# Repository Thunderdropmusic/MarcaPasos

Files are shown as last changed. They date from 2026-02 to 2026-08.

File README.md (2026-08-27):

# MARCAPASOS - THE ARDUINO MIDI SEQUENCER
Marcapasos_banner

🔗 Consulta la documentación técnica completa y detallada en mi página de Notion:

https://www.notion.so/MARCAPASOS-SEQUENCIADOR-MIDI-2cebd5980807801b87b1fa9e6536f0fe?source=copy_link
<!-- START_NOTION -->

Este es un proyecto realizado para la asignatura Laboratorio de Sonido II en la Esmuc. 

El Marcapasos es un secuenciador MIDI que funciona como un secuenciador analógico modular sin las limitaciones que supone tener todos los módulos que requiere un sintetizador modular.

Puedes encontrar como funciona cada apartado dando clic en los enlaces de las prestaciones.

Las prestaciones son todas aquellas características que me gustaría añadir en algún momento al dispositivo, aunque no sean posibles en los cuatro meses de la asignatura.

# **PRESTACIONES**

- [ ] **SINCRONIZACIÓN CON EL DAW**
  - [x] **Tempo**
  - [ ] Posición
  - [x] [**Subdivisiones:**](https://www.notion.so/36fbd598080780d9bde0de2cc4f7dc47)
    - [x] **Binarias **
    - [x] **Ternarias**
    - [x] **Compuestas**
  - [ ] Ligado de los pasos
  - [x] [**Decidir si recibe MIDI_CLOCK o si lo envía**](https://www.notion.so/36fbd598080780c8bdfbc918d2e3e9ef)
- [ ] **PASOS EDITABLES**
  - [x] [**Muteado de los pasos**](https://www.notion.so/36fbd598080780419057ef35fa2849cf)
  - [x] [**Edición del número de pasos (Max de 16)**](https://www.notion.so/36fbd59808078011a2aadc185fa75882)
  - [x] **Extender la secuencia a 32 mediante los botones de slot**
  - [ ] Extensión del paso
- [x] **CONTROL**
  - [x] **Potenciómetros para cada valor de la secuencia**
  - [x] [**Pulsadores para el muteado y desmuteado**](https://www.notion.so/36fbd598080780419057ef35fa2849cf)
  - [x] **Botones de control de la pantalla**
  - [x] [**Escoger fácilmente la octava de cada una de las notas**](https://www.notion.so/36fbd598080780fea1caeed5433170bc)
  - [x] [**Escoger fácilmente la velocity de cada una de las notas**](https://www.notion.so/36fbd598080780eea508ef71374ae587)
  - [x] Transportar según nota de entrada de otro controlador
  - [x] [**Mapear posición del potenciómetro a una escala**](https://www.notion.so/36fbd598080780b19d55cec38a8eafa3)
  - [x] **Botones para iniciar y parar la secuencia con leds que lo visualicen**
- [ ] **CONEXIONES**
  - [x] **USB**
  - [ ] Opcional DIN4
- [x] **ENVÍO**
  - [x] **Notas a diferentes alturas**
  - [x] [**Notas con diferentes velocidades**](https://www.notion.so/36fbd598080780eea508ef71374ae587)
  - [x] [**Control Change**](https://www.notion.so/36fbd598080780c189a0f2511ea4e083)
  - [x] [**Enviar varias secuencias a la vez**](https://www.notion.so/36fbd59808078066aa01e511496fedfd)
- [x] [**PRESETS**](https://www.notion.so/36fbd59808078064a17fe55298546050)
  - [x] **Guardar las secuencias y los patterns en una SD**
  - [x] **Guardar las secuencias en slots para cargarlas automaticamente**
# **MATERIAL NECESARIO**

1. x1 Arduino mega
1. x1 Pantalla I2C 20x4
1. x16 Potenciometros
1. x16 Botones para los mutes
1. x5 Botones para el play/stop de las secuencias
1. x3 Botones de control
1. 1x Encoder
1. x1 Mega Proto Shield
1. x40 Cables Dupont Macho-Macho
1. x40 Cables Dupont Macho-Hembra
1. x5 Resistencias para los leds
1. X5 Leds
1. Ribbon con clavija FC10P
1. Cables Dupont x50
# **SOFTWARE**

1. [LoopMidi](https://www.tobias-erichsen.de/software/loopmidi.html)
1. [HairLessMidi](https://projectgus.github.io/hairless-midiserial/)
1. [MIDI-OX](http://www.midiox.com/)
# **BIBLIOGRAFÍA**

## MIDI

[https://www.prometec.net/midi-conexiones-senales-mensajes/](https://www.prometec.net/midi-conexiones-senales-mensajes/)

[https://www.prometec.net/midi-recibir-manipular-mensajes/](https://www.prometec.net/midi-recibir-manipular-mensajes/)

[https://midi.org/expanded-midi-1-0-messages-list](https://midi.org/expanded-midi-1-0-messages-list)

[https://midi.org/spec-detail](https://midi.org/spec-detail)

[https://projectgus.github.io/hairless-midiserial/](https://projectgus.github.io/hairless-midiserial/)

## ARDUINO

[https://www.pjrc.com/teensy/td_libs_TimerOne.html](https://www.pjrc.com/teensy/td_libs_TimerOne.html)

[https://www.luisllamas.es/curso-arduino-iniciacion/](https://www.luisllamas.es/curso-arduino-iniciacion/)

[https://www.youtube.com/playlist?list=PL4_gPbvyebyH2xfPXePHtx8gK5zPBrVkg](https://www.youtube.com/playlist?list=PL4_gPbvyebyH2xfPXePHtx8gK5zPBrVkg)

[https://naylampmechatronics.com/blog/34_tutorial-lcd-conectando-tu-arduino-a-un-lcd1602-y-lcd2004.html](https://naylampmechatronics.com/blog/34_tutorial-lcd-conectando-tu-arduino-a-un-lcd1602-y-lcd2004.html)

[https://naylampmechatronics.com/blog/35_tutorial-lcd-con-i2c-controla-un-lcd-con-solo-dos-pines.html](https://naylampmechatronics.com/blog/35_tutorial-lcd-con-i2c-controla-un-lcd-con-solo-dos-pines.html)

[https://www.luisllamas.es/arduino-encoder-rotativo/](https://www.luisllamas.es/arduino-encoder-rotativo/)

[https://www.luisllamas.es/4-consejos-para-programar-codigo-mas-limpio-en-arduino/](https://www.luisllamas.es/4-consejos-para-programar-codigo-mas-limpio-en-arduino/)

[https://www.luisllamas.es/tarjeta-micro-sd-arduino/](https://www.luisllamas.es/tarjeta-micro-sd-arduino/)

# **SUBPÁGINAS DEL NOTION**

<!-- END_NOTION -->

esto es un pie de pagina

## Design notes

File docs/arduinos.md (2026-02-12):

# ARDUINOS

Arduino mega 2560 https://es.aliexpress.com/item/1005006332489610.html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

* pines digitales máximos: 52
* pines analógicos máximos: 16

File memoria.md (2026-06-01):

La memoria comienza antes de empezar las clases de la asignatura, pues se me recomendó empezar con tiempo porque el proyecto era bastante grande. 

## 17/01/2026

Primeras pruebas Midi. Se consigue por primera vez recibir mensajes Midi en el Arduino desde el DAW usando la librería Midi.h y el programa Hairless MIDI y se hacen las primeras pruebas de recepción del Midi Clock.

```javascript
#include <MIDI.h>
#include <TimerOne.h>

struct HairlessConfig : public midi::DefaultSettings {
  static const long BaudRate = 115200;
};

MIDI_CREATE_CUSTOM_INSTANCE(HardwareSerial, Serial, MIDI, HairlessConfig);
int tiempo;
volatile boolean notaFuera;
void setup() {
  MIDI.begin(MIDI_CHANNEL_OMNI);
  MIDI.turnThruOff();
}
```

## 3/2/2026

Primera presentación del proyecto 

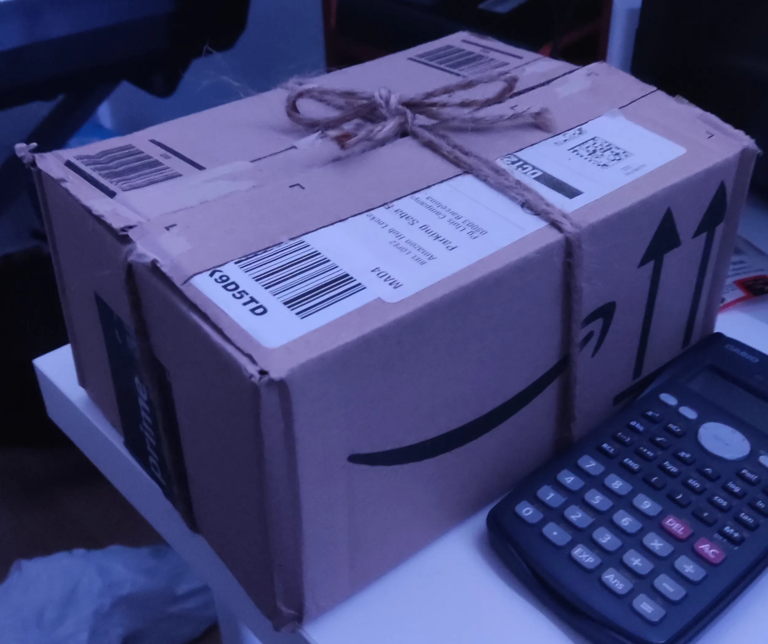
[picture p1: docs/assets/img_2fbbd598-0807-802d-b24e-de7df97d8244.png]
Una caja
<div style="margin-bottom: 20px;"><p style="margin-top: 0px;"><sub><i>Una caja</i></sub></p></div>

## 10/02/2026

Se ha conseguido añadir hasta ocho potenciómetros y se ha empezado a trabajar la programación del muteado de los pasos. Tambien se ha conseguido editar la longitud de la secuencia desde el Arduino:

📄 [Edición del número de pasos (Max de 16)](https://www.notion.so/303bd598080780b78244d991088aca70)

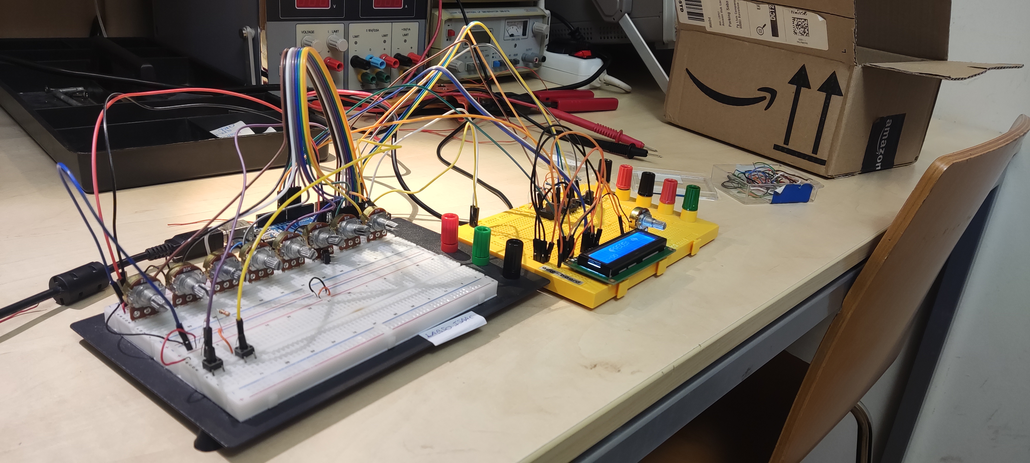
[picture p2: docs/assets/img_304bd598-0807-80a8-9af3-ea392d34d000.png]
Protoboard en la fecha de la memoria
<div style="margin-bottom: 20px;"><p style="margin-top: 0px;"><sub><i>Protoboard en la fecha de la memoria</i></sub></p></div>

## 17/02/2026

Se han añadido 8 botones para mutear cada uno de los potenciómetros independientemente.

📄 [Muteado de los pasos](https://www.notion.so/304bd5980807806a8955d3bfb23b4774)

También, se ha optimizado el código de dibujado de la pantalla para que solo cambie los caracteres que se mueven y no que redibuje todo cada vez que haces un cambio. Esto sobre todo es importante en el visionado de los pasos:

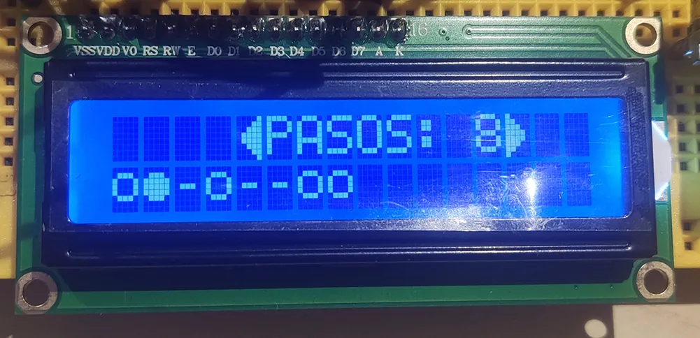
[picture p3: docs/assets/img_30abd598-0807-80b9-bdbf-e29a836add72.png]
Visionado de los pasos
<div style="margin-bottom: 20px;"><p style="margin-top: 0px;"><sub><i>Visionado de los pasos</i></sub></p></div>

```c++
inline void drawSteps() {
  if(mutesValue[nStep]){
    if(mutesValue[nStepAnterior]){
      lcd.setCursor(nStepAnterior, 1);
      lcd.write(byte(5));
      lcd.setCursor(nStep,1);
      lcd.write(byte(5));
    }
    else if(!mutesValue[nStepAnterior]){
      lcd.setCursor(nStepAnterior, 1);
      lcd.write(byte(6));
      lcd.setCursor(nStep,1);
      lcd.write(byte(5));
    }
  }
  else if(!mutesValue[nStep]){
    if(mutesValue[nStepAnterior]){
      lcd.setCursor(nStepAnterior, 1);
      lcd.write(byte(5));
      lcd.setCursor(nStep,1);
      lcd.write(byte(7));
    }
    else if(!mutesValue[nStepAnterior]){
      lcd.setCursor(nStepAnterior, 1);
      lcd.write(byte(6));
      lcd.setCursor(nStep,1);
      lcd.write(byte(7));
      
    }
  }
  nStepAnterior = nStep;
}
```

Se ha empezado también a trabajar la cuantización a escala y poder escoger desde los potenciómetros, notas que pertenezcan a la escala escogida:

```c++
int escalaSeleccionada = 1;
const int escalasNotas[5][13] = {
  {0, 1, 2, 3, 4, 5, 6, 7, 8, 9, 10, 11, 12}, //Escala cromática
  {0, 2, 3, 5, 7, 8, 10, 12, 0, 0, 0, 0, 0}, //Escala menor Natural
  {0, 2, 4, 5, 7, 9, 11, 12, 0, 0, 0, 0, 0}, //Escala Mayor
  {0, 2, 4, 6, 8, 10, 12, 0, 0, 0, 0, 0, 0}, //Escala de tonos
  {0, 1, 3, 4, 6, 7, 9, 10, 12, 0, 0, 0, 0} //Escala Semitono-tono
};
const int nNotasEscalas[5] = {13, 8, 8, 7, 9};

[...]

  for(int i = 0; i < numPotes; i++){
    int indice = constrain(map(analogRead(potesPin[i]), 1018, 30, 0, nNotasEscalas[escalaSeleccionada] - 1), 0, nNotasEscalas[escalaSeleccionada] - 1);
    int val = escalasNotas[escalaSeleccionada][indice];
```

Tambien se ha empezado a trabajar la gestión de las octavas, pudiendo ahora transportar toda la secuencia octavas hacia arriba y hacia abajo pulsando los botones de mute 1, 2 y 3, 4 respectivamente a la vez:

```c++
      if(mutePulsado[0] && mutePulsado[1] && octava < 9 && tiempoActualMillis - ultimoTiempoBotonMute[0] > 250 && tiempoActualMillis - ultimoTiempoBotonMute[1] > 250){
        octava ++;
        ultimoTiempoBotonMute[0] = tiempoActualMillis;
        ultimoTiempoBotonMute[1] = tiempoActualMillis;
        timeShowOctValue = tiempoActualMillis;
        menuActual = 4;
        updateLCD = true;
      }
      else if(mutePulsado[2] && mutePulsado[3] && octava > 0 && tiempoActualMillis - ultimoTiempoBotonMute[2] > 250 && tiempoActualMillis - ultimoTiempoBotonMute[3] > 250){
        octava --;
        ultimoTiempoBotonMute[2] = tiempoActualMillis;
        ultimoTiempoBotonMute[3] = tiempoActualMillis;
        timeShowOctValue = tiempoActualMillis;
        menuActual = 4;
        updateLCD = true;
      }
      else if(tiempoActualMillis - TiempoPulsadoBotonMute[i] > 100 && tiempoActualMillis - ultimoTiempoBotonMute[i] > 250){
        mutesValue[i] = !mutesValue[i];
        ultimoTiempoBotonMute[i] = tiempoActualMillis;
        updateLCD = true;
```

Tambien se ha organizado la carpeta SRC del GitHub por versiones añadiendo un log por cada una para ver los cambios. Ese log está hecho con gemini pasándole la versión nueva y que analice que cambia con la versión antigua..

## 24/02/2026

Se ha conseguido cambiar los valores de la velocity individualmente pulsando el boton mute y girando el pote, así como cambiar la octava por cada una de las notas de la secuencia convirtiendo los botones en un selector:

📄 [Escoger fácilmente la octava de cada uno de los potenciometros](https://www.notion.so/30cbd5980807801a8d3bca6844b82bbb)

📄 [Escoger fácilmente la velocity de cada una de las notas](https://www.notion.so/313bd5980807800ca0a0ca5a68b020ec)

Se ha hecho una Reunión con el profesor para determinar hacia donde caminar: el siguiente paso es cambiar la manera en la que se detectan los potenciómetros, haciendo una comparativa de los valores reales de los potenciómetros y no de su valor convertido a notas.

Se ha hablado como organizar la construcción de prototipo, en especial de los botones. Se compraran varios paneles pcb para conectar las tierras de los botones.

## 03/03/2026

Se ha reestructurado todo el código, convirtiendo cada archivo .h en una clase con sus variables y sus funciones para mejor entendimiento. De esta manera tenemos los siguientes archivos:

El archivo que más cambios ha presentado ha sido midiProgramming, pues se ha convertido su clase en un objeto para poder ser lanzado varias veces sin depender de arrays y manteniendo los valores de las variables en cada gestión de la secuencia. De esta manera, cada secuencia tiene una cantidad de pasos, una subdivisión y un modo de subdivisión completamente independientes.

Puedes ver como funciona mejor en la siguiente página de notion:

Para ello también, se han convertido las variables de la secuencia (noteValue[], velocityValue[], subdivision] en arrays (los que ya eran arrays, en matrices 2d) donde cada indice son los valores de cada secuencia:

## 11/03/2026

Se ha conseguido implementar definitivamente varias secuencias a la vez con un control de play, stop y un modo de subdivisión completamente independientes, pudiendo escoger secuencias con subdivisión simple y otras compleja. 

También se ha implementado un modo de MidiClock, pudiendo tanto recibirlo y sincronizarse con el DAW o enviarlo y que el propio marcapasos sincronice el DAW. Puedes encontrar más información en la siguiente pagina:

Tambien se ha realizado el trabajo de limpiar el código convirtiendo variables de int a byte para liberar memoria reduciéndola un 15% y una liberación de procesamiento dejando que las tareas pesadas como la pantalla o la lectura de potenciómetros lo haga una sola vez.

## 17/03/2026

Se ha seguido limpiando el código generando funciones para tareas que se realizan en muchos momentos del código, favoreciendo la lectura y la organización. 

Se está trabajando en la incorporación del sistema de envío de mensajes CC. Por cada secuencia, puedes escoger si será una secuencia de notas o una secuencia de automatización.

El funcionamiento será el siguiente. Cada potenciómetro tendrá un valor de 0 a 127 y se realizará una interpolación entre cada uno de los valores de 24 puntos (uno por cada mensaje MidiClock que recibe). Además, tambien se ha añadido la función de poder editar la curva de la interpolación, de manera más exponencial o logarítmica.

La idea futura es que funcione como un clip de automatización donde cada uno de los steps sean los puntos de la automatización y con los mutes vayas activando cada uno de los puntos. 

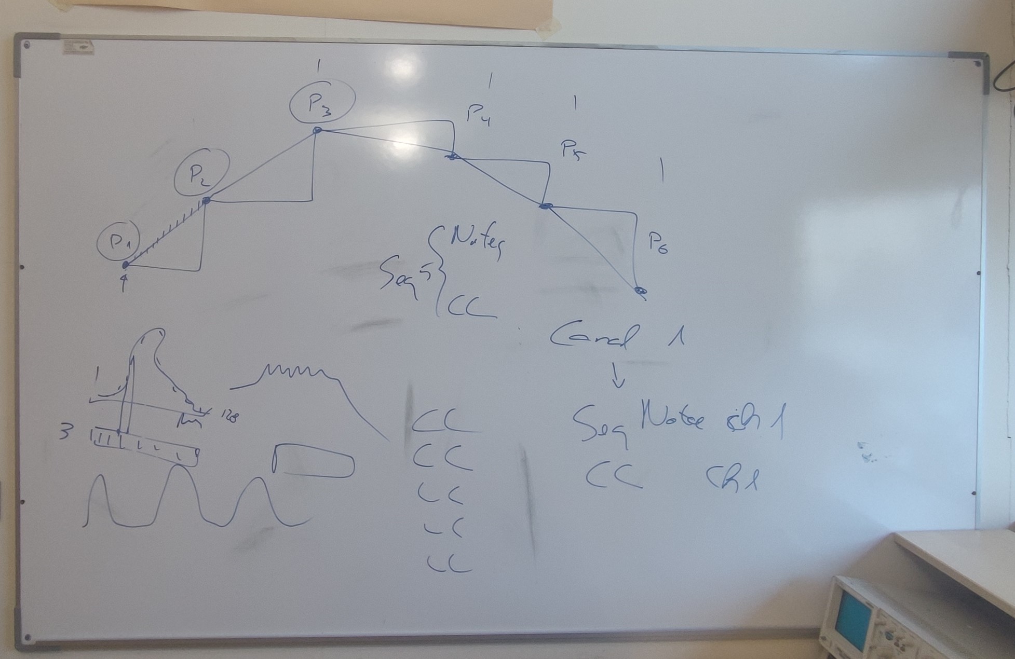
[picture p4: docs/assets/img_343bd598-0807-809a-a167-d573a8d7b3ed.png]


También, se han añadido unos leds para saber que secuencia está reproduciendose:

## 24/03/2026

Con la llegada de nuevos componentes, se ha cambiado la pantalla de 16x2 a una pantalla de 20x4 con chip i2c. 

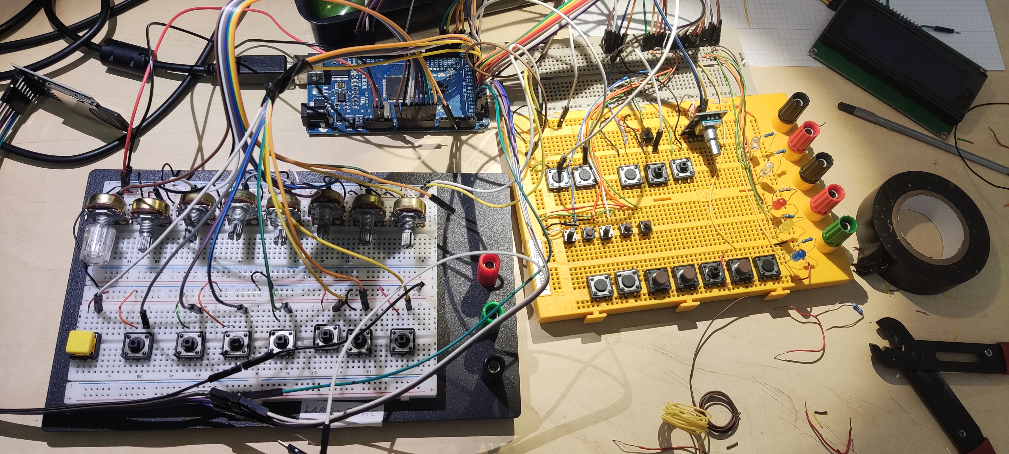
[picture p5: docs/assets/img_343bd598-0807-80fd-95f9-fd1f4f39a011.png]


Tambien, se ha conseguido llevar a cabo la interpolación de los diferentes puntos midi CC, además de poderlo ver de forma intuitiva en la pantalla

## SEMANA SANTA

Se ha construido la caja y la placa para el instrumento y se han hecho los agujeros por donde estarán todos los componentes con los que interactuar

## 14/04/2026 - 21/04/2026

Se han conseguido añadir la opción de transportar la secuencia cuando se envía una nota desde un controlador externo.

Tambien, se ha eliminado uno de los slots para convertirlo en un botón para añadir una extensión a la secuencia.

Se han pegado los componentes a la placa.

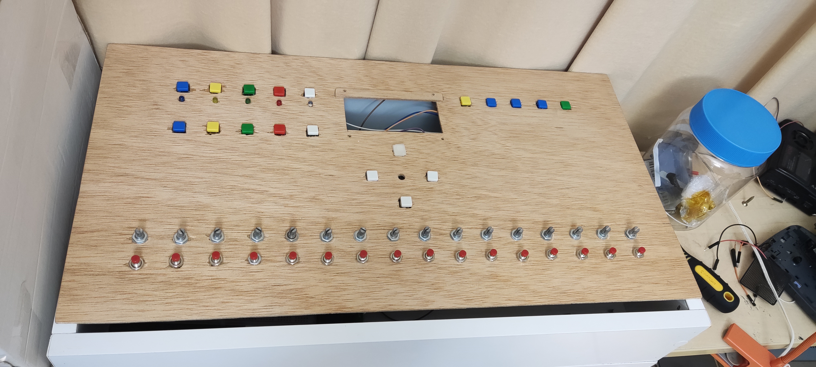
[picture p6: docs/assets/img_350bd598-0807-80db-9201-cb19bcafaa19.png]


## 02/05/2026 - 26/05/2026

En este mes, me he centrado en realizar la soldadura y montaje de la infercifie. Ha quedado de la siguiente manera:

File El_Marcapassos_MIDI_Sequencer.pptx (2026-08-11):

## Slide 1

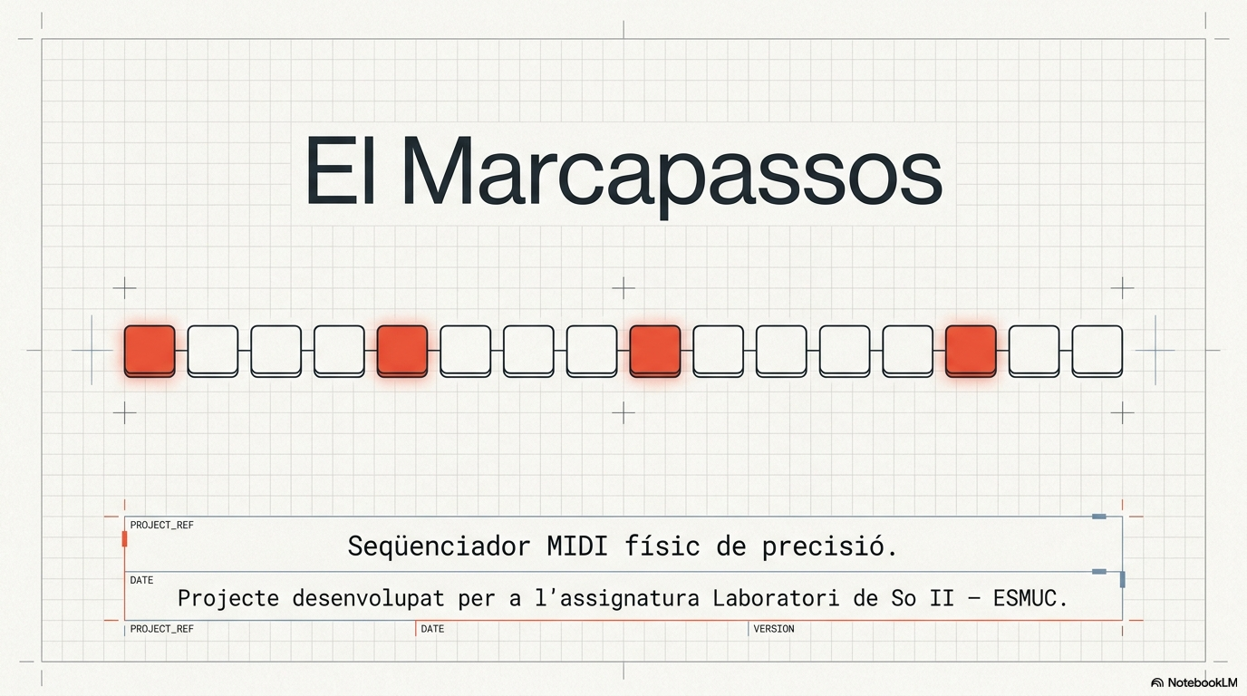
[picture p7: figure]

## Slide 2

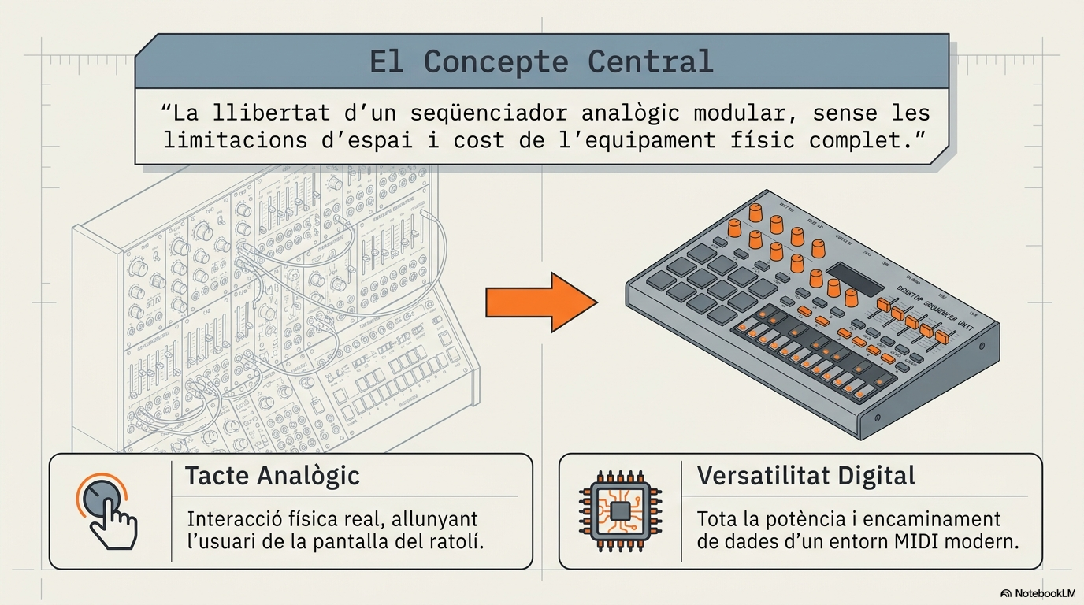
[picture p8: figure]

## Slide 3

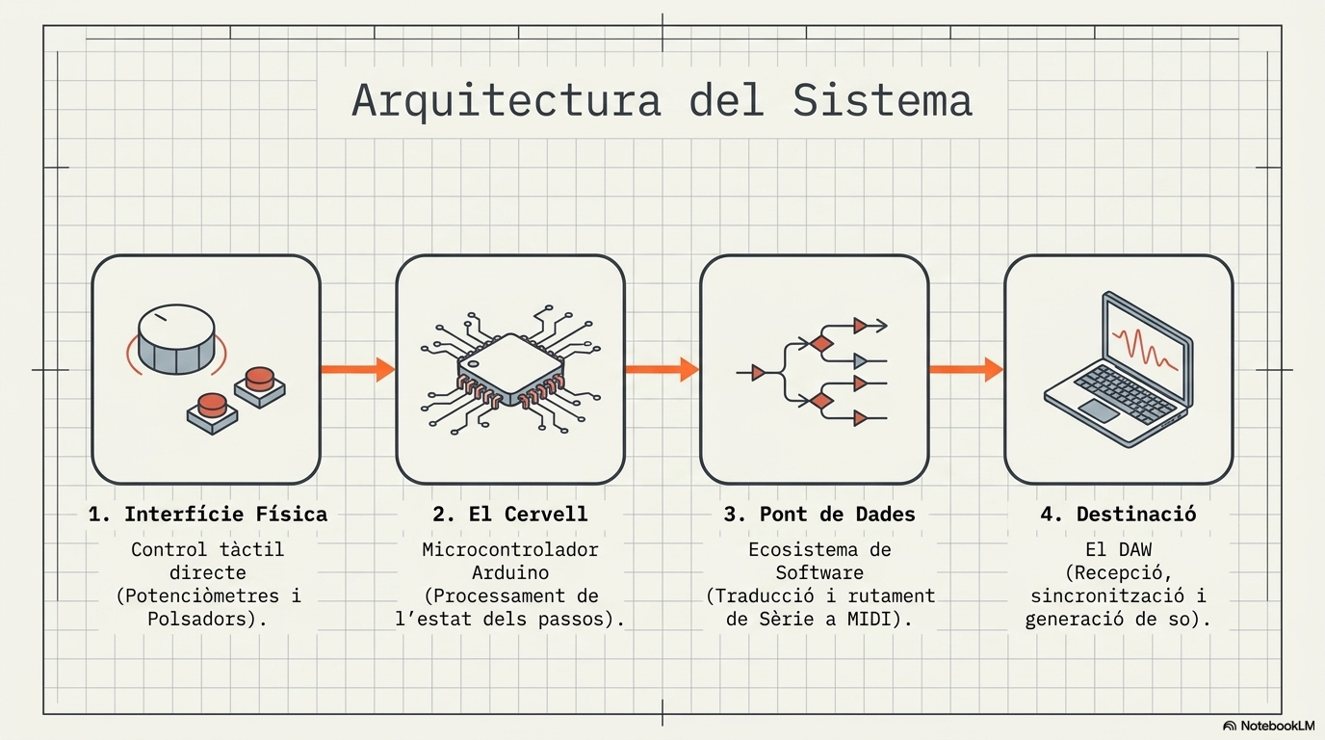
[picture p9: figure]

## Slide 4

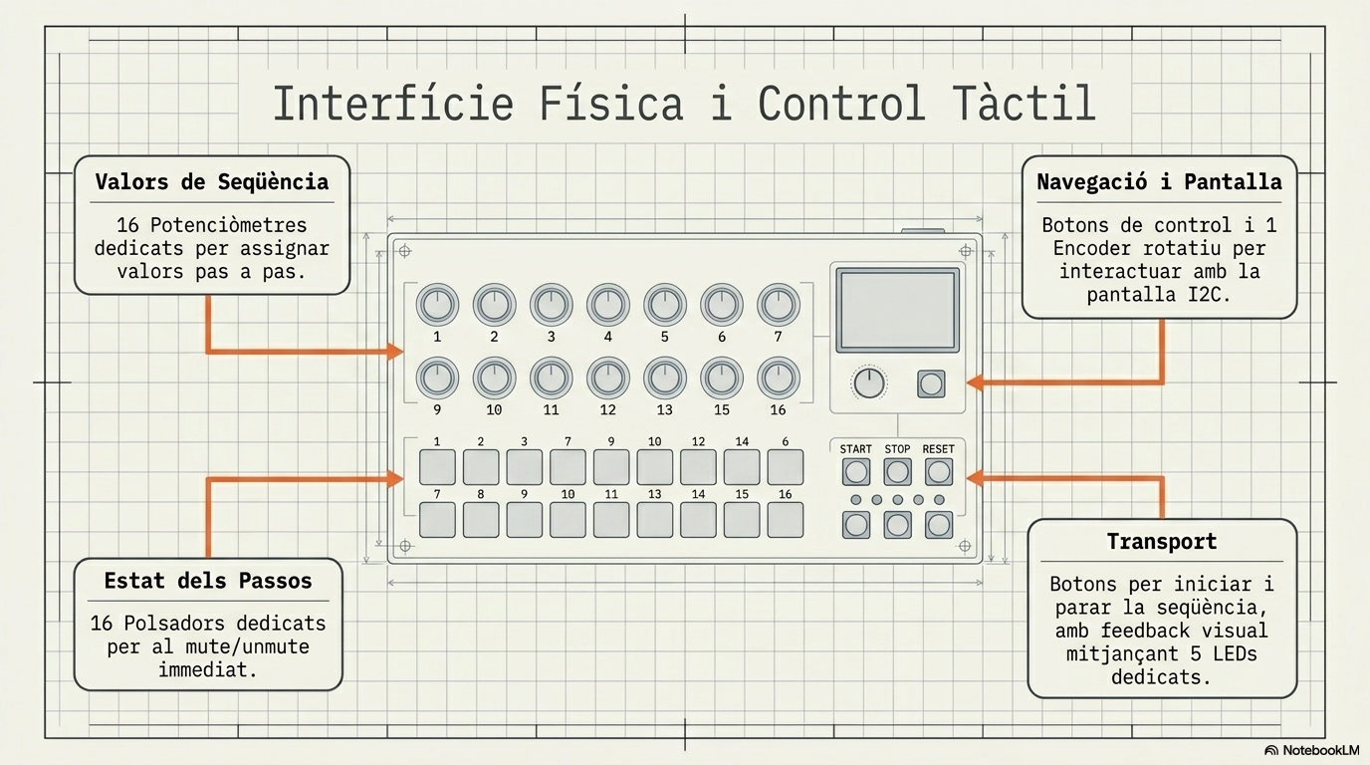
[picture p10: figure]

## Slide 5

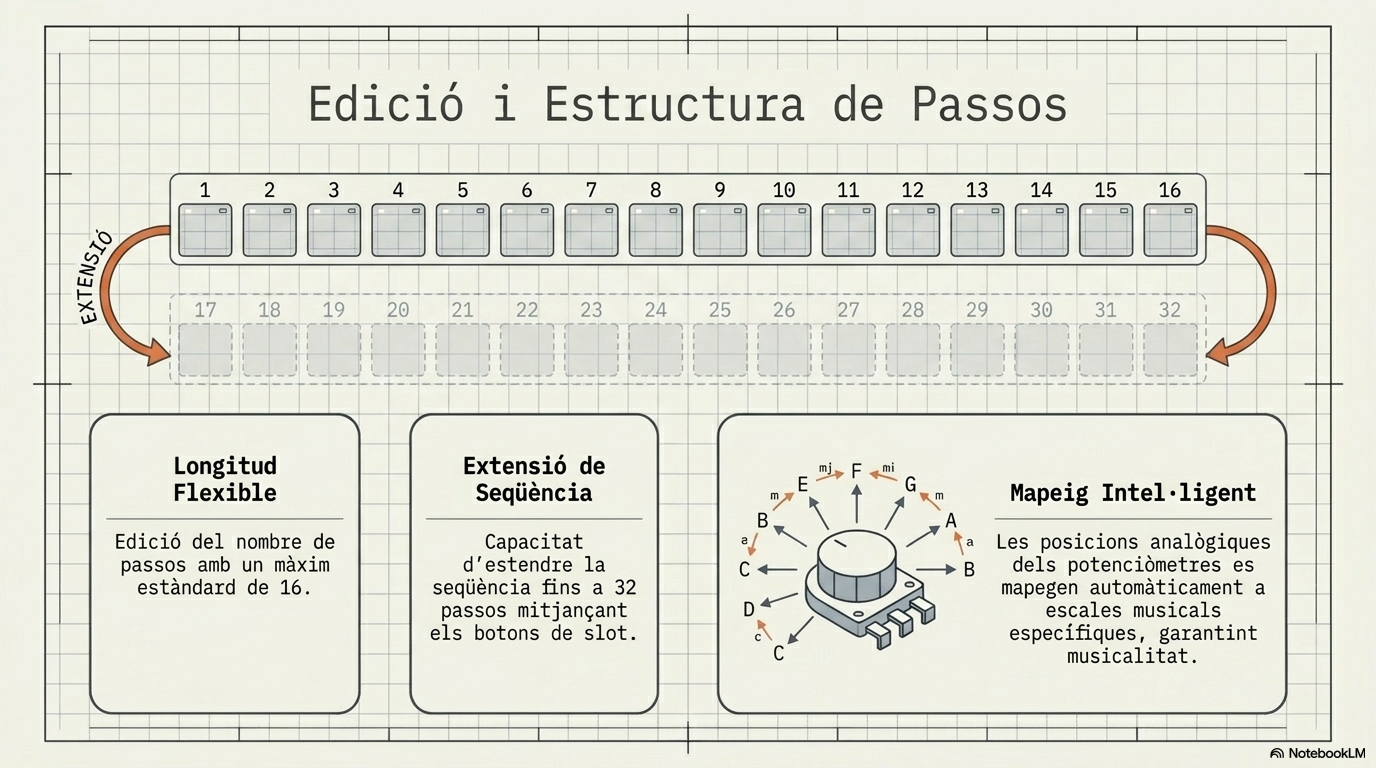
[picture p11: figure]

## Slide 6

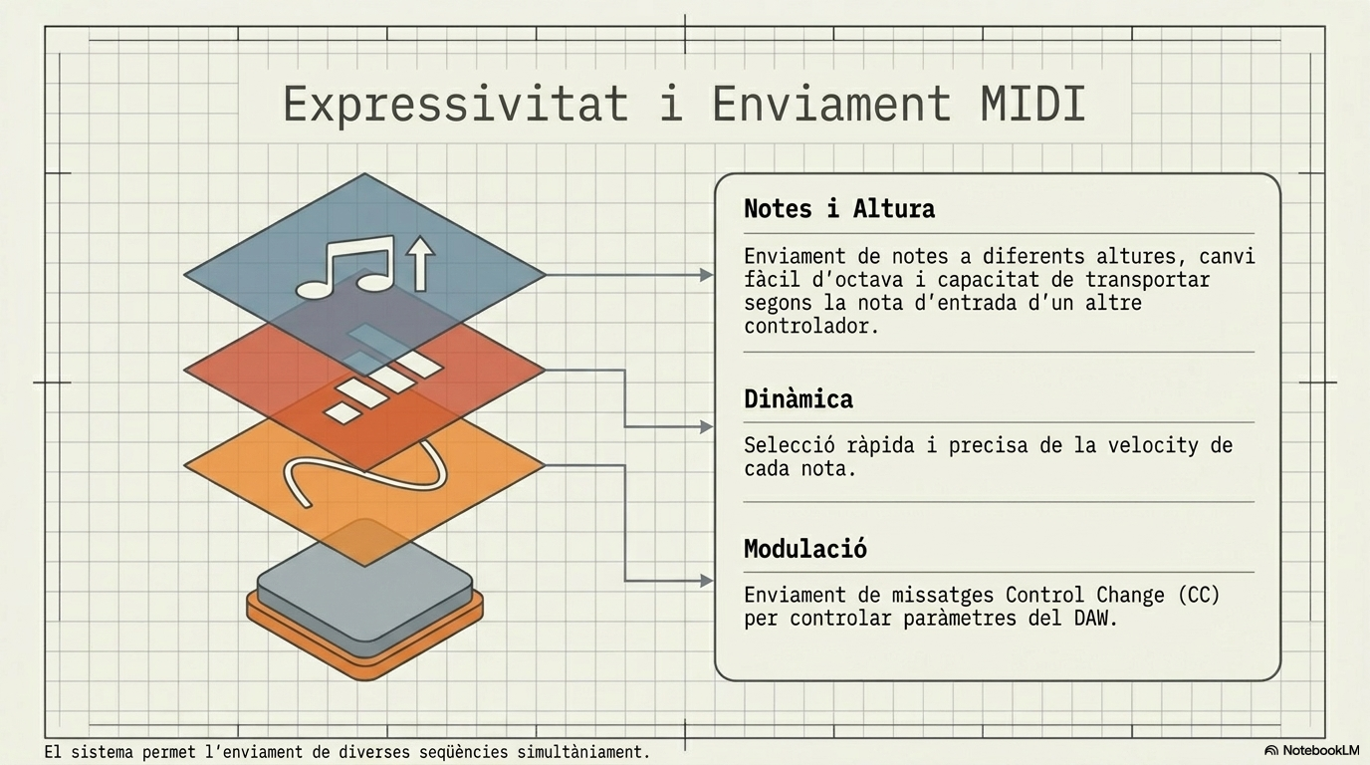
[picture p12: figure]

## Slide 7

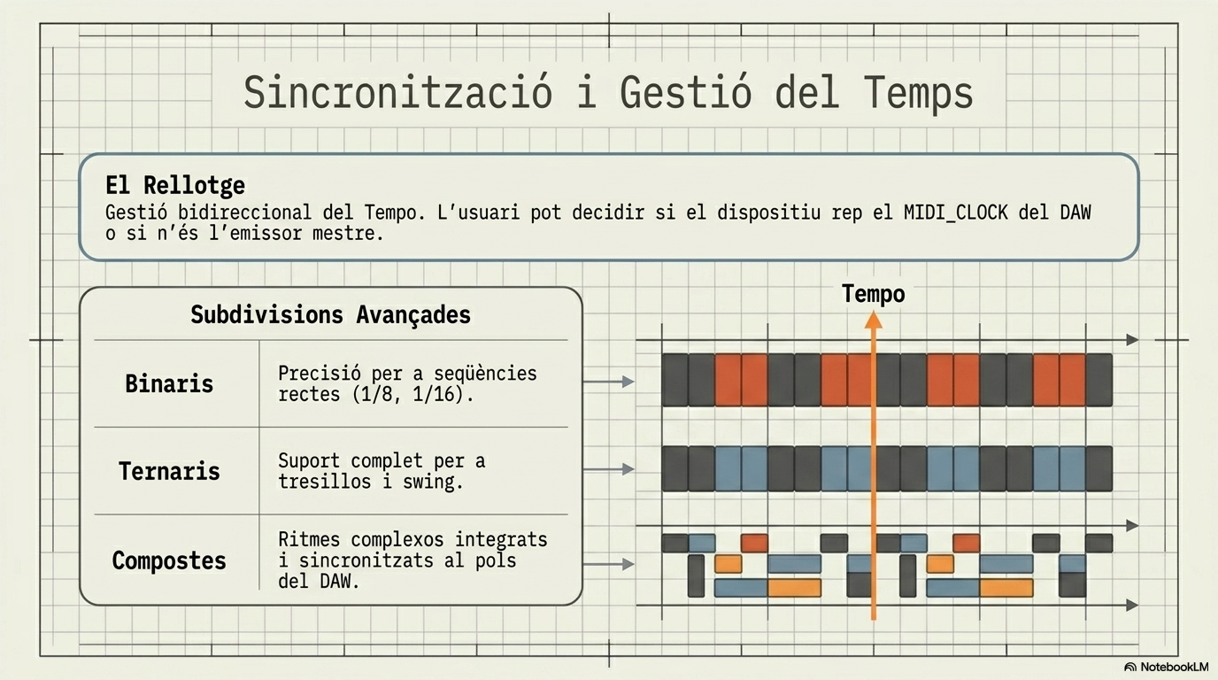
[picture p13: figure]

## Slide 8

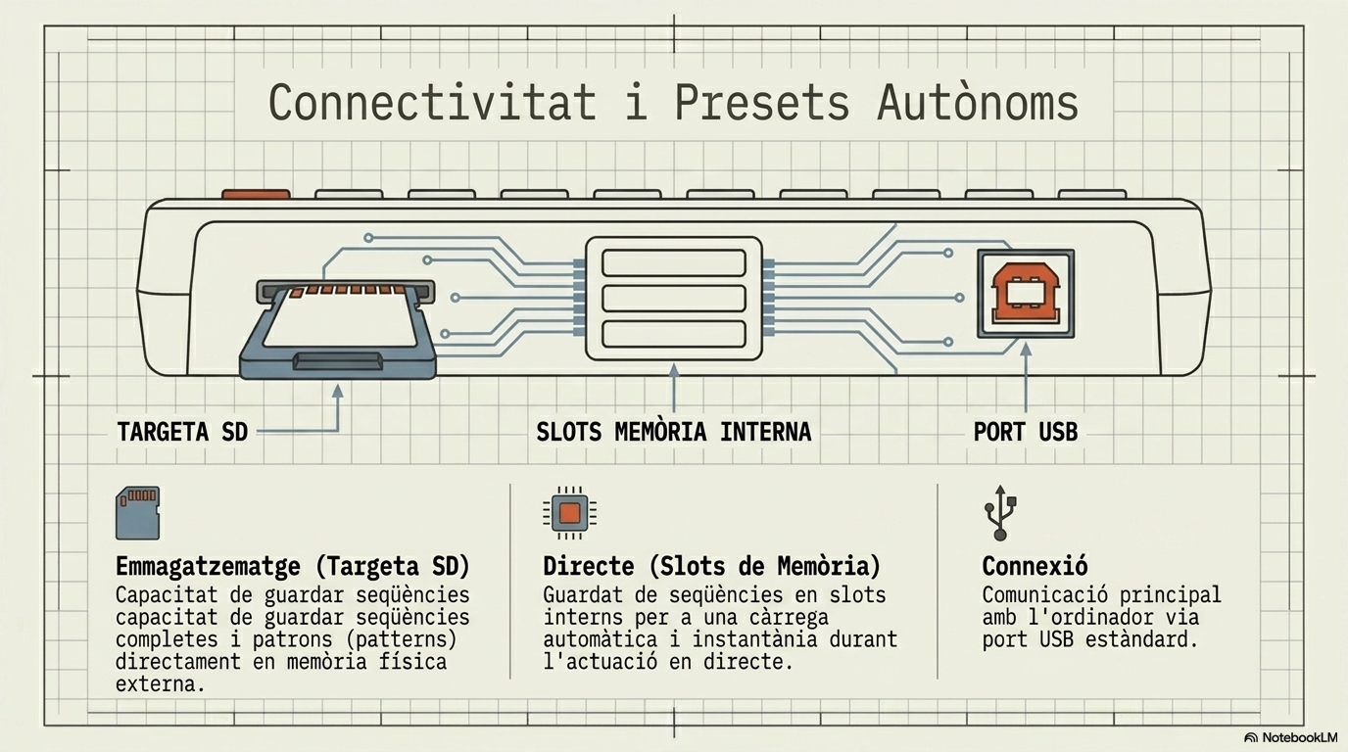
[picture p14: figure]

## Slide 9

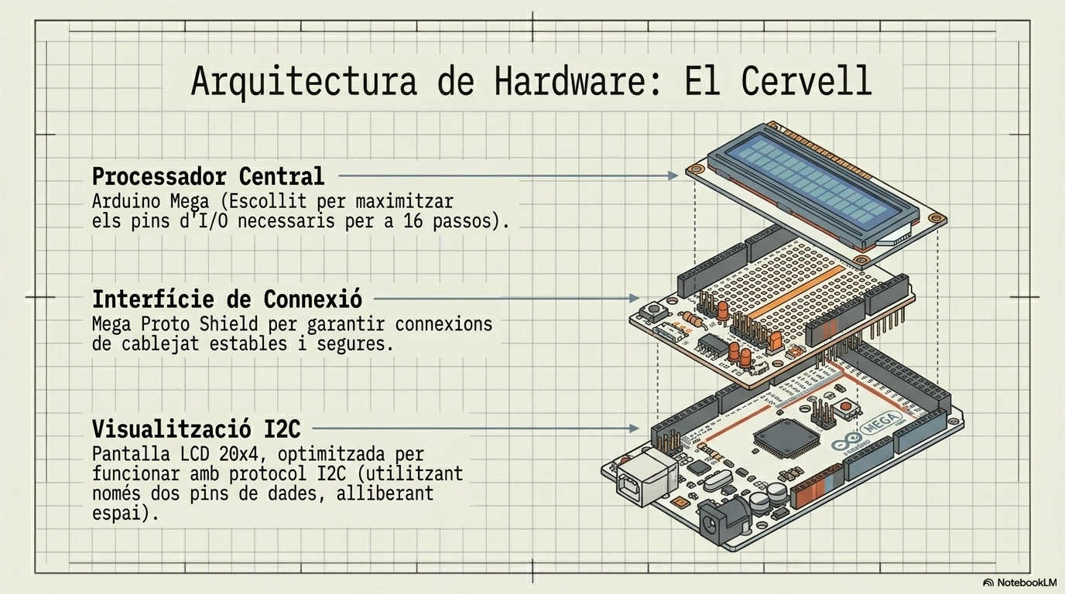
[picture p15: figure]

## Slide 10

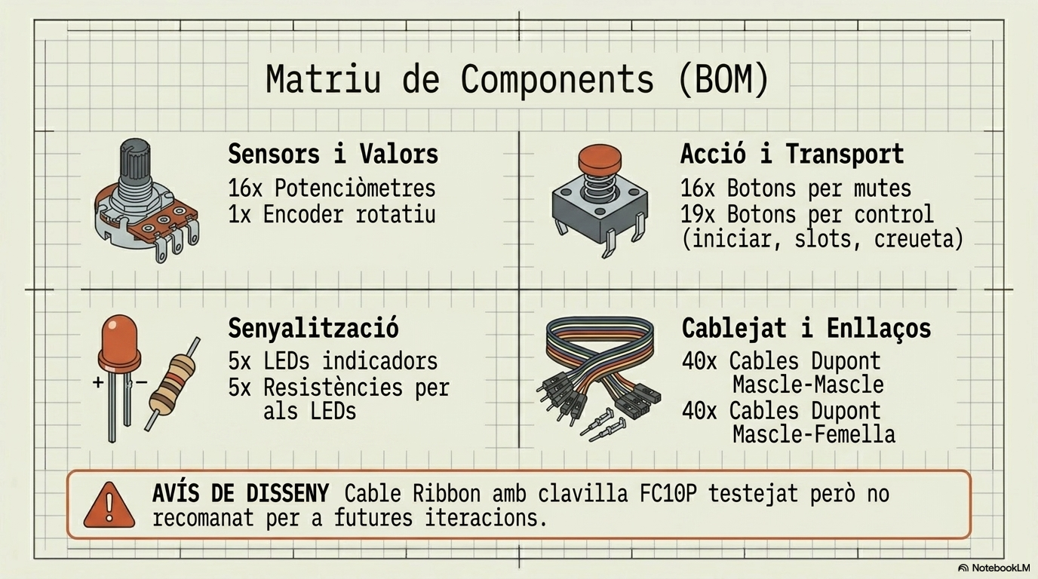
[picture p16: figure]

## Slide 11

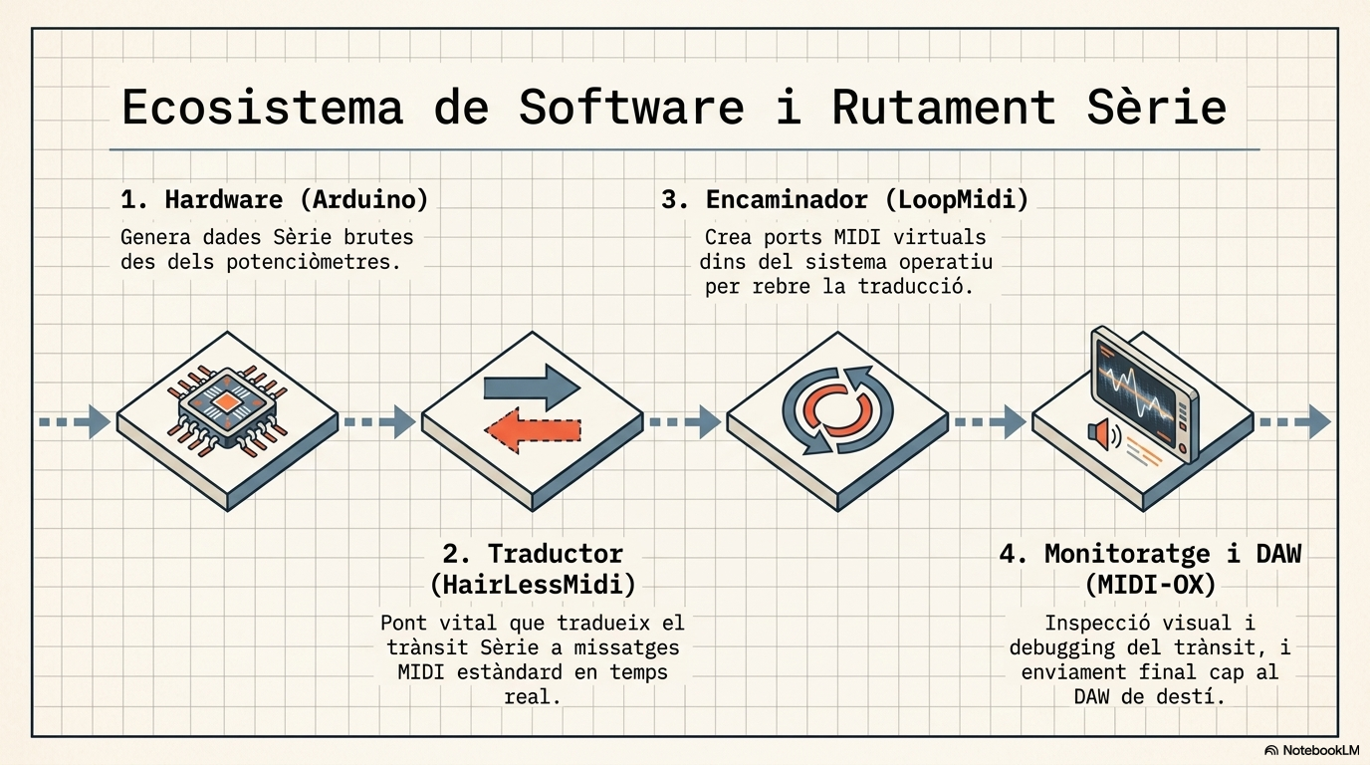
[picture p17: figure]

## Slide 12

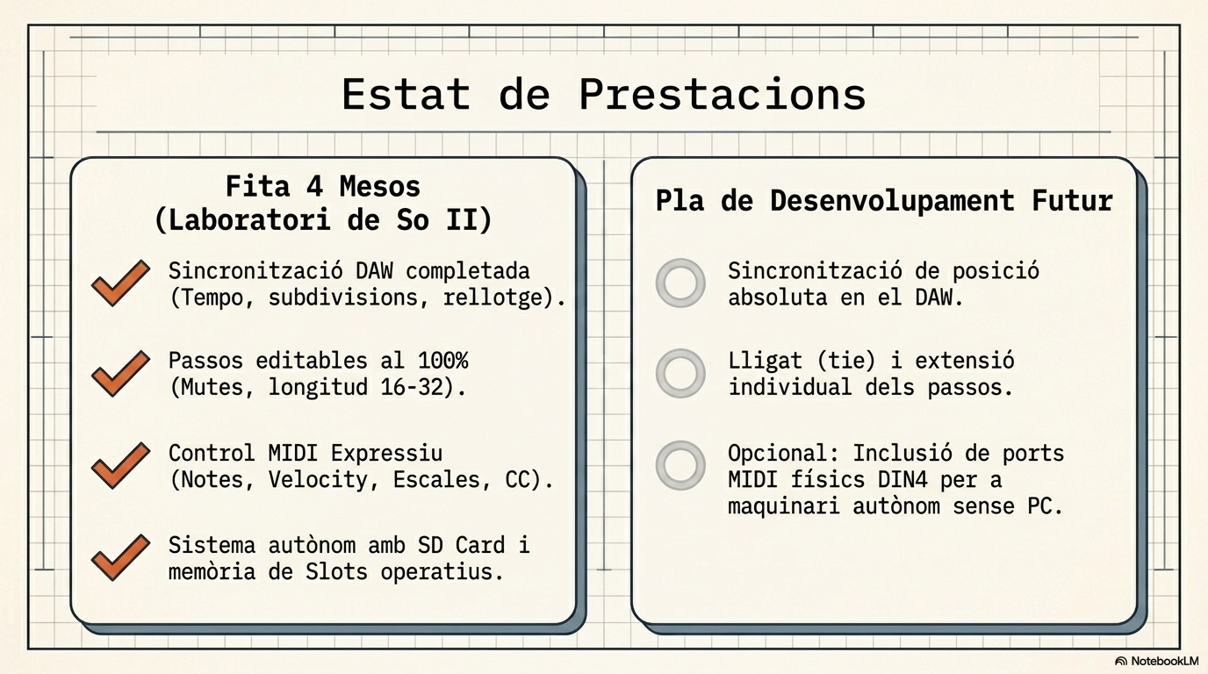
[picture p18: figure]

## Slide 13

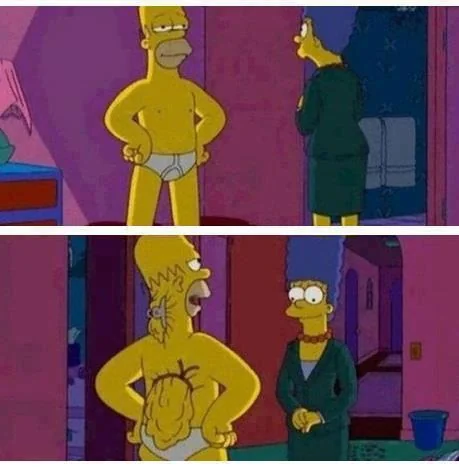
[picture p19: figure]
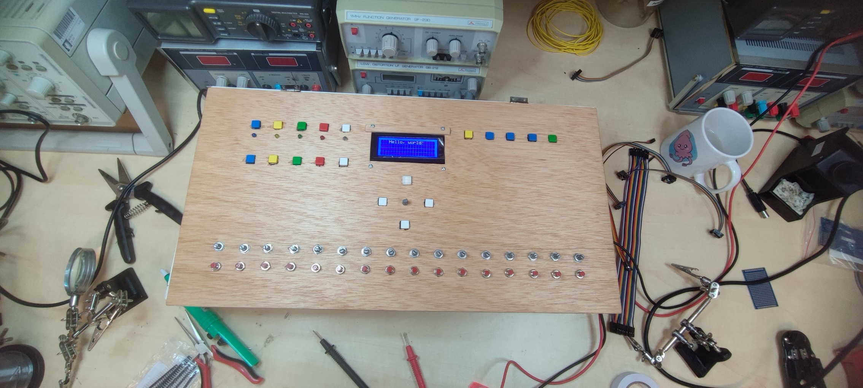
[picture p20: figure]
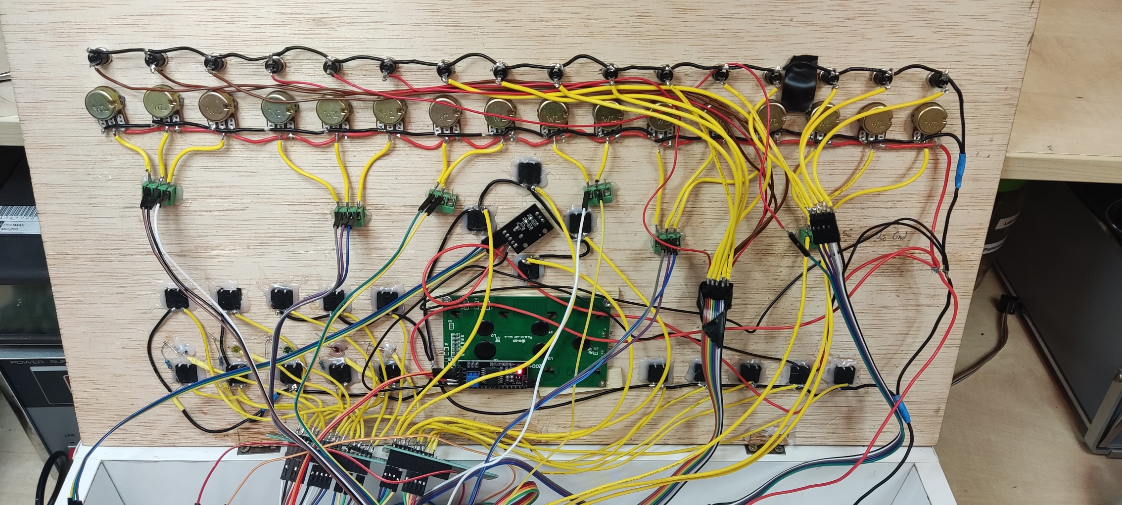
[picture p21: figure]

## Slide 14

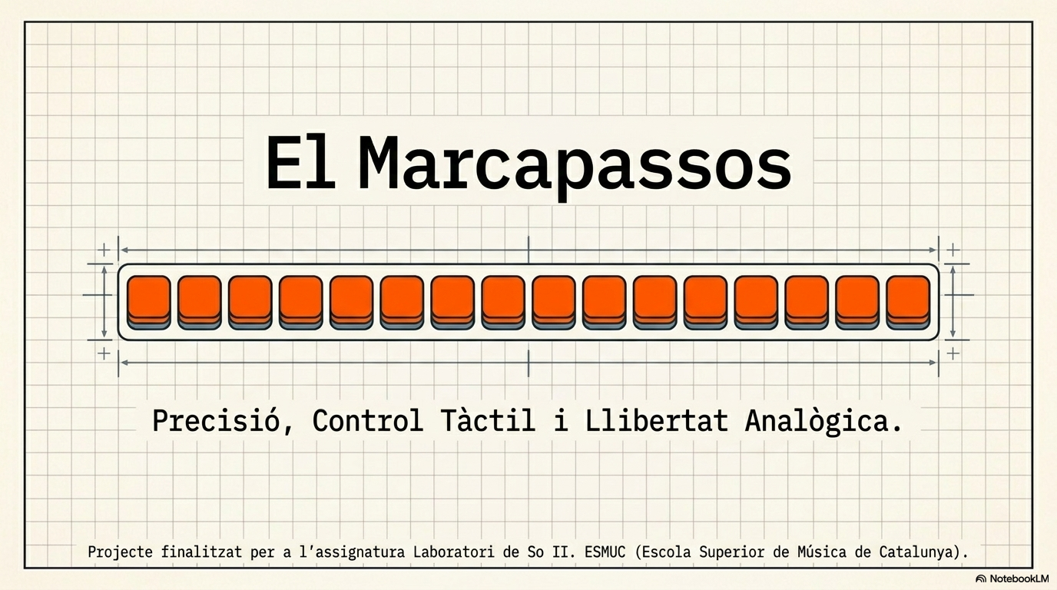
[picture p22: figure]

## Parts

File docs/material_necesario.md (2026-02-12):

# MATERIAL NECESARIO

1. Arduino mega
1. Pantalla ICS 
1. 16 Interruptores
1. 16 potenciometros
1. botones de control
1.

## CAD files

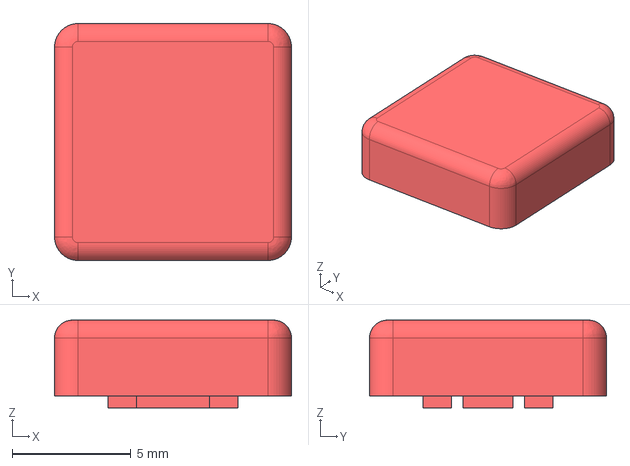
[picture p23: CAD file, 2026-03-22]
Planos/b3f4050-omron-12x12x7-3-button-1.snapshot.3/omrpnb3f4050-cap.step
10.0 x 10.0 x 3.70 mm

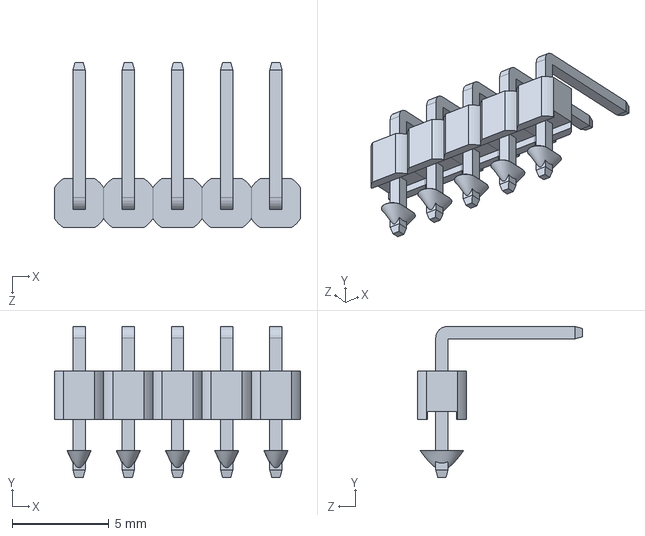
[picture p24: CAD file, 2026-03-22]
Planos/ky-040-enkoder-s-tlacitkem-1.snapshot.1/Kolíková lišta úhlová R2 krátká - 2,54mm.SLDPRT
12.7 x 7.80 x 8.54 mm

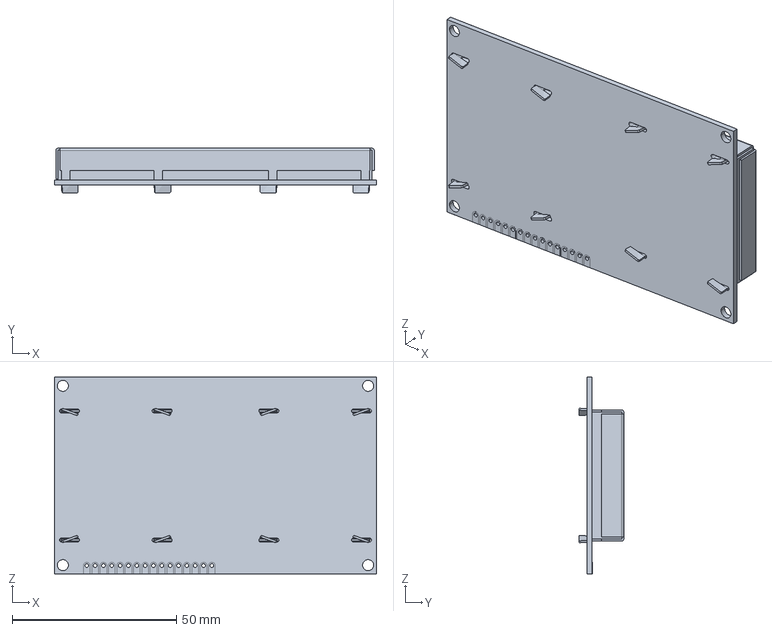
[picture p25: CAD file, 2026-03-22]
Planos/lcd-20x4-display-hd44780-arduiono-raspberry-pi-1.snapshot.1/lcd20x4hd44780.stp
98.1 x 13.7 x 59.9 mm

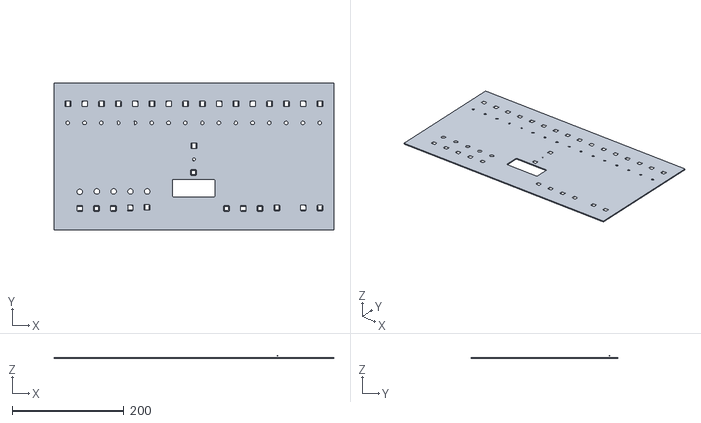
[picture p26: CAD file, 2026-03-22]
Planos/MarcaPasos_Agujeros.stl
500.0 x 261.8 x 5.00

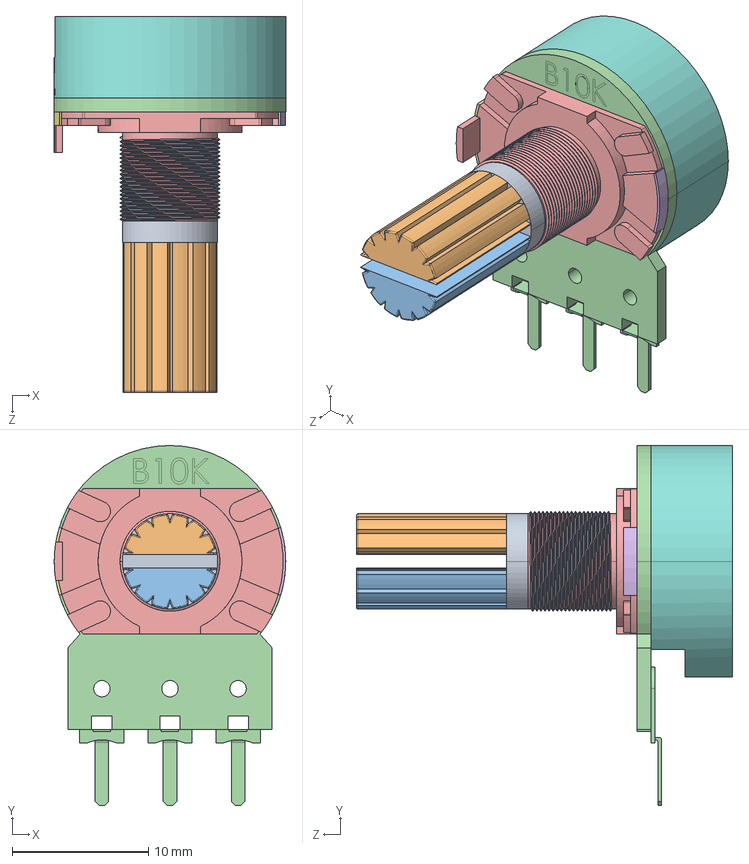
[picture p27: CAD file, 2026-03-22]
Planos/potentiometer-step-1.snapshot.1/PotentiometerB10K.STEP
17.0 x 26.4 x 27.6 mm

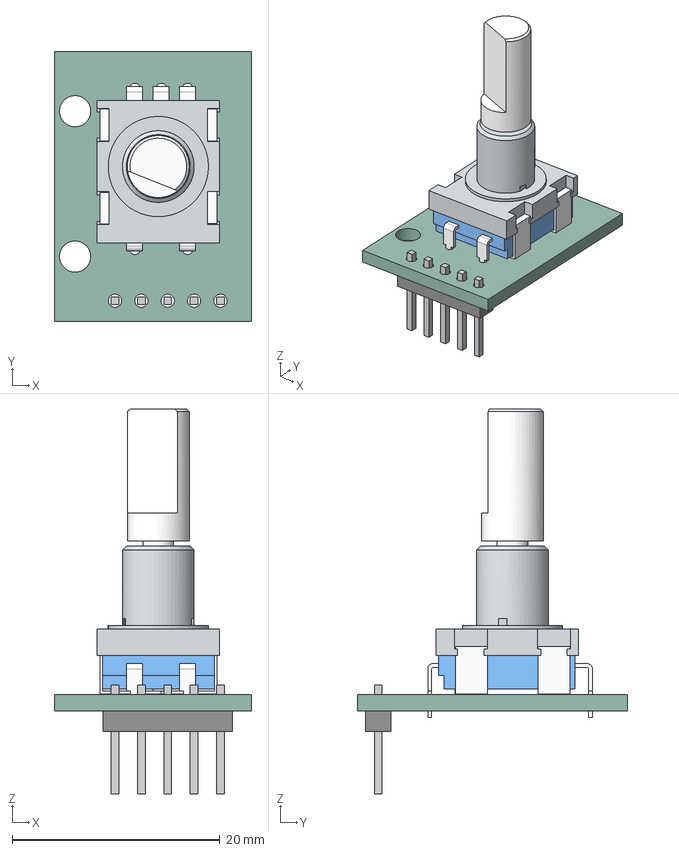
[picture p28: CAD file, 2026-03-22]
Planos/rotary-encoder-arduino-daughter-board-1.snapshot.3/MY_Rotary_encoder.step
19.0 x 26.0 x 37.1 mm
mtg flange
pins_encoder body_2 x 5
shaft_encoder
body_encoder

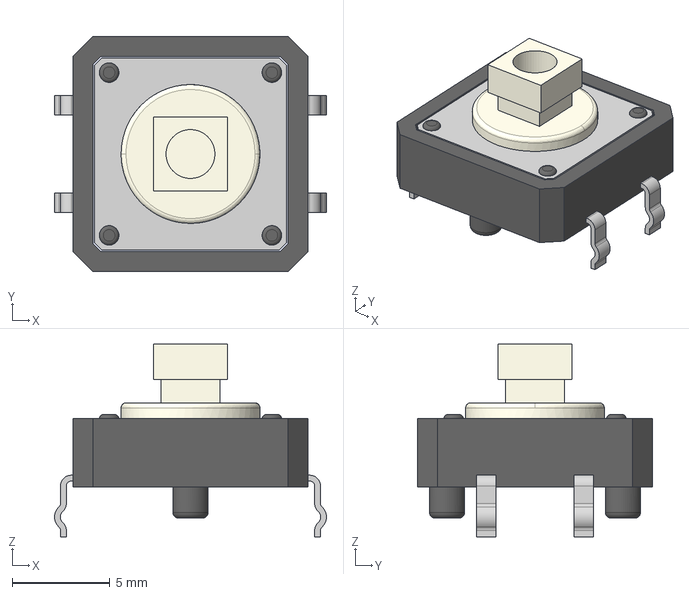
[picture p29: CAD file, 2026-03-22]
Planos/b3f4050-omron-12x12x7-3-button-1.snapshot.3/omrpnb3f4050.step
13.9 x 12.0 x 9.85 mm

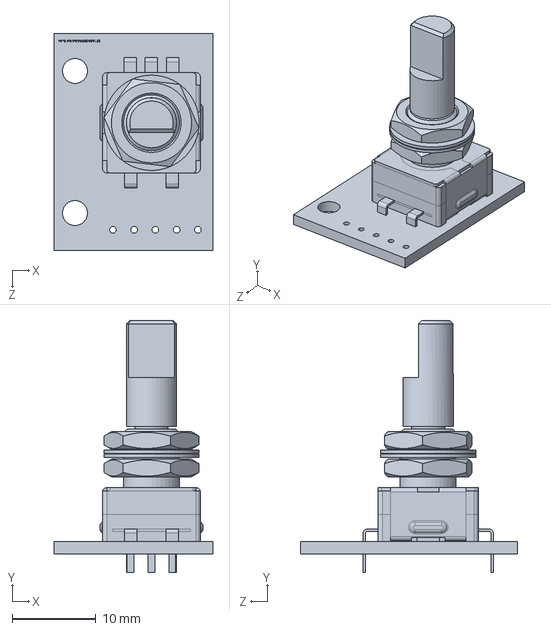
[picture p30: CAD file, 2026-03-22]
Planos/ky-040-enkoder-s-tlacitkem-1.snapshot.1/KY-040 (M495) - Rotační enkodér s ptlačítkem.SLDPRT
19.0 x 30.1 x 26.0 mm

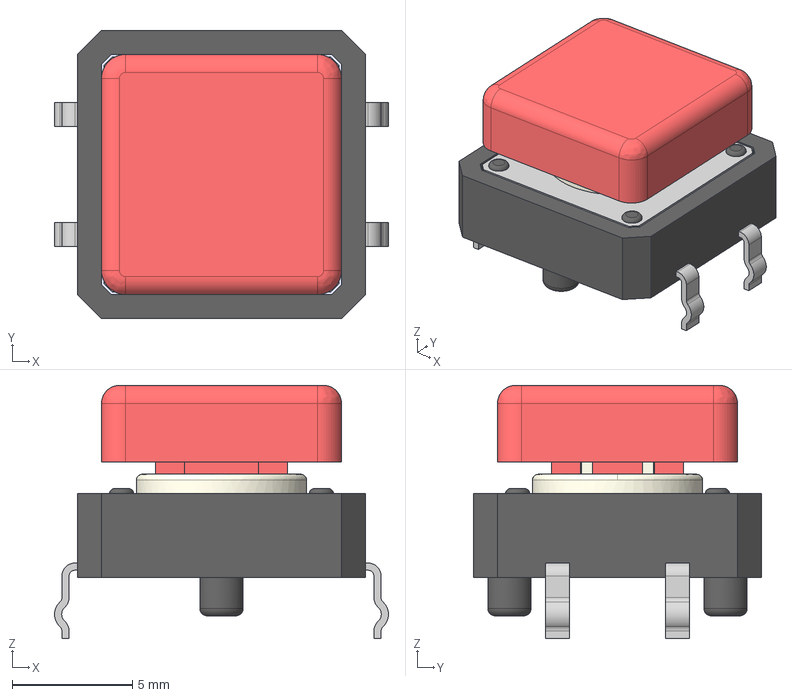
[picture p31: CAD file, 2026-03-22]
Planos/b3f4050-omron-12x12x7-3-button-1.snapshot.3/omrpnb3f4050wCap.step
13.9 x 12.0 x 10.5 mm
Cap
Button

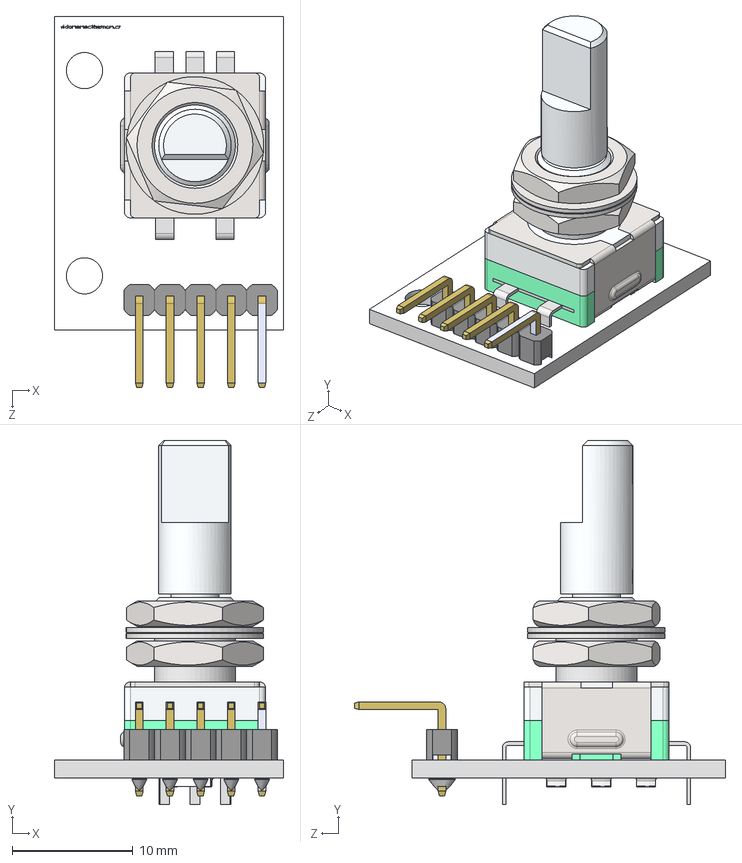
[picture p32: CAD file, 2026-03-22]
Planos/ky-040-enkoder-s-tlacitkem-1.snapshot.1/KY-040 - Rotační enkodér s tlačítkem, 20pulz_ot..STEP
19.0 x 30.1 x 30.8 mm
KY-040 (M495) - Rotaèní enkodér s ptlaèítkem
Kolíková lišta úhlová R2 krátká - 2,54mm_5
SMD rezistory_1206 x 3

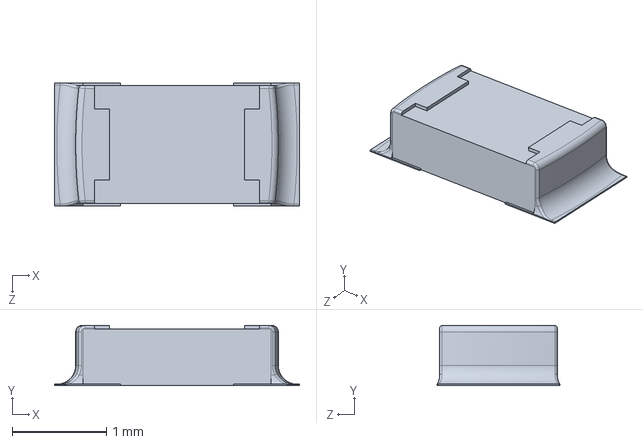
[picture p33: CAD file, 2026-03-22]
Planos/ky-040-enkoder-s-tlacitkem-1.snapshot.1/SMD rezistory.SLDPRT
2.60 x 0.64 x 1.30 mm

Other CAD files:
Planos/ky-040-enkoder-s-tlacitkem-1.snapshot.1/KY-040 - Rotační enkodér s tlačítkem, 20pulz_ot..SLDASM
Planos/lcd-20x4-display-hd44780-arduiono-raspberry-pi-1.snapshot.1/lcd20x4hd44780.igs
Planos/rotary-encoder-22.snapshot.2/Encoder.f3d

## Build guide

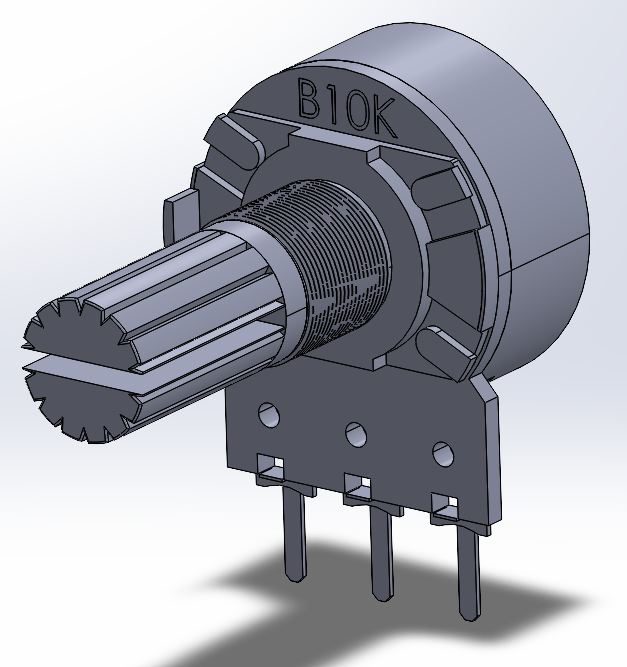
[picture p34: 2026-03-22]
Planos/potentiometer-step-1.snapshot.1/Potenciometro1.png

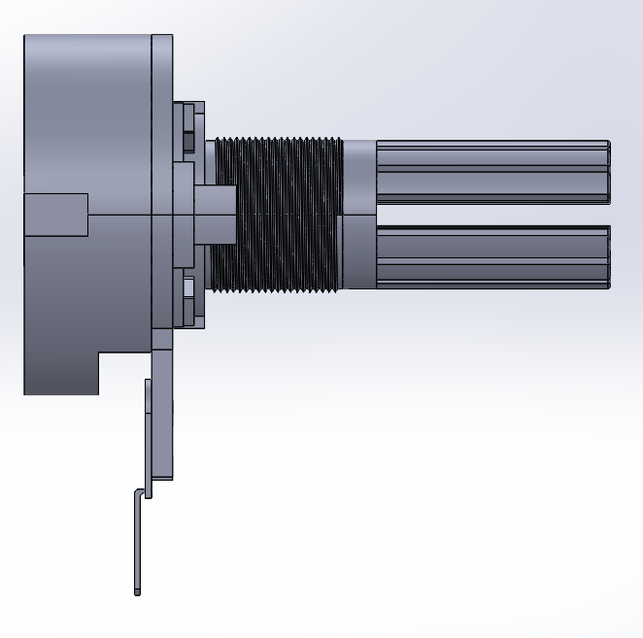
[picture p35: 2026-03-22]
Planos/potentiometer-step-1.snapshot.1/Potenciometro2.png

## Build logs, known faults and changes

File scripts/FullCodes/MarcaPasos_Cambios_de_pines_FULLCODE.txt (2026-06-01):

############################################################
### ARCHIVO: MarcaPasos_Cambios_de_pines.ino
############################################################

#include <MIDI.h>
#include <TimerOne.h>

#include "MidiProgramming.h"
#include "midiInterface.h"
#include "draw_menus.h"
#include "midiPresets.h"
#include "menus_buttons.h"
#include "config.h"

#define SEQ midiProg[presetsUI.indexSequence]

// ==============================================================================
//                INSTACIAS DE LAS LIBRERIAS Y VARIABLES GLOBALES
// ==============================================================================
MIDI_CREATE_CUSTOM_INSTANCE(HardwareSerial, Serial, MIDI, HairlessConfig);

unsigned long tiempoActualMillis;
unsigned long tiempoActualMicros;

volatile bool enviarPulso = false;
byte tareasPesadas;
byte clock;

Sequence* s;
Step* stp;

void syncWithActiveSequence() {
  s = presetsUI.getActiveSequence();
}

void initValuesSeq(){
  for(byte i = 0; i < N_MAX_SEQS; i++){
    p->nSequence[i].escalaSeleccionada = 1;
    p->nSequence[i].noteTone = 0;
    midiUI.mutePulsado[i] = false;
    for(byte j = 0; j < NUM_POTES; j++){
      int lectura = analogRead(midiUI.potesPin[j]);
      byte index = constrain(map(lectura, MAX_POTE_VALUE, MIN_POTE_VALUE, 48, 90), 48, 90);

      midiUI.charNumber[i] = (index <= 9) ? (index + '0') : (index -10 + 'A');

      byte notaEscala = constrain(map(lectura, MAX_POTE_VALUE, MIN_POTE_VALUE, 0, midiProg[i].nNotasEscalas[p->nSequence[i].escalaSeleccionada] - 1), 0, midiProg[i].nNotasEscalas[p->nSequence[i].escalaSeleccionada] - 1);
      p->nSequence[i].steps[j].note = midiProg[i].escalasNotas[p->nSequence[i].escalaSeleccionada][notaEscala];
      int valorCC = constrain(map(lectura, MAX_POTE_VALUE, 30, 0, 127), 0, 127);
      p->nSequence[i].steps[j].ccValue = valorCC;
      p->nSequence[i].steps[j].velocity = 127;
      p->nSequence[i].steps[j].ccSmoothCurve = 6;
      p->nSequence[i].steps[j].octave = 4;
      p->nSequence[i].steps[j].mutes = false;
      p->nSequence[i].steps[j].ccMutes = true;
    }
    for(byte j = 0; j < NUM_POTES; j++){
      int lectura = analogRead(midiUI.potesPin[j]);
      byte index = constrain(map(lectura, MAX_POTE_VALUE, MIN_POTE_VALUE, 48, 90), 48, 90);

      midiUI.charNumber[i] = (index <= 9) ? (index + '0') : (index -10 + 'A');

      byte notaEscala = constrain(map(lectura, MAX_POTE_VALUE, MIN_POTE_VALUE, 0, midiProg[i].nNotasEscalas[p->nSequence[i].escalaSeleccionada] - 1), 0, midiProg[i].nNotasEscalas[p->nSequence[i].escalaSeleccionada] - 1);
      p->nSequence[i].ext_steps[j].note = midiProg[i].escalasNotas[p->nSequence[i].escalaSeleccionada][notaEscala];
      int valorCC = constrain(map(lectura, MAX_POTE_VALUE, 30, 0, 127), 0, 127);
      p->nSequence[i].ext_steps[j].ccValue = valorCC;
      p->nSequence[i].ext_steps[j].velocity = 127;
      p->nSequence[i].ext_steps[j].ccSmoothCurve = 6;
      p->nSequence[i].ext_steps[j].octave = 4;
      p->nSequence[i].ext_steps[j].mutes = false;
      p->nSequence[i].ext_steps[j].ccMutes = true;
    }
    p->nSequence[i].canal = i;
    p->nSequence[i].ccNumber = 48 + i;
    p->nSequence[i].seqMode = 0;
    p->nSequence[i].armed = false;
    p->nSequence[i].steps[0].ccMutes = false;
    p->nSequence[i].steps[4].ccMutes = false;

    p->nSequence[i].subdivMode = 0;
    p->nSequence[i].indexSubdivisiones = 6;   // Pred. Negras
    p->nSequence[i].indComplexSubdivY = 0;  
    p->nSequence[i].indComplexSubdivX = 3;
    p->nSequence[i].nTotalSteps = N_MAX_STEPS;

    p->nSequence[i].ext_subdivMode = 0;
    p->nSequence[i].ext_indexSubdivisiones = 6;   // Pred. Negras
    p->nSequence[i].ext_indComplexSubdivY = 0;  
    p->nSequence[i].ext_indComplexSubdivX = 3;
    p->nSequence[i].ext_nTotalSteps = N_MAX_STEPS;
  }
  p->nSequence[0].armed = true;
}

// Gestion de MIDI y tiempo musical
void setup() {
  drawUI.configurarLCD();
  MIDI.begin(MIDI_CHANNEL_OMNI);
  MIDI.turnThruOff();
  //Serial.begin(9600);
  drawUI.drawLoadProgress(1); // 1
  //Botones Menus
  pinMode(menusUI.pinButton1, INPUT_PULLUP);
  pinMode(menusUI.pinButton2, INPUT_PULLUP);
  pinMode(menusUI.pinButton3, INPUT_PULLUP);
  pinMode(menusUI.pinButton4, INPUT_PULLUP);
  pinMode(menusUI.pinButton5, INPUT_PULLUP);
  pinMode(menusUI.settingsPin, INPUT_PULLUP);

  // Botones octavas
  pinMode(midiUI.pinOctPlus, INPUT_PULLUP);
  pinMode(midiUI.pinOctRest, INPUT_PULLUP);

  drawUI.drawLoadProgress(2); // 3
  // Botones de secuencias
  for(int i = 0; i < N_MAX_SEQS; i++){
    pinMode(midiUI.seqPinsButton[i], INPUT_PULLUP);
  }

  // Botones de control
  pinMode(midiUI.playPinButton, INPUT_PULLUP);
  pinMode(midiUI.stopPinButton, INPUT_PULLUP);  

  // Botones de los slots
  for(int i = 0; i < 3; i++){
    pinMode(presetsUI.slotsPin[i], INPUT_PULLUP);
  }
  pinMode(presetsUI.saveButton, INPUT_PULLUP);
  pinMode(menusUI.extPin, INPUT_PULLUP);

  //SD
  pinMode(53, OUTPUT);
  // Leds
  for(int i = 0; i < N_MAX_SEQS; i++){
    pinMode(midiUI.seqPinLed[i], OUTPUT);
  }
  drawUI.drawLoadProgress(3); // 6

  //Botones Mutes
  for(byte i = 0; i < NUM_MUTES; i++){
    pinMode(midiUI.mutesPin[i], INPUT_PULLUP);
  }
  drawUI.drawLoadProgress(4); // 10

  // Valores predeterminados
  initValuesSeq();
  drawUI.drawLoadProgress(5); // 15
  // Creación caracteres e inicio de la pantalla
  presetsUI.sdInit();
  delay(2000);
}

void funcionInterrupcion() { // Flag para el modo interno del clock
  enviarPulso = true; 
}

void loop() {
  // Funcion para el modo interno del clock
  if (enviarPulso) {
    enviarPulso = false; // Bajamos la bandera
    MIDI.sendRealTime(midi::Clock);
    clock++;
    MidiProgramming::tipoMsgMidi = 0xF8;
    if(clock > 23){clock = 0;}
    for(byte i = 0; i < N_MAX_SEQS; i++){
        midiProg[i].midiSeq();
        midiProg[i].midiNotesOn();
        midiProg[i].midiNotesOff();
    }
    MidiProgramming::tipoMsgMidi = 0;
    return;
  }
  if ((MidiProgramming::tipoMsgMidi == 0xFA || MidiProgramming::tipoMsgMidi == 0xFC) && MidiProgramming::modeMidiClock == 1 && !midiUI.deviceStop) {
    for(byte i = 0; i < N_MAX_SEQS; i++){
      midiProg[i].midiSeq();
    } 
    MidiProgramming::tipoMsgMidi = 0;
  }

  tiempoActualMillis = millis();
  tiempoActualMicros = micros();

  menusUI.checkMenuButtons();
  midiUI.checkMidiButtons();

  // Modo externo del clock
  if(MidiProgramming::modeMidiClock == 0){
    if(MIDI.read()){
      MidiProgramming::tipoMsgMidi = MIDI.getType();
      for(byte i = 0; i < N_MAX_SEQS; i++){
        midiProg[i].midiSeq();
      }
    }
    for(byte i = 0; i < N_MAX_SEQS; i++){
      if(p->nSequence[i].armed && midiUI.devicePlay){
        if(p->nSequence[i].seqMode == 0){
          midiProg[i].midiNotesOn();
        }
        else if(p->nSequence[i].seqMode == 1){
          midiProg[i].CCSend();
        }
      }
      midiProg[i].midiNotesOff();
    }
    MidiProgramming::tipoMsgMidi = 0;
  }

  // Ahorro del buffer
  switch(tareasPesadas){
    case 0:
      midiUI.checkPotes();
      tareasPesadas++;
      break;
    case 1:
      if (drawUI.updateLCD) {
        drawUI.update_LCD();
        drawUI.updateLCD = false;
      }
      tareasPesadas++;
      break;
    case 2:
      presetsUI.readSlotsButtons();
      tareasPesadas = 0;
      break;
  }

  // Reset pantalla
  if(menusUI.menuActual == 0){
    if(SEQ.nStep != drawUI.nStepAnterior){
      drawUI.updateLCD = true;
    }
  } 

  // Clock para salir de la pantalla de potenciómetro
  if (menusUI.menuActual == 3 && (tiempoActualMillis - midiUI.timeShowPotValue >= 1500)) {
    menusUI.menuActual = menusUI.menuAnterior;
    midiUI.poteBlocked[midiUI.movedPoteNumber] = true;
    drawUI.updateLCD = true;
  }
  else if ((menusUI.menuActual == 4 || menusUI.menuActual == 5) && (tiempoActualMillis - midiUI.ultimoTiempoBotonOct >= 1500)) {
    menusUI.menuActual = menusUI.menuAnterior;
    drawUI.updateLCD = true;
  }
  else if ((menusUI.menuActual == 6 || menusUI.menuActual == 7) && tiempoActualMillis - presetsUI.ultimoTiempoBotonPresets >= 1500){
    menusUI.menuActual = menusUI.menuAnterior;
    menusUI.nMenuSettings = 0;
    drawUI.updateLCD = true;
  }
}

############################################################
### ARCHIVO: config.h
############################################################

#ifndef CONFIG_H
#define CONFIG_H

const int MAX_POTE_VALUE = 1018;
const byte MIN_POTE_VALUE = 30;
const byte DEBOUNCE_DELAY_MS = 250;
const byte N_MAX_STEPS = 16;
const byte N_MAX_SEQS = 5;

extern unsigned long tiempoActualMillis;
extern unsigned long tiempoActualMicros;

#endif

############################################################
### ARCHIVO: draw_menus.cpp
############################################################

#include "draw_menus.h"
#include "midiProgramming.h"
#include "midiInterface.h"
#include "menus_buttons.h"
#include "midiPresets.h"
#include "config.h"

#include <Wire.h>
#include <LiquidCrystal_I2C.h>

#define SEQ midiProg[presetsUI.indexSequence]

DrawMenus drawUI;

DrawMenus::DrawMenus()
  : lcd(0x27, 20, 4),

    // Carácteres
    arrowLeft{ B00001, B00011, B00111, B01111, B01111, B00111, B00011, B00001 },
    arrowRight{ B10000, B11000, B11100, B11110, B11110, B11100, B11000, B10000 },
    redonda{ B00000, B00000, B00000, B01110, B10001, B10001, B01110, B00000 },
    blanca{ B00010, B00010, B00010, B00010, B01110, B10010, B10010, B01100 },
    negra{ B00010, B00010, B00010, B00010, B01110, B11110, B11110, B01100 },
    stepOff{ B00000, B00000, B00000, B01110, B00000, B00000, B00000, B00000 },
    stepOn{ B00000, B01110, B10001, B10001, B10001, B01110, B00000, B00000 },
    stepPass{ B00000, B01110, B11111, B11111, B11111, B01110, B00000, B00000 },

    ccLevel0{ 0, 0, 0, 0, 0, 0, 0, 31 },  //Abajo
    ccLevel1{ 0, 0, 0, 0, 0, 0, 31, 31 },
    ccLevel2{ 0, 0, 0, 0, 0, 31, 31, 31 },
    ccLevel3{ 0, 0, 0, 0, 31, 31, 31, 31 },
    ccLevel4{ 0, 0, 0, 31, 31, 31, 31, 31 },
    ccLevel5{ 0, 0, 31, 31, 31, 31, 31, 31 },
    ccLevel6{ 0, 31, 31, 31, 31, 31, 31, 31 },  // Casi arriba

    subdivisionesCharArray{ "1/8", "1/6", "1/4", "1/3", "1/2", "3/2", "1/1", "3/4", "2/1", "3/8", "4/1" },
    subdivisionesComplejasNumChar{ " 5", " 7", " 9", "11", "13", "15" },
    subdivisionesComplejasDenChar{ byte(2), byte(3), byte(4) },
    charEscalasNotas{ "C", "C#", "D", "D#", "E", "F", "F#", "G", "G#", "A", "A#", "B", "C" },
    nombreEscalas{ "Chromatic", "Natural Minor", "Natural Major", "Tone Scale", "Semitone-Tone" } {
  updateLCD = true;
  nAnteriorScreen = 999;
}

// ==============================================================================
//                                FUNCIONES UTILES
// ==============================================================================

void DrawMenus::syncWithActiveSequence() {
  s = presetsUI.getActiveSequence();
  
  stp = menusUI.editExtension ? s->ext_steps : s->steps;
  curTotalSteps = menusUI.editExtension ? s->ext_nTotalSteps : s->nTotalSteps;
  curSubdivMode = menusUI.editExtension ? s->ext_subdivMode : s->subdivMode;
  curIndSubdiv  = menusUI.editExtension ? s->ext_indexSubdivisiones : s->indexSubdivisiones;
  curindComplexSubdivY = menusUI.editExtension ? s->ext_indComplexSubdivY : s->indComplexSubdivY;
  curindComplexSubdivX = menusUI.editExtension ? s->ext_indComplexSubdivX : s->indComplexSubdivX;

}

void DrawMenus::configurarLCD() {
  lcd.init();
  Wire.setClock(400000);
  lcd.backlight();
  splashScreen();
}

void DrawMenus::printAt(byte x, byte y, byte var) {
  lcd.setCursor(x, y);
  lcd.print(var);
}

void DrawMenus::printAt(byte x, byte y, char text) {
  lcd.setCursor(x, y);
  lcd.print(text);
}

void DrawMenus::printAt(byte x, byte y, const char* text) {
  lcd.setCursor(x, y);
  lcd.print(text);
}

void DrawMenus::writeAt(byte x, byte y, byte numByte) {
  lcd.setCursor(x, y);
  lcd.write(numByte);
}

// ==============================================================================
//                           CARACTERES PERSONALIZADOS
// ==============================================================================

void DrawMenus::charactersMenu1() {
  lcd.createChar(0, arrowLeft);
  lcd.createChar(1, arrowRight);
  lcd.createChar(2, redonda);
  lcd.createChar(3, blanca);
  lcd.createChar(4, negra);
  lcd.createChar(5, stepOff);
  lcd.createChar(6, stepOn);
  lcd.createChar(7, stepPass);
}

void DrawMenus::charactersMenu2() {

  lcd.createChar(0, ccLevel0);
  lcd.createChar(1, ccLevel1);
  lcd.createChar(2, ccLevel2);
  lcd.createChar(3, ccLevel3);
  lcd.createChar(4, ccLevel4);
  lcd.createChar(5, ccLevel5);
  lcd.createChar(6, ccLevel6);
}

// ==============================================================================
//                           FUNCIONES DE DIBUJADO
// ==============================================================================

void DrawMenus::update_LCD() {
  syncWithActiveSequence();
  switch (menusUI.menuActual) {
    case 0: drawMenuNotes(); break;
    case 1: drawMenuCC(); break;
    case 2: drawMenuSettings(); break;
    case 3: drawScreenPotes(); break;
    case 4: drawScreenOctavas(); break;
    case 5: drawScreenTodasOctavas(); break;
    case 6: drawLoadPreset(presetsUI.nSlot); break;
    case 7: drawConfirmationScreen(); break;
  }
  updateLCD = false;
  interrupts();
  updateValues = false;
}

// --- MENU NOTAS ---

inline void DrawMenus::drawMenuNotes() {
  if (menusUI.seleccion >= 1 && menusUI.seleccion <= 4) { nScreen = 0; }

  if (midiUI.deviceStop) {
    printAt(2, 3, "      STOP      ");
  }
  if (!midiUI.deviceStop) {
    drawMutes();
    drawSteps();
  }

  if (nScreen != nAnteriorScreen || menusUI.menuAnterior != menusUI.menuActual || updateValues) { staticScreenNotes(); }

  switch (menusUI.seleccion) {
    case 1:
      lcd.noBlink(), printAt(0, 0, "["), printAt(4, 0, "]");
      printAt(8, 0, presetsUI.indexSequence),
        printAt(10, 0, " "), printAt(19, 0, " ");
      printAt(5, 1, " "), printAt(15, 1, " ");
      break;
    case 2:
      printAt(0, 0, " "), printAt(4, 0, " "), printAt(10, 0, " "), printAt(19, 0, " ");
      lcd.noBlink(), writeAt(5, 1, byte(0)), printAt(14, 1, curSubdivMode), lcd.write(byte(1));
      printAt(8, 2, " "), lcd.print(subdivisionesCharArray[curIndSubdiv]), lcd.print(F(" "));
      if (curSubdivMode == 0 || curSubdivMode == 1) {
        printAt(9, 2, subdivisionesCharArray[curIndSubdiv]);
      } else if (curSubdivMode == 2) {
        printAt(8, 2, subdivisionesComplejasNumChar[curindComplexSubdivX]), writeAt(11, 2, subdivisionesComplejasDenChar[curindComplexSubdivY]);
      }
      break;
    case 3:
      lcd.noBlink(), printAt(0, 0, " "), printAt(4, 0, " "), printAt(8, 0, presetsUI.indexSequence);
      printAt(5, 1, " "), printAt(15, 1, " ");
      if (curSubdivMode == 0 || curSubdivMode == 1) {
        writeAt(8, 2, byte(0)), lcd.print(subdivisionesCharArray[curIndSubdiv]), lcd.write(byte(1));
      } 
      else if (curSubdivMode == 2) {
        lcd.setCursor(8, 2), lcd.print(subdivisionesComplejasNumChar[curindComplexSubdivX]), lcd.setCursor(11, 2), lcd.write(subdivisionesComplejasDenChar[curindComplexSubdivY]);
        lcd.setCursor(menusUI.selectNum ? 9 : 11, 2);
        lcd.blink();
      }
      break;
    case 4:
      printAt(0, 0, " "), printAt(4, 0, " ");
      lcd.noBlink(), writeAt(10, 0, byte(0)), writeAt(19, 0, byte(1));
      nAnteriorScreen = nScreen;
      lcd.noBlink(), printAt(18, 0, curTotalSteps);
      break;
  }
}

inline void DrawMenus::staticScreenNotes() {
  charactersMenu1();

  for (int i = 1; i < 4; i++) {
    printAt(0, i, "                   "); // borrado de la pantalla
  }

  lcd.noBlink();
  printAt(1, 0, (!menusUI.editExtension) ? "SEQ  " : "EXT  "), lcd.write(126), lcd.print(F(" ")), printAt(9, 0, "  "), lcd.print(F("PASOS: ")), lcd.print(curTotalSteps);
  lcd.noBlink(), printAt(6, 1, "SUBDIV: "), lcd.print(curSubdivMode);
  if (curSubdivMode == 0 || curSubdivMode == 1) {
    printAt(9, 2, subdivisionesCharArray[curIndSubdiv]);
  } else if (curSubdivMode == 2) {
    printAt(8, 2, subdivisionesComplejasNumChar[curindComplexSubdivX]), lcd.print(F("/")), lcd.write(subdivisionesComplejasDenChar[curindComplexSubdivY]);
  }
  nAnteriorScreen = nScreen;
  menusUI.menuAnterior = menusUI.menuActual;
  drawStaticSteps();
}

// --- Primer dibujado de todos los pasos en la pantalla ---

inline void DrawMenus::drawStaticSteps() {
  if (midiUI.deviceStop) {
    printAt(2, 3, "      STOP      ");
    return;
  }

  lcd.setCursor(2, 3);
  for (int i = 0; i < curTotalSteps; i++) {
    lcd.write(
      (stp[i].mutes) ? byte(5) : (i == SEQ.nStep) ? byte(7)     // 5 = Mute activo; 6 = Paso activado; 7 = Paso reproduciendose actualmente;
                                                       : byte(6));
  }
  syncWithActiveSequence();
}

// --- Dibujado del mute si cambia de valor ---

inline void DrawMenus::drawMutes() {
  if (midiUI.indexMovedMute <= curTotalSteps - 1) {
    writeAt(midiUI.indexMovedMute + 2, 3, (stp[midiUI.indexMovedMute].mutes) ? byte(5) : byte(6));
  }
}

// --- Dibujado de los pasos cada vez que avanza la secuencia ---

inline void DrawMenus::drawSteps() {
  // Detectamos si el numero de pasos de la secuencia ha cambiado y borramos el paso que hemos eliminado
  if (lastNTotalSteps != curTotalSteps) {
    writeAt(curTotalSteps + 1, 3, stp[curTotalSteps - 1].mutes ? byte(5) : byte(6));
    printAt(curTotalSteps + 2, 3, " ");
    lastNTotalSteps = curTotalSteps;
  }
  if(SEQ.nStep == nStepAnterior) return; // Si seguimos en el mismo paso, terminamos la función.
  
  writeAt(nStepAnterior + 2, 3, stp[nStepAnterior].mutes ? byte(5) : byte(6)); // Dibujado del paso anterior
  writeAt(SEQ.nStep + 2, 3, stp[SEQ.nStep].mutes ? byte(5) : byte(7)); // Dibujado del paso actual
  nStepAnterior = SEQ.nStep;
}

// --- MENU CC ---

inline void DrawMenus::drawMenuCC() {
  if (menusUI.seleccion == 1) nScreen = 0;

  if (!midiUI.deviceStop) drawCCMutes();
  else printAt(0, 3, "        STOP        ");

  if (menusUI.menuAnterior != menusUI.menuActual || nScreen != nAnteriorScreen || updateValues) { staticScreenCC(); }
  
  lcd.setCursor(0, 2);
  drawCCVisualizer();

  switch (menusUI.seleccion) {
    case 1:
      lcd.noBlink(), printAt(8, 0, presetsUI.indexSequence), printAt(10, 0, " "), printAt(19, 0, " ");
      printAt(0, 0, "["), printAt(3, 0, "] ");
      printAt(0, 1, midiUI.movedPoteValue);
      lcd.print(F("  "));

      break;

    case 2:
      printAt(0, 0, " "), printAt(3, 0, " "),
        lcd.noBlink(), printAt(10, 0, "["), printAt(19, 0, "]");
      nAnteriorScreen = nScreen;
      lcd.noBlink(), printAt(18, 0, curTotalSteps);
      printAt(curTotalSteps, 2, " ");
      printAt(13, 1, " "), lcd.print(subdivisionesCharArray[curIndSubdiv]), printAt(17, 1, " ");
      break;
    case 3:
      lcd.noBlink(), printAt(10, 0, " "), printAt(19, 0, " ");
      nAnteriorScreen = nScreen;
      printAt(13, 1, "["), lcd.print(subdivisionesCharArray[curIndSubdiv]), lcd.print(F("]"));
      break;
  }
}

inline void DrawMenus::staticScreenCC() {
  charactersMenu2();

  for (int i = 1; i < 4; i++) { // Borrado
    for (int j = 0; j < 19; j++) {
      printAt(j, i, " ");
    }
  }

  lcd.noBlink(), writeAt(0, 0, 127), lcd.print(F("CC   ")), lcd.write(126), lcd.print(F(" ")), printAt(9, 0, "  "), lcd.print(F("PASOS: ")), lcd.print(curTotalSteps);
  printAt(14, 1, subdivisionesCharArray[curIndSubdiv]);
  lcd.setCursor(0, 3);
  for (int i = 0; i < curTotalSteps; i++) {
    lcd.print((!stp[i].ccMutes) ? "+" : " ");
  }
  menusUI.menuAnterior = menusUI.menuActual;
  nAnteriorScreen = nScreen;
}

// --- Dibujado de los puntos de la automatización ---

inline void DrawMenus::drawCCMutes() {
  if (midiUI.indexMovedMute <= curTotalSteps - 1) {
    printAt(midiUI.indexMovedMute, 3, (!stp[midiUI.indexMovedMute].ccMutes) ? "+" : " ");
  }
}

// --- Dibujado de la curva de la automatización ---

inline void DrawMenus::drawCCVisualizer() {
  lcd.setCursor(0, 2);
  byte visualBuffer[curTotalSteps];
  calcularCurvaParaPantalla(visualBuffer, 1, 96);

  for (int i = 0; i < curTotalSteps; i++) {
    int nivel = map(visualBuffer[i], 0, 127, 0, 7);
    lcd.write(nivel == 7 ? 255 : byte(nivel));
  }
}

void DrawMenus::calcularCurvaParaPantalla(byte* visualBuffer, int nCharStep, int resolution) { // 
  int totalSteps = curTotalSteps;

  for (int step = 0; step < totalSteps; step++) { // pasamos por todos los pasos para calcular cual es el valor de cada uno de ellos

    // Buscar el punto desde el que partimos
    int prevStep = step;
    while (prevStep > 0 && stp[prevStep].ccMutes) { // buscamos el primer valor no muteado
      prevStep--;
    }

    // Mirar hacia adelante y encontrar el primer punto que no esté muteado
    int nextStep = step + 1;
    bool foundNext = false;
    while (nextStep < totalSteps) {
      if (!stp[nextStep].ccMutes) {
        foundNext = true;
        break;
      }
      nextStep++;
    }

    // Recogemos los valores de los dos puntos y su distancia entre ellos
    int lastValue = stp[prevStep].ccValue;
    int nextValue = 0;
    int distanceSteps = 1;

    if (foundNext) {
      nextValue = stp[nextStep].ccValue;
      distanceSteps = nextStep - prevStep;
    } 
    else {
      int firstStep = 0;
      while (firstStep < totalSteps && stp[firstStep].ccMutes) {
        firstStep++;
      }
      nextValue = stp[firstStep].ccValue;
      distanceSteps = (totalSteps - prevStep) + firstStep;
    }

    // Calcular distancias reales
    int ccStepSize = (nextValue - lastValue); // Distancia total entre los dos mensajes
    int totalResolution = distanceSteps * resolution; // valores totales a calcular entre los dos puntos
    int indexResolution = (step - prevStep) * resolution; // valor en que nos encontramos 
    int divisor = (totalResolution > 1) ? totalResolution : 2; // si hay solo un punto, divisor vale dos para que la operación no este dividiendo entre 0: int indiceLUT = (i * 99) / (divisor - 1);

    // Rellenar el buffer visual para este paso concreto. nCharStep decide cuanto dividimos el step para tener mas resolucion (por defecto 1)
    for (int p = 0; p < nCharStep; p++) { 
      int subReal = (p * resolution) / nCharStep; 
      int indexCurva = indexResolution + subReal;

      long valorCurva = midiProg[presetsUI.indexSequence].ccCurveFunction(indexCurva, divisor, stp[prevStep].ccSmoothCurve);

      int valorCalculado = lastValue + (((long)ccStepSize * valorCurva) / 255);

      visualBuffer[(step * nCharStep) + p] = valorCalculado;
    }
  }
}

// ==============================================================================
//                              PANTALLAS EFIMERAS
// ==============================================================================

inline void DrawMenus::drawScreenPotes() {
  nScreen = 4;
  lcd.clear();
  lcd.print(F("Pote N"));
  lcd.print((char)223);
  lcd.print(midiUI.movedPoteNumber + 1);
  lcd.print(F(" : "));
  lcd.setCursor(0, 1);
  if (s->seqMode == 0) { // Detectamos si estamos en el modo notas
    if (midiUI.muteActivado) { 
      lcd.print(F("Velocity = "));
      lcd.print(midiUI.movedPoteValue);
      nAnteriorScreen = 4;
    } 
    else {
      lcd.print(charEscalasNotas[stp[midiUI.movedPoteNumber].note % 12]);
      lcd.print(int(midiUI.movedPoteValue / 12) + stp[midiUI.movedPoteNumber].octave);
      lcd.print(F(" "));
      lcd.print(midiUI.movedPoteValue + (12 * stp[midiUI.movedPoteNumber].octave));
      nAnteriorScreen = 4;
    }
  }
}
inline void DrawMenus::drawScreenOctavas() {
  nScreen = 5;
  lcd.clear();
  lcd.print(F("Octava :"));
  printAt(0, 1, charEscalasNotas[stp[midiUI.indexMovedMute].note]);
  lcd.print(int(stp[midiUI.indexMovedMute].note / 12) + stp[midiUI.indexMovedMute].octave);
  lcd.print(F(" "));
  lcd.print(stp[midiUI.indexMovedMute].note + (12 * stp[midiUI.indexMovedMute].octave));
  nAnteriorScreen = 5;
}
inline void DrawMenus::drawScreenTodasOctavas() {
  nScreen = 6;
  lcd.clear();

  // 1. Comprobamos si el modo extensión está activado
  // (Uso s->extensionArmed basándome en tu estructura de midiPresets.h)
  bool mostrarExtension = menusUI.editExtension; 

  for (byte i = 0; i < N_MAX_STEPS; i++) { 
    // 2. La matemática mágica de posicionamiento para 20x4
    byte coordX = 5 * (i % 4);  // Columnas: 0, 5, 10, 15
    byte coordY = i / 4;        // Filas: 0, 1, 2, 3 (gracias a la división entera)

    lcd.setCursor(coordX, coordY);

    // 3. Apuntamos al paso correcto según el botón de extensión
    Step pasoActual = mostrarExtension ? s->ext_steps[i] : s->steps[i];

    // 4. Imprimimos la nota y su octava calculada
    lcd.print(charEscalasNotas[pasoActual.note]);
    lcd.print(int(pasoActual.note / 12) + pasoActual.octave);
    
    // Rellenamos con espacios para que cada celda mida exactamente 5 caracteres
    // Evita que si una nota mide menos (ej: "Do4" vs "Fa#4") queden letras fantasma
    lcd.print(F("  ")); 
  }

  nAnteriorScreen = 6;
}

void DrawMenus::sdErrorMsg() {
  printAt(3, 2, "X ERROR: No SD");
  delay(2000);
}

void DrawMenus::sdCheckMsg() {
  printAt(1, 2, "CHECK: SD detected");
}

inline void DrawMenus::drawLoadPreset(byte number) {
  lcd.clear();
  nScreen = 6;
  printAt(3, 0, "Guardado Slot ");
  lcd.print(number);
  printAt(5, 2, "COMPLETADO");
  nAnteriorScreen = 6;
}

void DrawMenus::splashScreen() {
  // 1. Definimos los caracteres
  byte notaMusical[8] = {
    0b00100, 0b00110, 0b00101, 0b00101, 
    0b00100, 0b11100, 0b11100, 0b00000
  };

  lcd.createChar(1, notaMusical);
  
  lcd.clear(); // Lienzo en blanco

  for (int i = 0; i <= 9; i++) {
    lcd.setCursor(9 - i, 0); 
    lcd.print(F("=")); // Expande hacia la izquierda
    lcd.setCursor(10 + i, 0); 
    lcd.print(F("=")); // Expande hacia la derecha
    delay(40);      // Velocidad de la animación
  }

  // Pequeño respiro
  delay(150);

  // --- FASE 2: Aparición del título con adornos ---
  const char* titulo = "MARCAPASOS";
  lcd.setCursor(2, 1);
  lcd.write(byte(1)); // Dibuja la nota izquierda
  lcd.print(titulo);
  lcd.write(byte(1)); // Dibuja la nota derecha
  
  delay(300);

  // --- FASE 3: Efecto "máquina de escribir" para el subtítulo ---
  const char* subtitulo = "STEP SEQUENCER";
  lcd.setCursor(3, 2);
  for (unsigned int i = 0; i < strlen(subtitulo); i++) {
    lcd.print(subtitulo[i]);
    delay(50); // Velocidad del tecleo
  }

  delay(1500);
  for (int i = 0; i <= 9; i++) {
    lcd.setCursor(9 - i, 0); 
    lcd.print(F(" ")); // Expande hacia la izquierda
    lcd.setCursor(10 + i, 0); 
    lcd.print(F(" ")); // Expande hacia la derecha
    delay(40);      // Velocidad de la animación
  }
  for (unsigned int i = 0; i < strlen(subtitulo); i++) {
    lcd.print(F(" "));
    delay(50);
  }
  for (unsigned int i = 0; i < strlen(titulo); i++) {
    lcd.print(F(" "));
    delay(50); 
  }
  lcd.clear(); 
}

void DrawMenus::drawLoadProgress(byte loadProgress) {
  for(int i = 0; i < loadProgress; i++) {
    if(progresoActual < 20) {
      lcd.setCursor(progresoActual, 3); // Fila 4 (abajo del todo)
      lcd.write(byte(255)); // Escribe el bloque
      lcd.setCursor(0,2);
      switch(progresoActual){
        case 0:  lcd.print(F("  MIDI INITIALIZED  ")); delay(200); break;
        case 1:  lcd.print(F(" BUTTONS INITIALIZED")); delay(300); break;
        case 2:  lcd.print(F("  LEDS INITIALIZED  ")); delay(100); break;
        case 6:  lcd.print(F("  MUTES INITIALIZED ")); delay(200); break;
        case 10: lcd.print(F("   DEFAULT VALUES   ")); delay(900); break;
      }
      progresoActual++;
      delay(100);
    }
  }
}

############################################################
### ARCHIVO: draw_menus.h
############################################################

#ifndef DRAW_MENUS_H
#define DRAW_MENUS_H

#include <Arduino.h>
#include <MIDI.h>
#include <Wire.h> 
#include <LiquidCrystal_I2C.h>

struct Sequence;
struct Step;

// ==============================================================================
//                                CLASE PRINCIPAL
// ==============================================================================

class DrawMenus {
  private:
    Sequence* s;
    Step* stp;
  public:
  DrawMenus();
    LiquidCrystal_I2C lcd;

// ==============================================================================
//                         CARACTERES Y VARIABLES
// ==============================================================================

    // --- Caracteres personalizados ---
    byte arrowLeft[8];
    byte arrowRight[8];
    byte redonda[8];
    byte blanca[8];
    byte negra[8];
    byte stepOff[8];
    byte stepOn[8];
    byte stepPass[8];
    
    // --- Barra de nivel modo CC ---
    byte ccLevel0[8];
    byte ccLevel1[8];
    byte ccLevel2[8];
    byte ccLevel3[8];
    byte ccLevel4[8];
    byte ccLevel5[8];
    byte ccLevel6[8];

    // --- Arrays de caracteres ---
    const char* subdivisionesCharArray [11];
    const char* subdivisionesComplejasNumChar[6];
    const byte subdivisionesComplejasDenChar[3];
    const char* charEscalasNotas[13];
    const char* nombreEscalas[5];
    int progresoActual;

    // --- Variables de estado ---
    byte nScreen;
    byte nAnteriorScreen;
    byte lastNTotalSteps;
    byte nStepAnterior;

    // --- Flags de actualización de la pantalla ---
    bool updateLCD;
    bool updateValues;

    // --- Variables de la secuencia ---
    byte curTotalSteps;
    byte curSubdivMode;
    byte curIndSubdiv;
    byte curindComplexSubdivY;
    byte curindComplexSubdivX;

// ==============================================================================
//                         DECLARACION DE FUNCIONES
// ==============================================================================

    // --- Funciones utiles ---
    void configurarLCD();
    void printAt(byte x, byte y, char text);
    void printAt(byte x, byte y, const char* text);
    void printAt(byte x, byte y, byte var);
    void writeAt(byte x, byte y, byte numByte);
    void syncWithActiveSequence();
    void charactersMenu1();
    void charactersMenu2();
    
    // --- Indice principal ---
    void update_LCD();

    // --- Funciones de dibujado - Fijas ---
    void drawMenuNotes();
    void drawMenuCC();
    void drawMenuSettings();
    void staticScreenNotes();
    void staticScreenCC();
    void staticScreenSettings();

    // --- Funciones de dibujado - Pop-Ups ---
    void drawScreenPotes();
    void drawScreenOctavas();
    void drawScreenTodasOctavas();

    // --- Acualización de simbolos ---
    void drawMutes();
    void drawCCMutes();
    void drawSteps();
    void drawStaticSteps();
    void sdErrorMsg();
    void sdCheckMsg();
    void drawLoadPreset(byte number);
    void drawConfirmationScreen();
    void splashScreen();
    void drawLoadProgress(byte loadProgress);

    // --- Curva CC ---
    void drawCCVisualizer();
    void calcularCurvaParaPantalla(byte* visualBuffer, int nCharStep, int resolution);

};

extern DrawMenus drawUI;

#endif

############################################################
### ARCHIVO: draw_menus_settings.cpp
############################################################

#include "draw_menus.h"
#include "midiProgramming.h"
#include "midiInterface.h"
#include "menus_buttons.h"
#include "midiPresets.h"
#include "config.h"

#include <Wire.h> 
#include <LiquidCrystal_I2C.h>

// ==============================================================================
//                         DIBUJADO DE LA CONFIGURACIÓN
// ==============================================================================

void DrawMenus::drawMenuSettings(){
  switch(menusUI.nMenuSettings){
    // MENU PRINCIPAL DE CONFIGURACION    
    case 0: 
      if(menusUI.seleccion == 1 || menusUI.seleccion == 2 || menusUI.seleccion == 3 || menusUI.seleccion == 4){nScreen = 0;}
      else if(menusUI.seleccion == 5 || menusUI.seleccion == 6 || menusUI.seleccion == 7 || menusUI.seleccion == 8){nScreen = 1;}  
      if(menusUI.menuAnterior != menusUI.menuActual || nScreen != nAnteriorScreen || updateValues){staticScreenSettings();}    
      
      for(int i = 0; i < 4; i++){
        printAt(1, i, " ");
      }
      writeAt(1, (menusUI.seleccion - 1) % 4, byte(1));
      break;
    // --- SAVE PRESET ---
    case 1:
      nScreen = 2;
      switch(menusUI.seleccion){
        // PANTALLA DE SELECCIÓN DE TIPO (Sequence o Pattern)
        case 1:
          if(menusUI.menuAnterior != menusUI.menuActual || nScreen != nAnteriorScreen || updateValues){staticScreenSettings();}
          lcd.noBlink();
          if(menusUI.whatSaveSelect == 0) {printAt(5, 1, "Sequence"), lcd.write(byte(1)), printAt(9,2,".seq");}
          else if(menusUI.whatSaveSelect == 1) {writeAt(4, 1, byte(0)), lcd.print(F("Pattern")), printAt(9,2,".pat");}
          printAt(1,2,midiUI.charNumber);
          break;
        // PANTALLA DE ESCRITURA DEL NOMBRE DEL ARCHIVO
        case 2:
          if(menusUI.menuAnterior != menusUI.menuActual || nScreen != nAnteriorScreen || updateValues){staticScreenSettings();}
          lcd.noBlink();
          if(menusUI.whatSaveSelect == 0) {printAt(5, 1, "Sequence"), lcd.print(F(" ")), printAt(9,2,".seq");}
          else if(menusUI.whatSaveSelect == 1) {printAt(4, 1, " "), lcd.print(F("Pattern")),printAt(9,2,".pat");}
          writeAt(0, 2, byte(0)), printAt(1,2,midiUI.charNumber), writeAt(13, 2, byte(0));
          break;
      }
      break;
    // --- LOAD PRESET ---
    case 2:
      nScreen = 3;
      switch(menusUI.seleccion){
        // PANTALLA DE SELECCIÓN DE TIPO (Sequence o Pattern)
        case 1:
          if(menusUI.menuAnterior != menusUI.menuActual || nScreen != nAnteriorScreen || updateValues){staticScreenSettings();}
          lcd.noBlink();
          if(menusUI.whatSaveSelect == 0) {printAt(8, 1, "Sequence"), lcd.write(byte(1));}
          else if(menusUI.whatSaveSelect == 1) {writeAt(7, 1, byte(0)), lcd.print(F("Pattern"));}
          break; 
        // PANTALLA DE SELECCIÓN DE ARCHIVO
        case 2:
          if(menusUI.menuAnterior != menusUI.menuActual || nScreen != nAnteriorScreen || updateValues){
            lcd.clear(); 
            nAnteriorScreen = nScreen;
            menusUI.menuAnterior = menusUI.menuActual;
            updateValues = false;
          }

          for(int i = 0; i < 4; i++){
            if(i == menusUI.cursorPos){writeAt(0, i, byte(1));} 
            else {printAt(0, i, " ");}
            if((menusUI.scrollOffset + i) < menusUI.maxIndex){
              presetsUI.getFileName(menusUI.scrollOffset + i, menusUI.whatSaveSelect, midiUI.charNumber);
              printAt(1, i, midiUI.charNumber);
              if(menusUI.whatSaveSelect == 0) {lcd.print(F(".seq"));}
              else if(menusUI.whatSaveSelect == 1) {lcd.print(F(".pat"));}    
            } 
            else {printAt(1, i, "            ");}
          }
          break;
      }
      break;
    // --- DELETE PRESET ---
    case 3:
      nScreen = 4;
      switch(menusUI.seleccion){
        case 1:
          // PANTALLA DE SELECCIÓN DE TIPO (Sequence o Pattern)
          if(menusUI.menuAnterior != menusUI.menuActual || nScreen != nAnteriorScreen || updateValues){staticScreenSettings();}
          lcd.noBlink();
          if(menusUI.whatSaveSelect == 0) {printAt(9, 1, "Sequence"), lcd.write(byte(1));}
          else if(menusUI.whatSaveSelect == 1) {writeAt(8, 1, byte(0)), lcd.print(F("Pattern"));}
          break; 
          // PANTALLA DE SELECCIÓN DE ARCHIVO
        case 2:
          if(menusUI.menuAnterior != menusUI.menuActual || nScreen != nAnteriorScreen || updateValues){
            lcd.clear(); 
            nAnteriorScreen = nScreen;
            menusUI.menuAnterior = menusUI.menuActual;
            updateValues = false;
          }

          for(int i = 0; i < 4; i++){
            if(i == menusUI.cursorPos){writeAt(0, i, byte(1));} 
            else {printAt(0, i, " ");}
            if((menusUI.scrollOffset + i) < menusUI.maxIndex){
              presetsUI.getFileName(menusUI.scrollOffset + i, menusUI.whatSaveSelect, midiUI.charNumber);
              printAt(1, i, midiUI.charNumber);
              if(menusUI.whatSaveSelect == 0) {lcd.print(F(".seq"));}
              else if(menusUI.whatSaveSelect == 1) {lcd.print(F(".pat"));}  
            } 
            else {printAt(1, i, "            ");}
          }
          break;
        // PANTALLA DE CONFIRMACION
        case 3:
          if(menusUI.menuAnterior != menusUI.menuActual || nScreen != nAnteriorScreen || updateValues){staticScreenSettings();}
          printAt(1, 2, midiUI.charNumber);
          if(!menusUI.deleteConfirm){writeAt(1,3,byte(0)), lcd.print(F("No")), lcd.write(byte(1)), printAt(11,3," "), lcd.print(F("Yes")), lcd.print(F(" "));}
          else if(menusUI.deleteConfirm){printAt(1,3," "), lcd.print(F("No")), lcd.print(F(" ")), writeAt(11,3,byte(0)), lcd.print(F("Yes")), lcd.write(byte(1));}
          break;
      }
      break;
    // --- MODO MIDI CLOCK ---
    case 4:
      nScreen = 5;
      if(menusUI.menuAnterior != menusUI.menuActual || nScreen != nAnteriorScreen || updateValues){staticScreenSettings();}
      lcd.noBlink();

      if(MidiProgramming::modeMidiClock == 0) {printAt(5, 1, "External"), lcd.write(byte(1));}
      else if(MidiProgramming::modeMidiClock == 1) {writeAt(4, 1, byte(0)), lcd.print(F("Internal"));}
      break;

    // --- SCALE SELECTOR ---
    case 5:
      nScreen = 6;
      if(menusUI.menuAnterior != menusUI.menuActual || nScreen != nAnteriorScreen || updateValues){staticScreenSettings();}
      lcd.noBlink();

      switch(menusUI.seleccion){
        case 1:
          writeAt(0,1,byte(0)), lcd.print(nombreEscalas[s->escalaSeleccionada]), lcd.write(byte(1));
          printAt(0, 2, " "), printAt(12, 2, charEscalasNotas[s->noteTone]), lcd.print(F(" "));
          break;
        case 2:
          printAt(0, 1, " "), lcd.print(nombreEscalas[s->escalaSeleccionada]), lcd.print(F(" "));
          writeAt(0, 2, byte(0)), printAt(12, 2, charEscalasNotas[s->noteTone]), lcd.write(byte(1));
          break;
      } 
      break;  
    // --- VALORES MIDI CC ---
    case 6:
      nScreen = 7;
      if(menusUI.menuAnterior != menusUI.menuActual || nScreen != nAnteriorScreen || updateValues){staticScreenSettings();}
      lcd.noBlink();
      switch(menusUI.seleccion){
        case 1:
          writeAt(0,3,byte(1)), printAt(1, 3, s->ccNumber);
          break;
        case 2:
          writeAt(4,3,byte(1)), printAt(5, 3, s->ccNumber);
          break;
        case 3:
          writeAt(8,3,byte(1)), printAt(9, 3, s->ccNumber);
          break;
        case 4:
          writeAt(12,3,byte(1)), printAt(13, 3, s->ccNumber);
          break;
        case 5:
          writeAt(16,3,byte(1)), printAt(17, 3, s->ccNumber);
          break;
      }
      break;
    case 8: // Suponiendo que nScreen = 8 o el case correspondiente
      nScreen = 8;
      lcd.clear();

      // 1. Comprobamos si el modo extensión está activado
      // (Uso s->extensionArmed basándome en tu estructura de midiPresets.h)
      bool mostrarExtension = menusUI.editExtension; 

      for (byte i = 0; i < N_MAX_STEPS; i++) { 
        // 2. La matemática mágica de posicionamiento para 20x4
        byte coordX = 5 * (i % 4);  // Columnas: 0, 5, 10, 15
        byte coordY = i / 4;        // Filas: 0, 1, 2, 3 (gracias a la división entera)

        lcd.setCursor(coordX, coordY);

        // 3. Apuntamos al paso correcto según el botón de extensión
        Step pasoActual = mostrarExtension ? s->ext_steps[i] : s->steps[i];

        // 4. Imprimimos la nota y su octava calculada
        lcd.print(charEscalasNotas[pasoActual.note]);
        lcd.print(int(pasoActual.note / 12) + pasoActual.octave);
        
        // Rellenamos con espacios para que cada celda mida exactamente 5 caracteres
        // Evita que si una nota mide menos (ej: "Do4" vs "Fa#4") queden letras fantasma
        lcd.print(F("  ")); 
      }
      break;
  }
}

inline void DrawMenus::staticScreenSettings(){
  charactersMenu1();
  lcd.clear();
  if(nScreen == 0){
    printAt(2,0,"Save Preset");
    printAt(2,1,"Load Preset");
    printAt(2,2,"Delete Preset");
    printAt(2,3,"Clock Mode");
  }
  else if(nScreen == 1){
    printAt(2,0,"Select Scale");
    printAt(2,1,"Select CCNumber");
    printAt(2,2,"Reset Input Note");
    printAt(2,3,"Ver Secuencia");
  }
  else if(nScreen == 2){
    printAt(1, 2, "Save: ");
  }
  else if(nScreen == 3){
    if(menusUI.seleccion == 1){printAt(1, 1, "Load: ");}
    else if(menusUI.seleccion == 2){printAt(1, 1, "File Name: ");}
  }
  else if(nScreen == 4){
    if(menusUI.seleccion == 1){printAt(1, 1, "Delete: ");}
    else if(menusUI.seleccion == 2){printAt(1, 1, "File Name: ");}
    else if(menusUI.seleccion == 3){printAt(1,1, "Delete"), printAt(14,2,"?");}
  }
  else if(nScreen == 5){
    printAt(4,0,"CLOCK MODE: ");
  }
  else if(nScreen == 6){
    printAt(1,0,"Scale Type: ");
    printAt(1,2,"Tone Note: ");
  }
  else if(nScreen == 7){
    printAt(8, 0, "N"), lcd.print((char) 223), lcd.print(F(" SEQ"));
    lcd.setCursor(0,1);
    for(int i = 0; i < N_MAX_SEQS; i++){
      lcd.print(F("  ")), lcd.print(i), lcd.print(F(" "));
    }
    printAt(8, 2, "N"), lcd.print((char) 223), lcd.print(F(" CC"));
    for(int i = 0; i < N_MAX_SEQS; i++){
      printAt((4*i)+1, 3, p->nSequence[i].ccNumber);
    }
  }
  nAnteriorScreen = nScreen;
  menusUI.menuAnterior = menusUI.menuActual;
}

void DrawMenus::drawConfirmationScreen(){
  lcd.clear();
  nScreen = 7;

  if(menusUI.nMenuSettings == 1){printAt(3, 0, "Saved");}
  else if(menusUI.nMenuSettings == 2){printAt(3, 0, "Load");}
  else if(menusUI.nMenuSettings == 3){printAt(3, 0, "Deleted");}

  printAt(3, 1, midiUI.charNumber);
  if(menusUI.whatSaveSelect == 0) {lcd.print(F(".seq"));}
  else if(menusUI.whatSaveSelect == 1) {lcd.print(F(".pat"));}  
  printAt(5, 2, "SUCCESFULLY");
  nAnteriorScreen = 7;
}

############################################################
### ARCHIVO: menus_buttons.cpp
############################################################

#include <Arduino.h>
#include <Encoder.h>

#include "menus_buttons.h"
#include "MidiProgramming.h"
#include "midiInterface.h"
#include "midiPresets.h"
#include "draw_menus.h"
#include "config.h"

#define SEQ midiProg[presetsUI.indexSequence]

MenusButtons menusUI;

Encoder miEncoder(19, 17); // Izquierda y derecha

MenusButtons::MenusButtons() : 
  ultimaConfiguracionModo2{0, 2}
{
  menuActual = 0;
  nMenuSettings = 0;
  seleccion = 1;
  ultimaConfiguracionModo0 = 6;
  ultimaConfiguracionModo1 = 6;
  for(byte i = 0; i < N_MAX_SEQS; i++){
    cambioModo0[i] = false;
    cambioModo1[i] = false;
    cambioModo2[i] = false;
  }

  ultimaConfiguracionModo2[0] = 0;
  ultimaConfiguracionModo2[1] = 2;
  posicionActual = miEncoder.read()/4;
  posicionAnterior = posicionActual;

  index = 0;
  maxIndex = 0;
  scrollOffset = 0;
  cursorPos = 0;
}

// ==============================================================================
//                               FUNCIONES UTILES
// ==============================================================================

bool MenusButtons::timeDebounce(){
  return (tiempoActualMillis - ultimoTiempoBotonMenu >= DEBOUNCE_DELAY_MS);
}

void MenusButtons::syncWithActiveSequence() {
  s = presetsUI.getActiveSequence();
  stp = menusUI.editExtension ? s->ext_steps : s->steps;

  curTotalSteps = menusUI.editExtension ? s->ext_nTotalSteps : s->nTotalSteps;
  curSubdivMode = menusUI.editExtension ? s->ext_subdivMode : s->subdivMode;
  curIndSubdiv  = menusUI.editExtension ? s->ext_indexSubdivisiones : s->indexSubdivisiones;
  curindComplexSubdivY = menusUI.editExtension ? s->ext_indComplexSubdivY : s->indComplexSubdivY;
  curindComplexSubdivX = menusUI.editExtension ? s->ext_indComplexSubdivX : s->indComplexSubdivX;
}

void MenusButtons::commitSequenceChanges() {
  if (editExtension) {
    s->ext_nTotalSteps = curTotalSteps;
    s->ext_subdivMode = curSubdivMode;
    s->ext_indexSubdivisiones = curIndSubdiv;
    s->ext_indComplexSubdivY = curindComplexSubdivY;
    s->ext_indComplexSubdivX = curindComplexSubdivX;
  } else {
    s->nTotalSteps = curTotalSteps;
    s->subdivMode = curSubdivMode;
    s->indexSubdivisiones = curIndSubdiv;
    s->indComplexSubdivY = curindComplexSubdivY;
    s->indComplexSubdivX = curindComplexSubdivX;
  }
}

void MenusButtons::resetEncoder(){
  if(rollDerecha == true || rollIzquierda == true){
    rollDerecha = false;
    rollIzquierda = false;
  }
}

void MenusButtons::aplicarCambiosEncoder(){
  drawUI.updateLCD = true;
  drawUI.updateValues = true;
}

void MenusButtons::aplicarCambiosBotones(){
  drawUI.updateLCD = true;
  ultimoTiempoBotonMenu = tiempoActualMillis;
  repeatedButton = true;
  drawUI.updateValues = true;
}

void MenusButtons::checkSeqMode(){
  s = presetsUI.getActiveSequence();
  if(s->seqMode == 0){
    if(editExtensionHistorial){ editExtension = true;}
    menusUI.menuActual = 0;
    syncWithActiveSequence();
  }
  else if(s->seqMode == 1){
    menusUI.menuActual = 1;
  }
}

// ==============================================================================
//                         CONTROL DE LOS BOTONES
// ==============================================================================

void MenusButtons::checkMenuButtons() {
  syncWithActiveSequence();
  btnArriba = !digitalRead(pinButton1);
  btnOk = !digitalRead(pinButton2);
  btnAbajo = !digitalRead(pinButton3);
  btnIzquierda = !digitalRead(pinButton4);
  btnDerecha = !digitalRead(pinButton5);
  btnSettings = !digitalRead(settingsPin);
  btnExt = !digitalRead(extPin);

  long lecturaBruta = miEncoder.read(); // Leemos sin dividir
  
  // Comprobamos si ha avanzado 4 pulsos enteros (1 click físico real a la derecha)
  if (lecturaBruta - posicionAnterior >= 4) {
    rollDerecha = true;
    posicionAnterior = lecturaBruta; // Guardamos la nueva posición de anclaje
  }
  // Comprobamos si ha retrocedido 4 pulsos (1 click físico real a la izquierda)
  else if (posicionAnterior - lecturaBruta >= 4) {
    rollIzquierda = true;
    posicionAnterior = lecturaBruta;
  }

  if(!btnArriba && !btnOk && !btnAbajo && !btnIzquierda && !btnDerecha){repeatedButton = false;}

// ==============================================================================
//                                  INDICE SEGÚN MENÚ
// ==============================================================================
  
  switch(menusUI.menuActual){

    // --- MENÚ SECUENCIA ---
    case 0:
      gestionarMenu1();

      switch(seleccion){
        case 1:
          selectorNumSeq(); break;
        case 2:
          selectorModoSubdivisiones(); break;
        case 3:   
          selectorSubdivisiones(); break;
        case 4: 
          selectorPasos(); break;
      }
      break;
    // --- MENÚ CC ---
    case 1:
      gestionarMenu2();
      switch(seleccion){
        case 1:
          selectorNumSeqCC(); break;
        case 2:
          selectorPasos(); break;
        case 3:
          selectorSubdivisiones(); break;
      }
      break;
    // --- MENÚ CONFIGURACIÓN --- 
    case 2:
      switch(nMenuSettings){
        case 0:
          gestionarMenu3(); break;
        case 1:
          savePreset(); break;
        case 2:
          loadPreset(); break;
        case 3:
          deletePreset();
        case 4:
          selectorClock(); break;
        case 5:
          selectScale(); break;
        case 6:
          selectCCNumber(); break;
        case 7:
          break;
        case 8:
          verSequencia(); break;
      }
      break;
  }
}

// ==============================================================================
//                        NAVEGACIÓN DIRECCIONAL (D-PAD)
// ==============================================================================

void MenusButtons::gestionarMenu1(){
  if (!timeDebounce()) return;
  if (repeatedButton) return;
  if(btnSettings){
    menuActual = 2;
    seleccion = 1;
    nMenuSettings = 0;
    aplicarCambiosBotones();
    return;
  }
else if (btnExt){
    if(!editExtension){
      editExtension = true;
      editExtensionHistorial = true;
      syncWithActiveSequence();
      drawUI.updateValues = true;
    }
    else{
      editExtension = false;
      editExtensionHistorial = false;
      syncWithActiveSequence();
      drawUI.updateValues = true;
    }  
    aplicarCambiosBotones();
    return;
  }
  switch(seleccion){
    case 1:
      if(btnAbajo){ seleccion = 2; aplicarCambiosBotones(); }
      else if(btnDerecha){ seleccion = 4; aplicarCambiosBotones(); }
      break;
    case 2:
      if(btnArriba){ seleccion = 1; aplicarCambiosBotones(); }
      if(btnAbajo){ seleccion = 3; aplicarCambiosBotones(); }
      break;
    case 3:
      if(btnArriba) {seleccion = 2; aplicarCambiosBotones(); }
      break;
    case 4:
      if(btnIzquierda){ seleccion = 1; aplicarCambiosBotones(); }
      if(btnAbajo){ seleccion = 2; aplicarCambiosBotones(); }
      break;
  }
}

void MenusButtons::gestionarMenu2(){
  if (!timeDebounce()) return;
  if (repeatedButton) return;

  if(btnSettings){
    menuActual = 2;
    seleccion = 1;
    nMenuSettings = 0;
    aplicarCambiosBotones();
    return;
  }

  switch(seleccion){
    case 1:
      if(btnDerecha){ seleccion = 2; aplicarCambiosBotones(); }
      break;
    case 2:
      if(btnIzquierda){ seleccion = 1; aplicarCambiosBotones(); }
      else if(btnAbajo){ seleccion = 3; aplicarCambiosBotones(); }
      break;
    case 3:
      if(btnArriba){ seleccion = 2; aplicarCambiosBotones(); }
      break;
  }
}

void MenusButtons::gestionarMenu3(){
  if (!timeDebounce()) return;
  if (repeatedButton) return;
  if(btnSettings){
    if((menuActual == 2) && nMenuSettings == 0){
      putNameFlag = false;
      if(s->seqMode == 0){menuActual = 0;}
      else if(s->seqMode == 1){menuActual = 1;}
      aplicarCambiosBotones();
      return;
    }
  }
  switch(seleccion){
    case 1:
      if(btnAbajo){ seleccion = 2; aplicarCambiosBotones(); }
      else if(btnOk){
        nMenuSettings = 1;
        seleccion = 1;
        strcpy(midiUI.charNumber, "        "); // Limpiamos el nombre  
        aplicarCambiosBotones();
      }
      break;
    case 2:
      if(btnArriba){ seleccion = 1; aplicarCambiosBotones(); }
  if(btnAbajo){ seleccion = 3; aplicarCambiosBotones(); }
      else if(btnOk){ nMenuSettings = 2; seleccion = 1; aplicarCambiosBotones(); }
      break;
    case 3:
      if(btnArriba){ seleccion = 2; aplicarCambiosBotones(); }
      else if(btnAbajo){ seleccion = 4; aplicarCambiosBotones(); }
      else if(btnOk){ nMenuSettings = 3; seleccion = 1; aplicarCambiosBotones(); }
      break;
    case 4:
      if(btnArriba){ seleccion = 3; aplicarCambiosBotones(); }
      else if(btnAbajo){ seleccion = 5; aplicarCambiosBotones(); }
      else if(btnOk){ nMenuSettings = 4; seleccion = 1; aplicarCambiosBotones(); }
      break;
    case 5:
      if(btnArriba){ seleccion = 4; aplicarCambiosBotones(); }
      else if(btnAbajo){ seleccion = 6; aplicarCambiosBotones(); }
      else if(btnOk){ nMenuSettings = 5; seleccion = 1; aplicarCambiosBotones(); }
      break;
    case 6:
      if(btnArriba){ seleccion = 5; aplicarCambiosBotones(); }
      else if(btnAbajo){ seleccion = 7; aplicarCambiosBotones(); }
      else if(btnOk){ nMenuSettings = 6; seleccion = 1; aplicarCambiosBotones(); }
      break;
    case 7:
      if(btnArriba){ seleccion = 6; aplicarCambiosBotones(); }
      else if(btnAbajo){ seleccion = 8; aplicarCambiosBotones(); }
      else if(btnOk){ 
        for(int i = 0; i < N_MAX_SEQS; i++){
          midiProg[i].notaExterna = 0; aplicarCambiosBotones(); 
        }
      }
    case 8:
      if(btnArriba){ seleccion = 7; }
      else if(btnOk){ nMenuSettings = 8; seleccion = 1; aplicarCambiosBotones(); }
      break;
  }
}

// ==============================================================================
//                            MODIFICACIÓN DE VALORES
// ==============================================================================

void MenusButtons::selectorNumSeq(){
  if (!timeDebounce()) return;
  if (repeatedButton) return;

  if (rollDerecha) {
    presetsUI.indexSequence = (presetsUI.indexSequence + 1) % N_MAX_SEQS; // Cuando supera el número máximo de secuencia, vuelve a 0
    checkSeqMode();
    aplicarCambiosEncoder();
  }
  else if (rollIzquierda) {
    presetsUI.indexSequence = (presetsUI.indexSequence - 1 + N_MAX_SEQS) % N_MAX_SEQS; // Cuando supera el número máximo de secuencia, vuelve a N_MAX_SEQS
    checkSeqMode();
    aplicarCambiosEncoder();
  }
  else if (btnOk){
    menuActual = 1;
    s = presetsUI.getActiveSequence();
    s->seqMode = 1;
    curSubdivMode = 0;
    commitSequenceChanges();
    aplicarCambiosBotones();
  }
  
  resetEncoder();
}

void MenusButtons::selectorModoSubdivisiones(){
  if (!timeDebounce()) return;  

  if (rollDerecha) { 
    curSubdivMode ++;
    if(curSubdivMode > 2){ curSubdivMode = 0; }
    
    // Logica de adaptación de valores
    if (curSubdivMode == 0) {
      if(SEQ.play){
        curSubdivMode = 2;
        cambioModo0[presetsUI.indexSequence] = true;
      }
      curIndSubdiv = ultimaConfiguracionModo0;
      SEQ.subdivision = SEQ.subdivisionesArray[curIndSubdiv];
    }

    else if (curSubdivMode == 1) {
      curIndSubdiv = ultimaConfiguracionModo1;
      SEQ.subdivision = SEQ.subdivisionesArray[curIndSubdiv];
    }

    else if (curSubdivMode == 2){
      if(SEQ.play){
        curSubdivMode = 1;
        cambioModo2[presetsUI.indexSequence] = true;
      }
      curindComplexSubdivX = ultimaConfiguracionModo2[0];
      curindComplexSubdivY = ultimaConfiguracionModo2[1];
      selectNum = true;
    }
    aplicarCambiosEncoder();
  }

  if (rollIzquierda) { 
    curSubdivMode --;
    if(curSubdivMode == 255){curSubdivMode = 2;} // 255 es el Underflow de un byte al restar de 0
    
    // Logica de adaptación de valores
    if (curSubdivMode == 0) {
      curIndSubdiv = ultimaConfiguracionModo0;
      SEQ.subdivision = SEQ.subdivisionesArray[curIndSubdiv];
    }

    else if (curSubdivMode == 1) {
      if(SEQ.play){
        curSubdivMode = 2;
        cambioModo1[presetsUI.indexSequence] = true;
      }
      curIndSubdiv = ultimaConfiguracionModo1;
      SEQ.subdivision = SEQ.subdivisionesArray[curIndSubdiv];
    }

    else if (curSubdivMode == 2){
      if(SEQ.play){
        curSubdivMode = 0;
        cambioModo2[presetsUI.indexSequence] = true;
      }
      curindComplexSubdivX = ultimaConfiguracionModo2[0];
      curindComplexSubdivY = ultimaConfiguracionModo2[1];
      selectNum = true;}
    aplicarCambiosEncoder();
  }

  commitSequenceChanges();
  resetEncoder();
}

void MenusButtons::selectorSubdivisiones(){
  if (!timeDebounce()) return;
  switch(curSubdivMode){
    case 0: gestionSubdivGlobal(); break;
    case 1: gestionSubdivBinaria(); break;
    case 2: gestionSubdivCompleja(); break;
  }
}

void MenusButtons::gestionSubdivGlobal(){
  if (rollDerecha) {
    if (curIndSubdiv < 10){
      curIndSubdiv++;
      ultimaConfiguracionModo0 = curIndSubdiv;
      aplicarCambiosEncoder();
    }
  }
  else if (rollIzquierda) {
    if (!timeDebounce()) return;{
      if (curIndSubdiv > 0){
        curIndSubdiv--;
        ultimaConfiguracionModo0 = curIndSubdiv;
        aplicarCambiosEncoder();
      }
    }
  }
  commitSequenceChanges();
  resetEncoder();
}

void MenusButtons::gestionSubdivBinaria(){
  if (rollDerecha) {
    if (curIndSubdiv < 10){
      curIndSubdiv += 2;
      ultimaConfiguracionModo1 = curIndSubdiv;
      aplicarCambiosEncoder();
    }
  }
  else if (rollIzquierda) {
    if (curIndSubdiv > 1){
      curIndSubdiv -= 2;
      ultimaConfiguracionModo1 = curIndSubdiv;
      aplicarCambiosEncoder();
    }
  }
  commitSequenceChanges();
  resetEncoder();
}

void MenusButtons::gestionSubdivCompleja(){
  if (rollDerecha) {
    if(selectNum && curindComplexSubdivX < 5){
      curindComplexSubdivX++;
      ultimaConfiguracionModo2[0] = curindComplexSubdivX;
      if(curindComplexSubdivY == 2 && curindComplexSubdivX > 2){curindComplexSubdivX = 2;}
      aplicarCambiosEncoder();
    }
    if(selectDen && curindComplexSubdivY < 2){
      curindComplexSubdivY++;
      ultimaConfiguracionModo2[1] = curindComplexSubdivY;
      if(curindComplexSubdivY == 2 && curindComplexSubdivX > 2){curindComplexSubdivX = 2;}
      aplicarCambiosEncoder();
    }
  }
  else if (rollIzquierda) {
    if(selectNum && curindComplexSubdivX > 0){
      curindComplexSubdivX--;
      ultimaConfiguracionModo2[0] = curindComplexSubdivX;
      aplicarCambiosEncoder();
    }
    if(selectDen && curindComplexSubdivY > 0){
      ultimaConfiguracionModo2[1] = curindComplexSubdivY;
      curindComplexSubdivY--;
      aplicarCambiosEncoder();
    }
  }
  else if (btnOk){
    if(curSubdivMode == 2 && seleccion == 3){
      selectNum = !selectNum;
      selectDen = !selectDen;
      aplicarCambiosBotones(); 
    }
  }
  commitSequenceChanges();
  resetEncoder();
}

void MenusButtons::selectorPasos(){
  if (!timeDebounce()) return;

  if (rollDerecha) {
    if(curTotalSteps < N_MAX_STEPS){ curTotalSteps++; aplicarCambiosEncoder(); }
  }

  else if (rollIzquierda) {
    if(curTotalSteps > 1){ curTotalSteps--; aplicarCambiosEncoder(); }
  }
  commitSequenceChanges();
  resetEncoder();
}

void MenusButtons::selectorNumSeqCC(){
  if (!timeDebounce()) return;
  if (repeatedButton) return;
  editExtension = false;

  if (rollDerecha) {
    presetsUI.indexSequence = (presetsUI.indexSequence + 1) % N_MAX_SEQS;
    checkSeqMode();
    aplicarCambiosEncoder();
  }
  else if (rollIzquierda) {    
    presetsUI.indexSequence = (presetsUI.indexSequence - 1 + N_MAX_SEQS) % N_MAX_SEQS;
    checkSeqMode();
    aplicarCambiosEncoder();
  }
  else if (btnOk){
    menusUI.menuActual = 0;
    s->seqMode = 0;
    if(editExtensionHistorial){ editExtension = true; }
    aplicarCambiosBotones();
  }
  resetEncoder();
}

void MenusButtons::showPotes(){  // 3. nClockMsgrizador para salir de la pantalla de potenciómetro
  if (menusUI.menuActual == 3 && (tiempoActualMillis - midiUI.timeShowPotValue >= 1500)) {
    menusUI.menuActual = menuAnterior;
    drawUI.updateLCD = true;
  }
}

############################################################
### ARCHIVO: menus_buttons.h
############################################################

#ifndef MENUS_BUTTONS_H
#define MENUS_BUTTONS_H

#include <Arduino.h>
#include "config.h"

struct Sequence;
struct Step;

extern unsigned long tiempoActualMillis;

// ==============================================================================
//                                CLASE PRINCIPAL
// ==============================================================================

class MenusButtons {
  private:
    Sequence* s;
    Step* stp;

    // --- Variables de la secuencia ---
    byte curTotalSteps;
    byte curSubdivMode;
    byte curIndSubdiv;
    byte curindComplexSubdivY;
    byte curindComplexSubdivX;

// ==============================================================================
//                         DECLARACION DE FUNCIONES 
// ==============================================================================

    //Funciones del selector y gestion pantallas
    void gestionarMenu1(); //Notas
    void gestionarMenu2(); //CC
    void gestionarMenu3(); //Settings
    
    // --- Menu notas ---
    void selectorNumSeq();
    void selectorModoSubdivisiones();
    void selectorSubdivisiones();
    void gestionSubdivGlobal();
    void gestionSubdivBinaria();
    void gestionSubdivCompleja();
    void selectorPasos();

    // --- Menu CC ---
    void selectorNumSeqCC();
    
    // --- Menu settings ---
    void savePreset();
    void loadPreset();
    void deletePreset();
    void selectorClock();
    void selectScale();
    void selectCCNumber();
    void verSequencia();

    // --- Funciones de control y actualización ---
    bool timeDebounce();
    void comeBack();
    void scroll();
    void syncWithActiveSequence();
    void commitSequenceChanges();
    void aplicarCambiosBotones();
    void aplicarCambiosEncoder();
    void checkSeqMode();
    void resetEncoder();
    void showPotes();

  public:
  MenusButtons();

    // ==============================================================================
    //                                    VARIABLES 
    // ==============================================================================

    //Variables pines
    const byte pinButton1 = 29; // Arriba
    const byte pinButton2 = 18; // OK / Entrar
    const byte pinButton3 = 25; // Izquierda
    const byte pinButton4 = 23; // Abajo
    const byte pinButton5 = 27; // Derecha

    const byte extPin = 39;

    const byte settingsPin = 30;

    // Bool Botones
    bool btnArriba;
    bool btnOk;
    bool btnAbajo;
    bool btnIzquierda;
    bool btnDerecha;
    bool btnSettings;
    bool btnExt;

    // Variables Navegacion
    byte menuActual;
    byte menuAnterior;
    byte nMenuSettings;
    byte seleccion;
    bool selectNum;
    bool selectDen;

    // Varibles Configuracion
    byte whatSaveSelect = 0;
    bool putNameFlag;
    int index;
    int maxIndex;
    int scrollOffset;
    byte cursorPos;
    bool deleteConfirm;
    bool editExtension;
    bool editExtensionHistorial;

    // Variables indicies subdivisiones
    byte ultimaConfiguracionModo0;
    byte ultimaConfiguracionModo1;
    byte ultimaConfiguracionModo2[2];
    bool cambioModo0[N_MAX_SEQS];
    bool cambioModo1[N_MAX_SEQS];
    bool cambioModo2[N_MAX_SEQS];

    // Variables Enconder
    long posicionActual;
    long posicionAnterior;
    bool rollDerecha;
    bool rollIzquierda;

    // Variables de control
    bool repeatedButton;

    // Variables de tiempo real
    unsigned long ultimoTiempoBotonMenu;
    unsigned long ultimoTiempoBotonPresets;

    //Declaración funciones públicas
    void checkMenuButtons();

};
extern MenusButtons menusUI;
extern void funcionInterrupcion();

#endif

############################################################
### ARCHIVO: midiInterface.cpp
############################################################

#include <Arduino.h>
#include <MIDI.h>
#include "MidiInterface.h"
#include "menus_buttons.h"
#include "MidiProgramming.h"
#include "midiPresets.h"
#include "draw_menus.h"
#include "config.h"

#define SEQ midiProg[presetsUI.indexSequence]

// Números Mágicos
MidiInterface midiUI;

MidiInterface::MidiInterface(){
  // Inicialización si fuera necesaria en el futuro
};

// ==============================================================================
//                                FUNCIONES UTILES 
// ==============================================================================

void MidiInterface::syncWithActiveSequence() {
  s = presetsUI.getActiveSequence();
  stp = menusUI.editExtension ? s->ext_steps : s->steps;
}

bool MidiInterface::timeDebounce(unsigned long boton, int time){
  return (tiempoActualMillis - boton >= time);
}

// ==============================================================================
//                      LECTURA Y DETECCIÓN DE BOTONES 
// ==============================================================================

void MidiInterface::checkMidiButtons() {
  syncWithActiveSequence();

  // --- LECTURA FISICA ---
  bool octPlus = !digitalRead(pinOctPlus);
  bool octRest = !digitalRead(pinOctRest);

  bool playButton = !digitalRead(playPinButton);
  bool stopButton = !digitalRead(stopPinButton);

  for(int i = 0; i < N_MAX_SEQS; i++){
    seqButton[i] = !digitalRead(seqPinsButton[i]);
  }

  // CONTROL: --- PLAY/PAUSE/STOP ---
  if(playButton && timeDebounce(ultimoTiempoBotonDevicePlay, 500)){
    if(deviceStop){
      deviceStop = false;
      deviceFlagPlay = true;
      drawUI.nAnteriorScreen = 200;
    }
    else{ devicePlay = !devicePlay; } // pausa < -- > play

    ultimoTiempoBotonDevicePlay = tiempoActualMillis;
    drawUI.updateLCD = true;
  }

  if(stopButton && timeDebounce(ultimoTiempoBotonDevicePlay, 500)){
    deviceStop = true; // Stop
    devicePlay = false;
    ultimoTiempoBotonDevicePlay = tiempoActualMillis;
    drawUI.updateLCD = true;
  }

  // --- CONTROL: PARPADEO DE LOS LEDS ---
  if(!midiUI.devicePlay && !midiUI.deviceStop){
    if(timeDebounce(tiempoLedPausa, 500)){
      ledState = !ledState;
      tiempoLedPausa = tiempoActualMillis;
    }
  }

  // Actualización del parpadeo
  for(int i = 0; i < N_MAX_SEQS; i++){
    if(midiUI.deviceStop || !p->nSequence[i].armed){
      digitalWrite(seqPinLed[i], LOW);
    }
    else{
      if(menusUI.editExtension){
        if(!p->nSequence[i].extensionArmed){digitalWrite(seqPinLed[i], LOW);}
        else{digitalWrite(seqPinLed[i], p->nSequence[i].extensionArmed ? HIGH : ledState);}  
      }
      else{digitalWrite(seqPinLed[i], midiUI.devicePlay ? HIGH : ledState);}
    }
  }

  // --- CONTROL: ARMADO DE LAS SECUENCIAS ---
  for(int i = 0; i < N_MAX_SEQS; i++){
    if(seqButton[i]){
      seqArmPulsed[i] = true;
      if(seqArmPulsed[i] && timeDebounce(ultimoTiempoBotonArm, 500)){
        if(menusUI.editExtension){
          p->nSequence[i].extensionArmed = !p->nSequence[i].extensionArmed;
        }
        else{
          if(!p->nSequence[i].armed){
            if(MidiProgramming::modeMidiClock == 0){
              if(midiProg[i].play){MidiProgramming::flagArmed[i+seqLayer] = true;}
              else{p->nSequence[i].armed = true;}
            }
            else if(MidiProgramming::modeMidiClock == 1){MidiProgramming::tipoMsgMidi = 0xFA;}
          }
          else if(p->nSequence[i].armed){
            if(MidiProgramming::modeMidiClock == 0){p->nSequence[i+seqLayer].armed = false;}
            else if(MidiProgramming::modeMidiClock == 1){MidiProgramming::tipoMsgMidi = 0xFC;}
            digitalWrite(seqPinLed[i], LOW);
          }
        }
        ultimoTiempoBotonArm = tiempoActualMillis;
      }
      break;
    }
    else{
      seqArmPulsed[i] = false;
    }
  }
  // Flag de detección de botones de octava
  if (octPlus && !octPlusPulsed) { octPlusPulsed = true; }
  if (octRest && !octRestPulsed) {  octRestPulsed = true; }

// ==============================================================================
//                          CONTROL DE LOS MUTES 
// ==============================================================================

  for (int i = 0; i < NUM_MUTES; i++) {
    bool mute = !digitalRead(mutesPin[i]);
    // ----------------------------- MUTE ACTIVADO -----------------------------
    if (mute) {
      // Deteccion del mute y guardado de su estado
      if (mutePulsado[i] == false) {
        mutePulsado[i] = true;
        muteActivado = true;
        TiempoPulsadoBotonMute[i] = tiempoActualMillis;
        indexMovedMute = i;
        for(int p = 0; p < NUM_POTES; p++){
          poteBlocked[p] = true;
        }
      }
      if (timeDebounce(TiempoPulsadoBotonMute[i], 100) && timeDebounce(ultimoTiempoBotonMute[i], 500)) { // Guardado del tiempo de pulsado
        ultimoTiempoBotonMute[i] = tiempoActualMillis;
      }

      // --- SUBIR OCTAVA + MUTE ---
      if (octPlusPulsed && timeDebounce(ultimoTiempoBotonOct, 500) && stp[i].octave < 9) {
        ultimoTiempoBotonOct = tiempoActualMillis;
        stp[i].octave++;
        menusUI.menuActual = 4;
        drawUI.updateLCD = true;
        pulsedIndividualOctave = true; // octava de la nota que hemos seleccionado con el mute
      }

      // --- BAJAR OCTAVA + MUTE ---
      else if (octRestPulsed && timeDebounce(ultimoTiempoBotonOct, 500) && stp[i].octave > 0) {
        ultimoTiempoBotonOct = tiempoActualMillis;
        stp[i].octave--;
        menusUI.menuActual = 4;
        drawUI.updateLCD = true;
        pulsedIndividualOctave = true;
      }
    }

    // ----------------------------- MUTE LIBERADO -----------------------------
    else {
      // --- SE ACABA DE LEVANTAR EL BOTÓN DEL MUTE ---
      if (mutePulsado[i] == true && !pulsedIndividualOctave && !octPlusPulsed && !octRestPulsed && !poteMovidoMutes) {
        if(menusUI.putNameFlag){charNumber[i] = 32;} // Si estamos en modo edicion de nombre, escribe un espacio, Sino cambia el valor del mute.
        if(s->seqMode == 0 && !menusUI.putNameFlag){stp[i].mutes = !stp[i].mutes;} 
        else if(s->seqMode == 1 && !menusUI.putNameFlag){stp[i].ccMutes = !stp[i].ccMutes;}

        drawUI.updateLCD = true;
        mutePulsado[i] = false;
        muteActivado = false;
      }
      // reseteo de los flags de los botones activados de octavas individuales
      else if (mutePulsado[i] == true && pulsedIndividualOctave) {
        mutePulsado[i] = false;
        muteActivado = false;
        pulsedIndividualOctave = false;
      }
      // reseteo de los flags de los mutes y de los potenciometros
      else if(mutePulsado[i] == true && poteMovidoMutes){
        mutePulsado[i] = false;
        poteBlocked[i] = true;
        muteActivado = false;
        poteMovidoMutes = false;
      }
    }
  }

  // // ----------------------------- OCTAVAS GLOBALES -----------------------------
  if (!octPlus && octPlusPulsed && timeDebounce(ultimoTiempoBotonOct, 250)) { octPlusPulsed = false; } // Reseteo de los flags de las octavas
  if (!octRest && octRestPulsed && timeDebounce(ultimoTiempoBotonOct, 250)) { octRestPulsed = false; }

  // Subimos la octava a TODA la secuencia
  if (!muteActivado && octPlusPulsed && timeDebounce(ultimoTiempoBotonOct, 500)) {
    ultimoTiempoBotonOct = tiempoActualMillis;
    for (int i = 0; i < N_MAX_STEPS; i++) {
      if(p->nSequence[presetsUI.indexSequence].steps[i].octave < 9){p->nSequence[presetsUI.indexSequence].steps[i].octave++;}
      if(s->ext_steps[i].octave < 9){s->ext_steps[i].octave++;}
    }
    menusUI.menuActual = 5;
    drawUI.updateLCD = true;
  } 
  
  // Bajamos la octava a TODA la secuencia
  else if (!muteActivado && octRestPulsed && timeDebounce(ultimoTiempoBotonOct, 500)) {
    ultimoTiempoBotonOct = tiempoActualMillis;
    for (int i = 0; i < N_MAX_STEPS; i++) {
      if(p->nSequence[presetsUI.indexSequence].steps[i].octave > 0){p->nSequence[presetsUI.indexSequence].steps[i].octave--;}
      if(s->ext_steps[i].octave > 0){s->ext_steps[i].octave--;}
    }
    menusUI.menuActual = 5;
    drawUI.updateLCD = true;
  }
}

// ==============================================================================
//                          DETECCIÓN DE LOS POTENCIÓMETROS 
// ==============================================================================

void MidiInterface::checkPotes() {
  // --- LECTURA DE LOS POTES ---
  for (int i = 0; i < NUM_POTES; i++) {
    int val = analogRead(potesPin[i]);

    if(abs(val - potSaveValue[i]) <= 20) continue; // Hasta que no lleguemos al valor guardado, no cambiará nada para evitar saltos
    // ---------------- MUTE PRESIONADO (Edición Secundaria) ----------------
    if(muteActivado){
      // --- VELOCITY ---
      if(s->seqMode == 0){
        int velMapping = constrain(map(val, MAX_POTE_VALUE, MIN_POTE_VALUE, 0, 127), 0, 127);
        if(poteBlocked[i]){ // si el valor del pote y el guardado coinciden, el pote puede empezar a guardar datos
          if (abs(velMapping - stp[i].velocity) <= 5) poteBlocked[i] = false;
          else continue;
        }
        stp[i].velocity = velMapping;
        aplicarCambiosPotes(stp[i].velocity, i);
        poteMovidoMutes = true;
        potSaveValue[i] = val;
      }
      // --- CANTIDAD DE SMOOTH ---
      else if(s->seqMode == 1){
        int potCentrado = constrain(map(val, 900, 80, 0, 12), 0, 12);
        if(poteBlocked[i]){
          if (abs(potCentrado - stp[i].ccSmoothCurve) == 0) poteBlocked[i] = false;
          else continue;
        }
        stp[i].ccSmoothCurve = potCentrado;
        aplicarCambiosPotes(stp[i].ccSmoothCurve, i);
        poteMovidoMutes = true;
        potSaveValue[i] = val;
      }
    }

    // ---------------- MUTE NO PRESIONADO (Edición Principal) ----------------
    else{
      // --- ESCRITURA DEL NOMBRE ---
      if(menusUI.putNameFlag){
        byte index = constrain(map(val, MAX_POTE_VALUE, MIN_POTE_VALUE, 0, 35), 0, 35);
        if(index <= 9){ charNumber[i] = index + 48; } 
        else{ charNumber[i] = index + 55; }
        potSaveValue[i] = val;
      }

      // --- NOTAS ---
      else if(s->seqMode == 0 && !menusUI.putNameFlag){
        // Mapeamos según la cantidad de notas que tenga nuestra escala.
        int notaEscala = constrain(map(val, MAX_POTE_VALUE, MIN_POTE_VALUE, 0, SEQ.nNotasEscalas[s->escalaSeleccionada] - 1), 0, SEQ.nNotasEscalas[s->escalaSeleccionada] - 1);
        // Y = escala seleccionada;  X = Numero de la nota de la escala
        int noteMapping = SEQ.escalasNotas[s->escalaSeleccionada][notaEscala] + s->noteTone;

        if(poteBlocked[i]){ 
          if (abs(noteMapping - stp[i].note) == 0) poteBlocked[i] = false; 
          else continue;
        }
        stp[i].note = noteMapping;
        aplicarCambiosPotes(stp[i].note, i);
        poteMovidoMutes = true;
        potSaveValue[i] = val;
      }

      // --- VALOR CC ---
      else if(s->seqMode == 1 && !menusUI.putNameFlag){
        int valorCC = constrain(map(val, MAX_POTE_VALUE, MIN_POTE_VALUE, 0, 127), 0, 127);
        if(poteBlocked[i]){
          if (abs(valorCC - stp[i].ccValue) < 5) poteBlocked[i] = false;
          else continue;
        }
        stp[i].ccValue = valorCC;
        aplicarCambiosPotes(stp[i].ccValue, i);
        poteMovidoMutes = true;
        potSaveValue[i] = val;
      }
    }
  }
}

// Enviamos los valores a la funcion draw_menus para su dibujado
void MidiInterface::aplicarCambiosPotes(int sendValue, int nPote){
  movedPoteValue = sendValue;
  movedPoteNumber = nPote;
  timeShowPotValue = tiempoActualMillis;
  if(s->seqMode == 0){menusUI.menuActual = 3;}
  drawUI.updateLCD = true;
}

############################################################
### ARCHIVO: midiInterface.h
############################################################

#ifndef MidiInterface_H
#define MidiInterface_H

// ==============================================================================
//                                CONFIGURACIÓN
// ==============================================================================

#define NUM_POTES 16
#define NUM_MUTES 16

#include <Arduino.h>
#include <MIDI.h>
#include "config.h"

// Declaraciones adelantadas (Forward declarations)
struct Sequence;
struct Step;
extern unsigned long tiempoActualMillis;

// ==============================================================================
//                                CLASE PRINCIPAL
// ==============================================================================

class MidiInterface {
  private:
    Sequence* s; // Puntero a la secuencia activa
    Step* stp;

  public:
    MidiInterface();

    // --- PINES DE HARDWARE (Constantes) ---
    const byte potesPin[NUM_POTES]       = {A0, A1, A2, A3, A4, A5, A6, A7,A8, A9, A10, A11, A12, A13, A14, A15};
    
    const byte mutesPin[NUM_MUTES]       = {47, 43, 45, 41, 3, 49, 14, 48,46,44,42,4,5,6,7,8};
    const byte seqPinsButton[N_MAX_SEQS] = {32, 34, 36, 38, 40};
    const byte pinOctRest                = 22;
    const byte pinOctPlus                = 24;
    const byte stopPinButton             = 28;
    const byte playPinButton             = 26;

    const byte seqPinLed[N_MAX_SEQS]    = {13,12,11,10,9};

    // --- VARIABLES DE ESTADO: TRANSPORTE Y SECUENCIAS ---
    bool devicePlay = false;
    bool deviceFlagPlay = false;
    bool deviceStop = false;
    bool ledState   = true;
    bool comandoEnviado;
    
    byte seqLayer = 0;
    bool seqButton[N_MAX_SEQS];
    bool seqArmPulsed[N_MAX_SEQS];

    // --- VARIABLES DE ESTADO: MUTES Y OCTAVAS ---
    bool muteActivado;
    bool mutePulsado[NUM_POTES];
    byte indexMovedMute;

    bool octPlusPulsed;
    bool octRestPulsed;   
    bool pulsedIndividualOctave;

    // --- VARIABLES DE ESTADO: POTENCIÓMETROS (Soft-Takeover) ---
    int  potSaveValue[NUM_POTES];
    bool poteBlocked[N_MAX_STEPS]; // Asumo que N_MAX_STEPS viene de config.h
    bool poteMovidoMutes;
    byte movedPoteValue;
    byte movedPoteNumber;

    // --- TEMPORIZADORES (Debounce y animaciones) ---
    unsigned long ultimoTiempoBotonMute[NUM_MUTES];
    unsigned long TiempoPulsadoBotonMute[NUM_MUTES];
    unsigned long ultimoTiempoBotonOct;
    unsigned long ultimoTiempoBotonArm;
    unsigned long ultimoTiempoBotonDevicePlay;
    unsigned long tiempoLedPausa;
    unsigned long timeShowPotValue;

    // --- BUFFERS Y DATOS ---
    char charNumber[9]; // Buffer para el nombre de los presets (8 chars + '\0')

    // --- MÉTODOS Y FUNCIONES ---
    void checkPotes();
    void checkMidiButtons();
    void syncWithActiveSequence();
    void aplicarCambiosPotes(int sendValue, int nPote);
    bool timeDebounce(unsigned long boton, int time);
};

extern MidiInterface midiUI;

#endif

############################################################
### ARCHIVO: midiPresets.cpp
############################################################

#include <Arduino.h>
#include <SdFat.h>
#include <SPI.h> 

#include "midiPresets.h"
#include "midiProgramming.h"
#include "menus_buttons.h"
#include "midiInterface.h"
#include "draw_menus.h"
#include "config.h"

MidiPresets presetsUI;

Pattern marcaPasos;
Pattern* p = &marcaPasos;

MidiPresets::MidiPresets() {
  indexSequence = 0;
}

// ==============================================================================
//                                FUNCIONES UTILES
// ==============================================================================

bool MidiPresets::timeDebounce(){
  return (tiempoActualMillis - ultimoTiempoBotonPresets >= DEBOUNCE_DELAY_MS);
}

void MidiPresets::aplicarCambiosBotones(){
  drawUI.updateLCD = true;
  ultimoTiempoBotonPresets = tiempoActualMillis;
  repeatedButton = true;
}

void MidiPresets::sdInit(){
  while (!sd.begin(chipSelect, SPI_HALF_SPEED)) {
    drawUI.sdErrorMsg();
    delay(1000);
  }
  drawUI.sdCheckMsg();
  drawUI.drawLoadProgress(5);
}

void MidiPresets::readSlotsButtons(){
  savePresetButton = !digitalRead(saveButton);
  for(int i = 0; i < 3; i++){
    slots[i] = !digitalRead(slotsPin[i]);
    if (slots[i]) (savePresetButton) ? slotSave(i) : slotLoad(i);
  }
  
  if(!slots[0] && !slots[1] && !slots[2] && !slots[3] && !loadPresetButton && !savePresetButton){repeatedButton = false;}

}

void MidiPresets::saveSeqSD(char* nombreBase, byte tipoGuardado){
  char rutaArchivo[32];   // Necesitamos un array más grande para toda la ruta
  char nombreArchivo[13]; 
  int longitud = 8;
  while(longitud > 0 && (nombreBase[longitud - 1] == ' ' || nombreBase[longitud - 1] == '-')){
    longitud--;
  }
  strncpy(nombreArchivo, nombreBase, longitud);
  nombreArchivo[longitud] = '\0';

  if(tipoGuardado == 0){
    strcat(nombreArchivo, ".SEQ"); 
    if(!sd.exists(F("SEQS"))){
      sd.mkdir(F("SEQS"));
    }
    sprintf(rutaArchivo, "SEQS/%s", nombreArchivo);  
  }
  else {
    strcat(nombreArchivo, ".PAT"); 
    if(!sd.exists(F("PATS"))){
      sd.mkdir(F("PATS"));
    }
    sprintf(rutaArchivo, "PATS/%s", nombreArchivo); 
  }

  // 4. ABRIR Y GUARDAR (¡Fíjate que ahora usamos rutaArchivo!)
  File miArchivo = sd.open(rutaArchivo, O_WRITE | O_CREAT | O_TRUNC);
  
  if(!miArchivo){
    Serial.println(F("Error abriendo/creando el archivo"));
    return;
  }

  if(tipoGuardado == 0){
    Sequence* seqActiva = getActiveSequence(); 
    byte idx = indexSequence; 
      
    // Escribimos los 5 bloques uno detrás de otro en el mismo archivo .SEQ
    miArchivo.write((const uint8_t *)&p->nSequence[idx], sizeof(Sequence));
    for(int i = 0; i < 4; i++){   
      miArchivo.write((const uint8_t *)&p->seq_slots[i][idx], sizeof(Sequence));
    }
  } 
  else{
    miArchivo.write((const uint8_t *)p, sizeof(Pattern));
  }

  miArchivo.close();
}

int MidiPresets::getFileCount(byte tipoCarga){
  int count = 0;
  // Abrimos la carpeta correspondiente
  File dir = sd.open(tipoCarga == 0 ? "SEQS" : "PATS");
  
  if(!dir) return 0; // Si no existe la carpeta, hay 0 archivos

  dir.rewindDirectory(); // Nos aseguramos de empezar desde el principio
  
  while(true){
    File entry = dir.openNextFile();
    if(!entry) break; // Si no hay más archivos, salimos del bucle
    
    // Si es un archivo (no una subcarpeta), sumamos 1
    if(!entry.isDirectory()){
      count++;
    }
    entry.close();
  }
  dir.close();
  return count;
}

void MidiPresets::getFileName(int index, byte tipoCarga, char* bufferSalida){
  File dir = sd.open(tipoCarga == 0 ? "SEQS" : "PATS");
  
  if(!dir){
    strcpy(bufferSalida, "EMPTY   "); 
    return;
  }

  dir.rewindDirectory();
  int currentIndex = 0;
  
  while(true){
    File entry = dir.openNextFile();
    if(!entry){
      strcpy(bufferSalida, "EMPTY   "); 
      break;
    }
    
    // 1. EL ESCUDO: Sacamos el nombre DE FORMA SEGURA antes de comprobar nada
    char nombreTemporal[20];
    entry.getName(nombreTemporal, 20);
    
    // 2. Comprobamos que no sea carpeta y que no sea un archivo oculto de Mac (punto inicial)
    if(!entry.isDirectory() && nombreTemporal[0] != '.'){
      
      if(currentIndex == index){
        // 3. Quitamos la extensión buscando el punto y cortando el texto ahí
        char* punto = strchr(nombreTemporal, '.');
        if(punto) *punto = '\0'; 
        
        // 4. COPIA SEGURA: Pasamos a tu bufferSalida (midiUI) exactamente 8 letras.
        int longitudNombre = strlen(nombreTemporal);
        for(int i = 0; i < 8; i++){
          if(i < longitudNombre){
            bufferSalida[i] = nombreTemporal[i];
          } else {
            bufferSalida[i] = ' '; // Relleno de espacios
          }
        }
        bufferSalida[8] = '\0'; // Cerramos el string de la interfaz con total seguridad
        
        entry.close();
        break; 
      }
      currentIndex++;
    }
    entry.close();
  }
  dir.close();
  int len = strlen(bufferSalida);
  while(len > 0 && bufferSalida[len - 1] == ' '){
    bufferSalida[len - 1] = '\0';
    len--;
  }
}

void MidiPresets::loadSeqSD(char* nombreBase, byte tipoCarga){
  char rutaArchivo[30];
  getFileRoot(nombreBase, tipoCarga, rutaArchivo);
  if(!sd.exists(rutaArchivo)){
    return;
  }
  File miArchivo = sd.open(rutaArchivo, O_READ);
  
  if(!miArchivo){
    return;
  }
  if(tipoCarga == 0){
    Sequence* seqActiva = getActiveSequence(); 
    byte idx = indexSequence;
    miArchivo.read((uint8_t *)&p->nSequence[idx], sizeof(Sequence));
    for(int i = 0; i < 4; i++){ 
      miArchivo.read((uint8_t *)&p->seq_slots[i][idx], sizeof(Sequence));
    }
  } 
  else {
    miArchivo.read((uint8_t *)p, sizeof(Pattern));
  }

  miArchivo.close();

  drawUI.updateLCD = true;
  drawUI.updateValues = true; 
}

void MidiPresets::deleteSeqSD(char* bufferSalida, byte tipoCarga){
  char rutaArchivo[30];
  getFileRoot(bufferSalida, tipoCarga, rutaArchivo);

  if(sd.exists(rutaArchivo)) sd.remove(rutaArchivo);
}

void MidiPresets::slotLoad(byte number){
  if (!timeDebounce()) return;
  if (repeatedButton) return;
  p->nSequence[indexSequence] = p->seq_slots[number][indexSequence];
  aplicarCambiosBotones();
}

void MidiPresets::slotSave(byte number){
  if (!timeDebounce()) return;
  if (repeatedButton) return;
  p->seq_slots[number][indexSequence] = p->nSequence[indexSequence];
  menusUI.menuActual = 6;
  nSlot = number + 1;
  aplicarCambiosBotones();
}

void MidiPresets::getFileRoot(char* bufferSalida, byte tipoCarga, char* rutaDestino){
  char nombreArchivo[13];
  // 1. Limpiamos los espacios en blanco del nombre (igual que al cargar)
  strcpy(nombreArchivo, bufferSalida);
  int longitud = strlen(nombreArchivo);
  while(longitud > 0 && nombreArchivo[longitud - 1] == ' '){
    longitud--;
  }
  nombreArchivo[longitud] = '\0';
  
  // 2. Montamos la ruta correcta
  if(tipoCarga == 0){
    strcat(nombreArchivo, ".SEQ"); 
    sprintf(rutaDestino, "SEQS/%s", nombreArchivo); 
  } 
  else {
    strcat(nombreArchivo, ".PAT"); 
    sprintf(rutaDestino, "PATS/%s", nombreArchivo); 
  }
}

############################################################
### ARCHIVO: midiPresets.h
############################################################

#ifndef MIDI_Presets_H
#define MIDI_Presets_H

#include <Arduino.h>
#include <SdFat.h>
#include "config.h"
#include "menus_buttons.h"

// ==============================================================================
//                           ESTRUCTURA DEL PATRÓN
// ==============================================================================

struct Step {
  byte note;
  byte ccValue;
  byte velocity;
  byte ccSmoothCurve;
  uint8_t mutes : 1;
  uint8_t ccMutes : 1;
  uint8_t octave : 4;
};

struct Sequence {
  Step steps[N_MAX_STEPS];
  Step ext_steps[N_MAX_STEPS];
  byte canal;
  byte seqMode;
  byte ccNumber;
  byte escalaSeleccionada;
  byte noteTone;

  byte nTotalSteps;
  byte subdivMode;
  byte indexSubdivisiones;
  byte indComplexSubdivY;
  byte indComplexSubdivX;

  byte ext_nTotalSteps;
  byte ext_subdivMode;
  byte ext_indexSubdivisiones;
  byte ext_indComplexSubdivY;
  byte ext_indComplexSubdivX;

  uint8_t armed : 1;
  uint8_t extensionArmed : 1;
};

struct Pattern {
  Sequence nSequence[N_MAX_SEQS];
  char nombreSequencia[10];
  Sequence seq_slots[3][N_MAX_SEQS];
};

struct sequenceState {
};
extern Pattern marcaPasos;
extern Pattern* p;

// ==============================================================================
//                                CLASE PRINCIPAL
// ==============================================================================

class MidiPresets {
  private:
    Sequence* s;
    Step* stp;
    SdFat sd;
    const byte chipSelect = 53; // Pin del lector de SDs
  public:
    MidiPresets();

// --- PINES ---
    const byte slotsPin[3] = {37, 35, 33};
    const byte saveButton = 31;

// --- Nº DE SECUENCIA ---
    byte indexSequence;

// --- SLOTS ---
    bool slots[3];
    byte nSlot;

// --- CONTROL DE LOS BOTONES Y TIEMPO ---
    bool loadPresetButton;
    bool savePresetButton;
    unsigned long ultimoTiempoBotonPresets;
    bool repeatedButton;

// --- PUNTEROS DE MEMORIA ---
    Sequence* getActiveSequence(){ return &marcaPasos.nSequence[indexSequence];}
    Sequence* getPlayedSequence(byte index){ return &marcaPasos.nSequence[index];}
// ==============================================================================
//                         DECLARACION DE FUNCIONES 
// ==============================================================================

// --- FUNCIONES UTILES ---
    bool timeDebounce();
    void aplicarCambiosBotones();
    void sdInit();
    void readSlotsButtons();

// --- FUNCIONES DE GUARDADO DE SECUENCIAS ---
    void saveSeqSD(char* nombreBase, byte tipoGuardado);
    void loadSeqSD(char* nombreBase, byte tipoCarga);
    void deleteSeqSD(char* bufferSalida, byte tipoCarga);
    void slotLoad(byte number);
    void slotSave(byte number);

// --- EXPLORADOR DE ARCHIVOS ---    
    int getFileCount(byte tipoCarga);
    void getFileRoot(char* bufferSalida, byte tipoCarga, char* rutaDestino);
    void getFileName(int index, byte tipoCarga, char* bufferSalida);
};

extern MidiPresets presetsUI;

#endif

############################################################
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

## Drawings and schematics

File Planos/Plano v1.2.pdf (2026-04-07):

26 77 Ø7 Ø7.5

250 | 500 Ø9 | 54 211.5

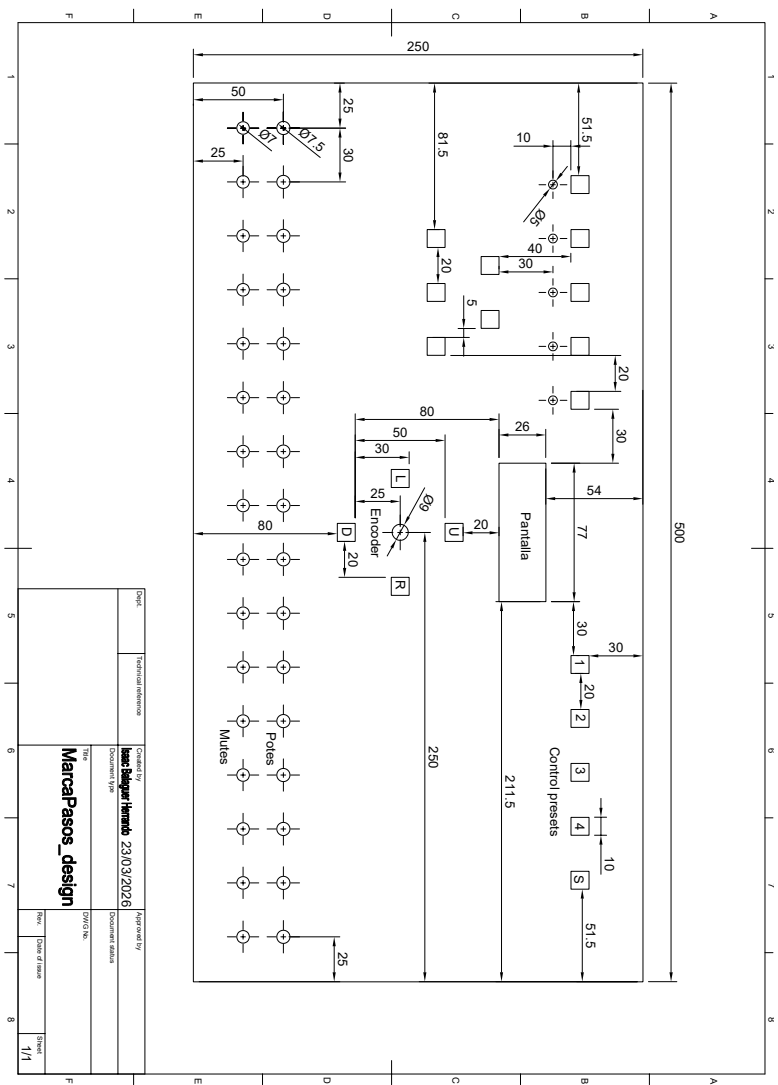
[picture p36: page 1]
Pantalla U L R D Potes Mutes; Encoder; Control presets

1 A 2 3 4 5 6 7 8 1 2 3 4 5 6 7 8 FEDCB FEDCBA Dept. Technical reference Created by Approved by Title DWG No. Document type Document status Rev. Date of issue Sheet 23/03/2026 1/1

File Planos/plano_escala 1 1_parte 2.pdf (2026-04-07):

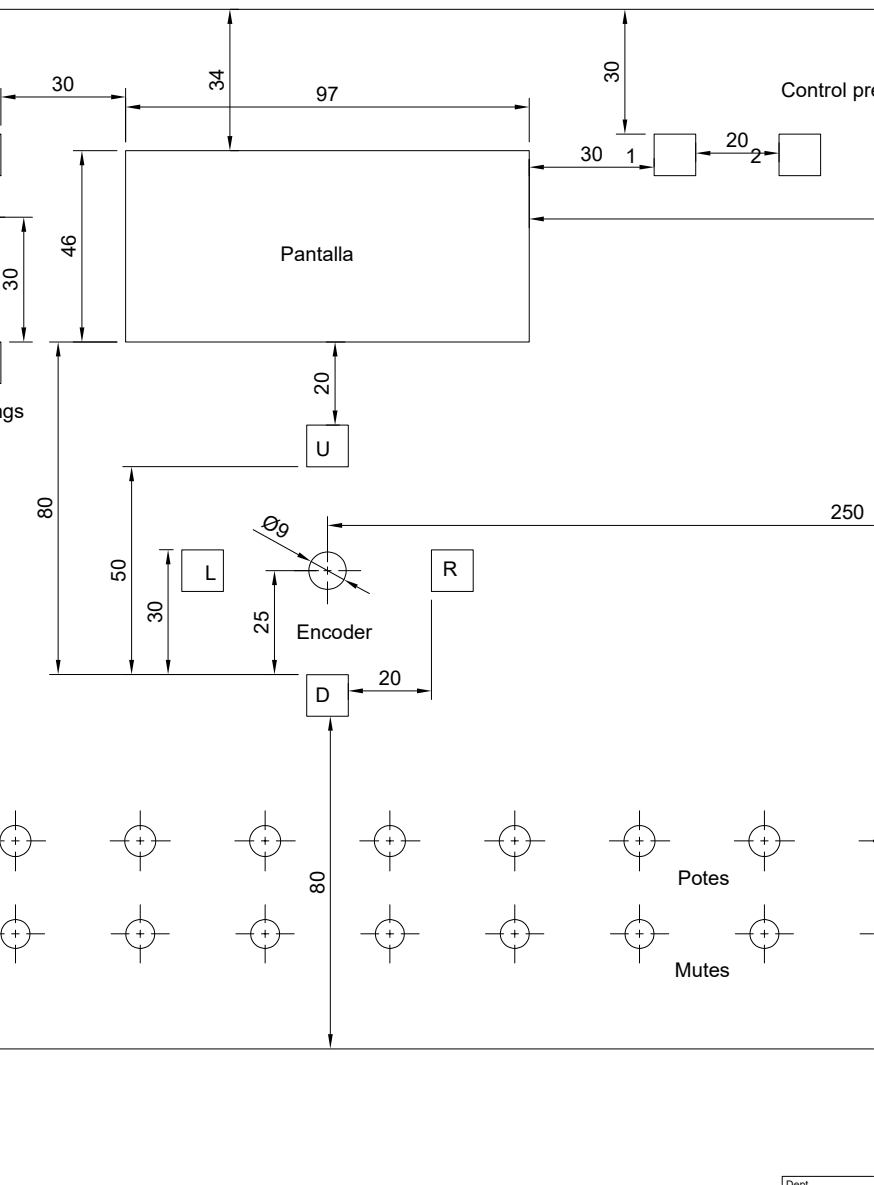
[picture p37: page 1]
Dept. 46; Pantalla; Potes; Mutes; Encoder; Control pre; ngs

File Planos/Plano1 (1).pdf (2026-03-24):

250

50

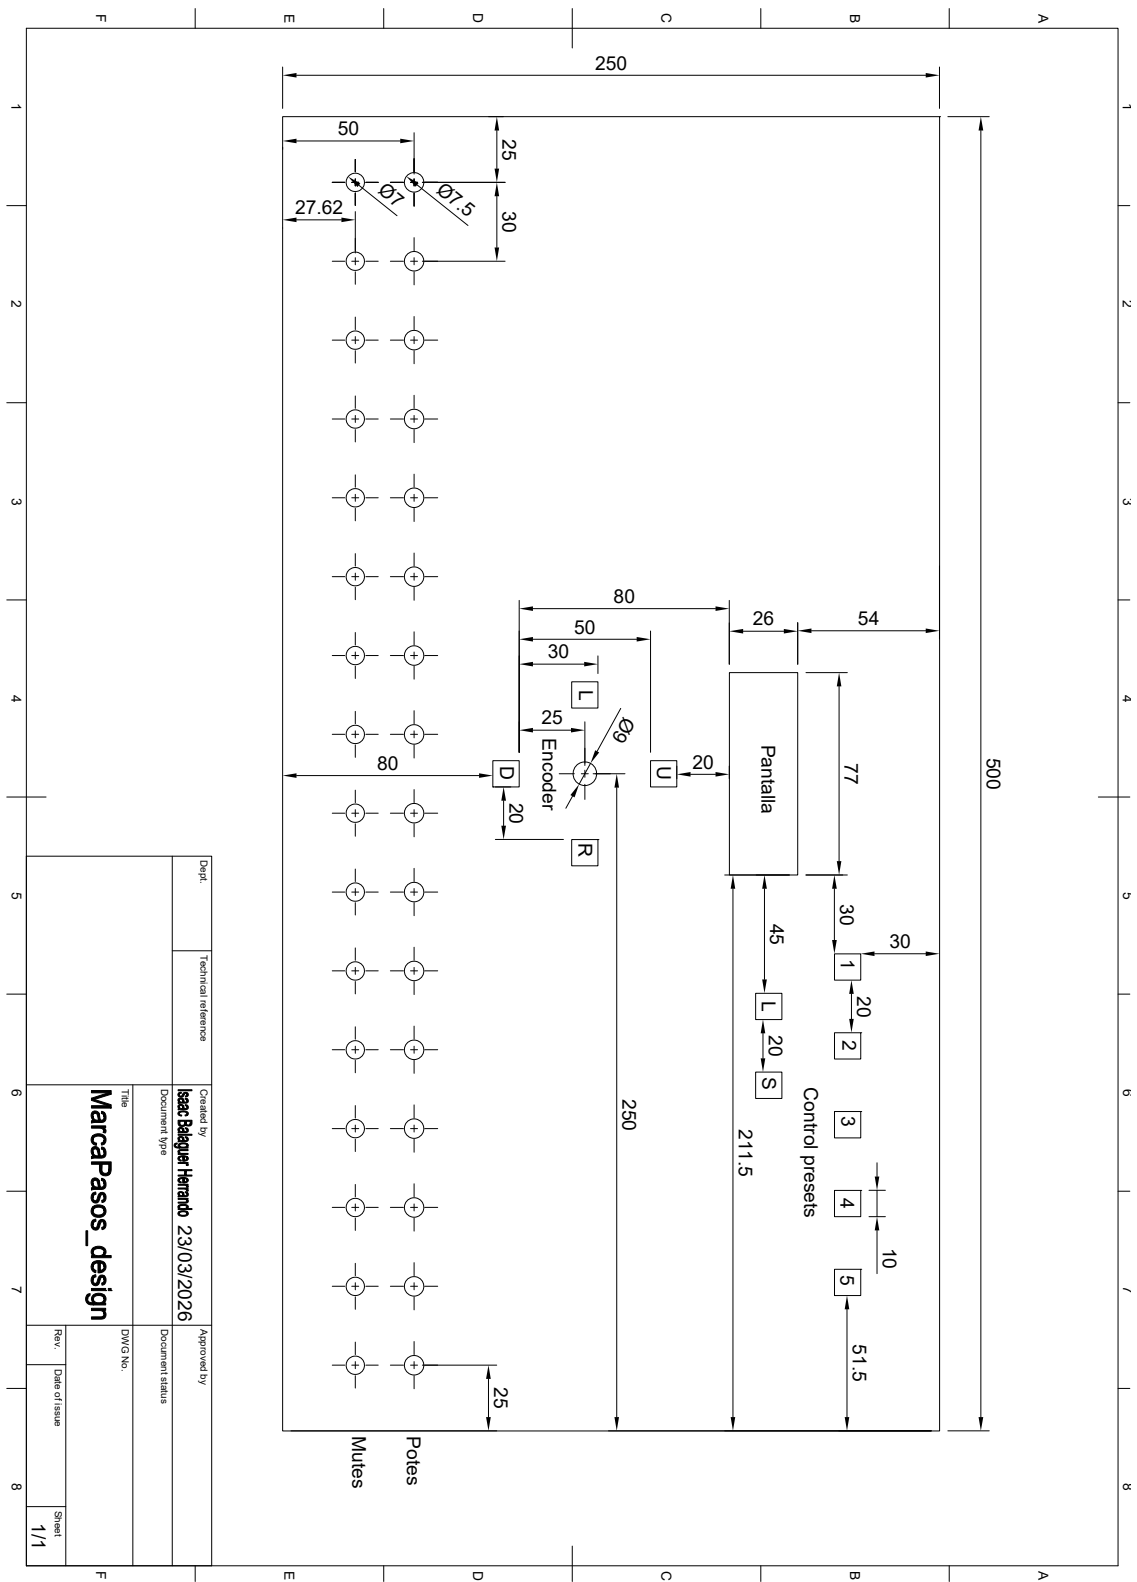
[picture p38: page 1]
Pantalla; Mutes; Potes; Encoder; Control presets

Dept. Technical reference Created by Approved by

Title DWG No.

Document type Document status

Rev. Date of issue Sheet

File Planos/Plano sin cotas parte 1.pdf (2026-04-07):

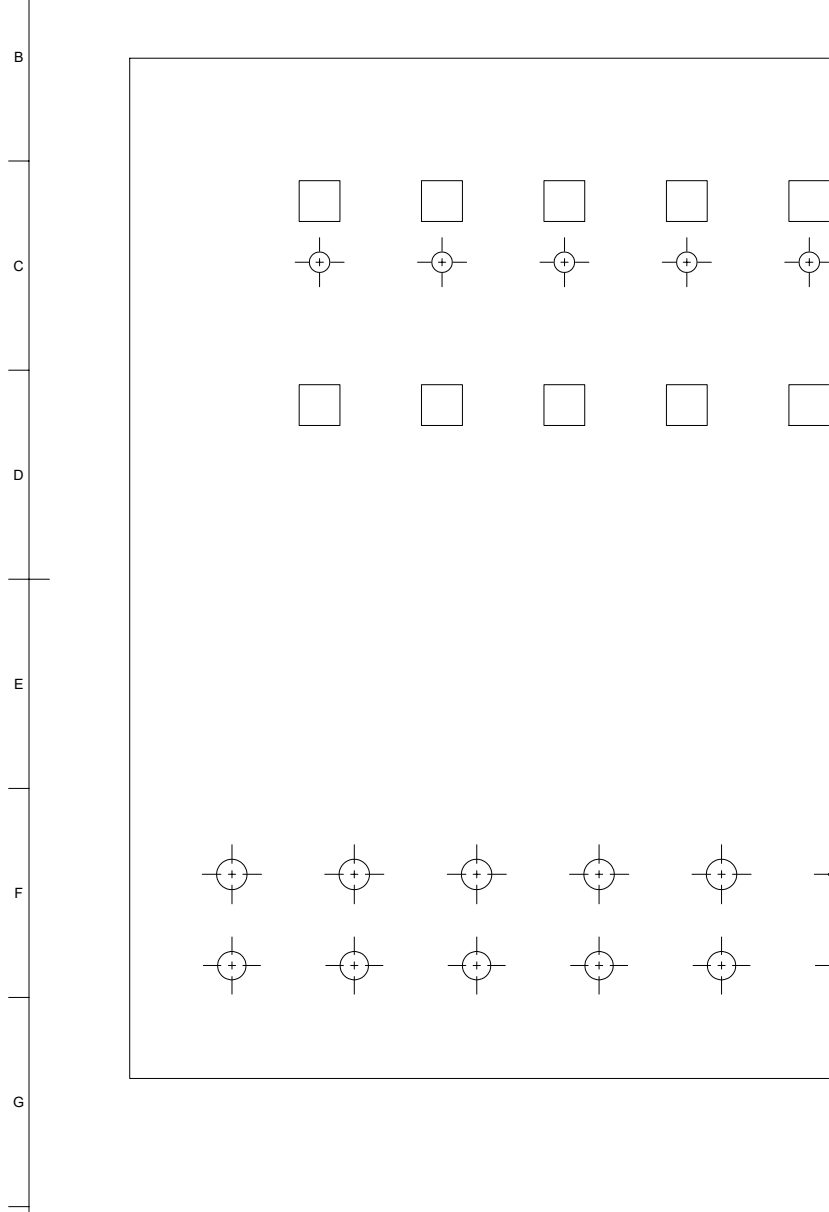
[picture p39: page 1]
BCDEFG

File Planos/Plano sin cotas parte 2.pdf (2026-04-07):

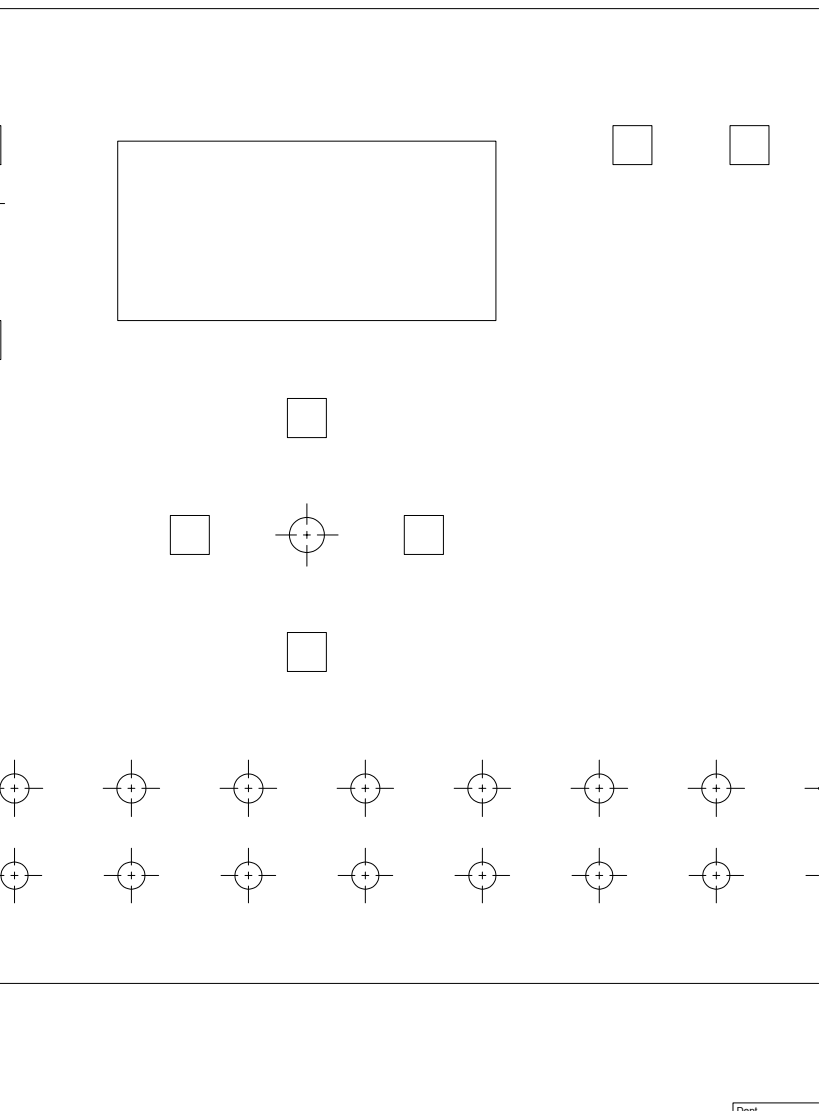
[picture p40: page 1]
Dept.

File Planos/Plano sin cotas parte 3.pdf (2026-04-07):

B

C

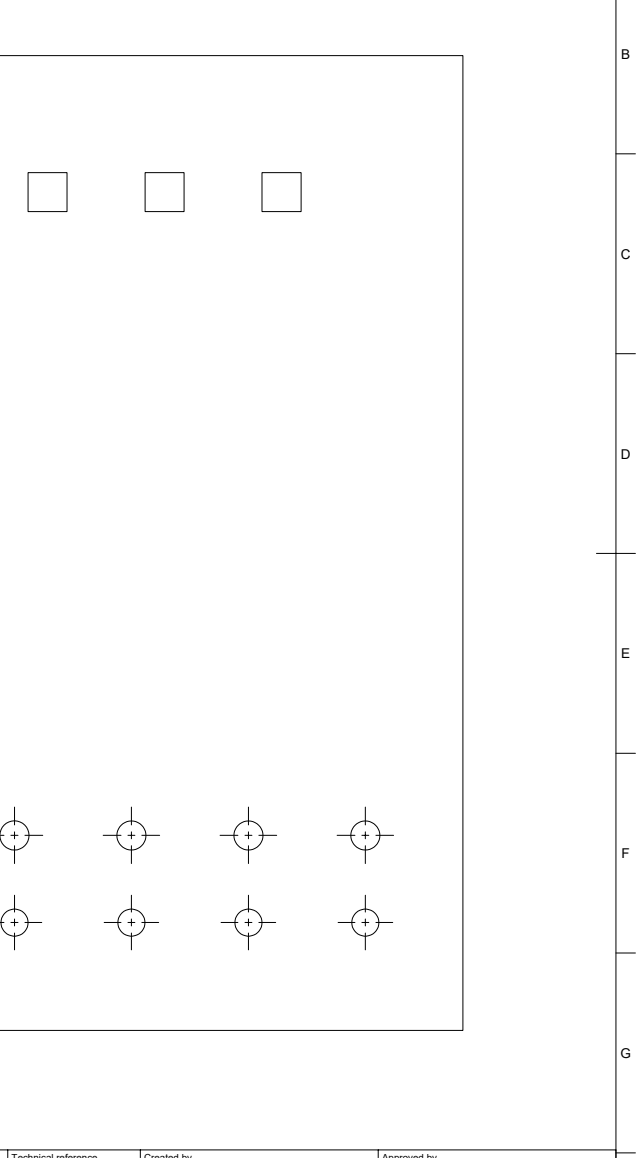
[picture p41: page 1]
Technical reference; Created by; Approved by

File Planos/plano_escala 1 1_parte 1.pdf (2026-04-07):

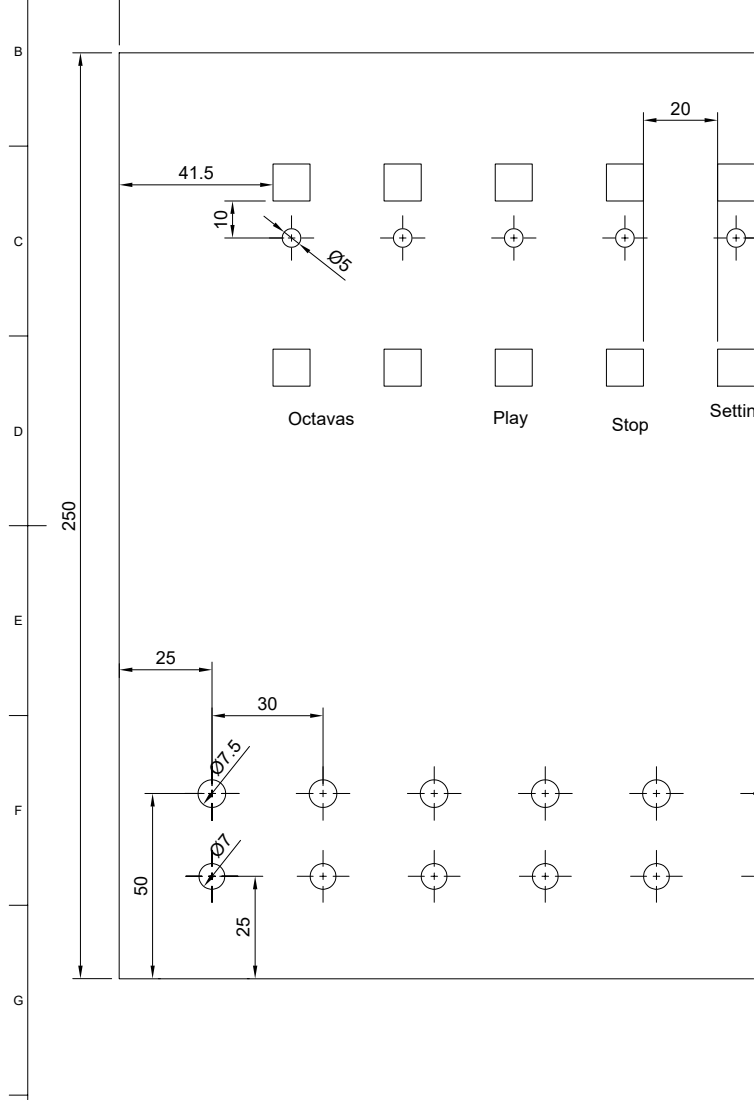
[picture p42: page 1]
Octavas; Play; Stop; Settin ³⁰

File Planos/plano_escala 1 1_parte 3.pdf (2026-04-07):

201.5

# esets

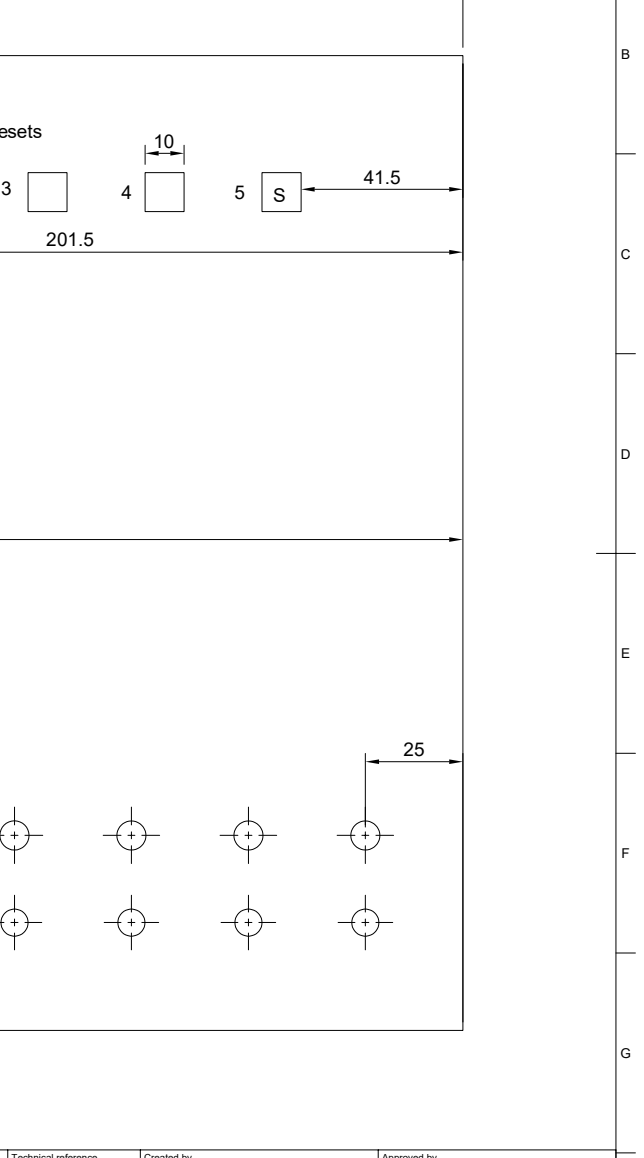
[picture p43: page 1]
Technical reference; Created by; Approved by

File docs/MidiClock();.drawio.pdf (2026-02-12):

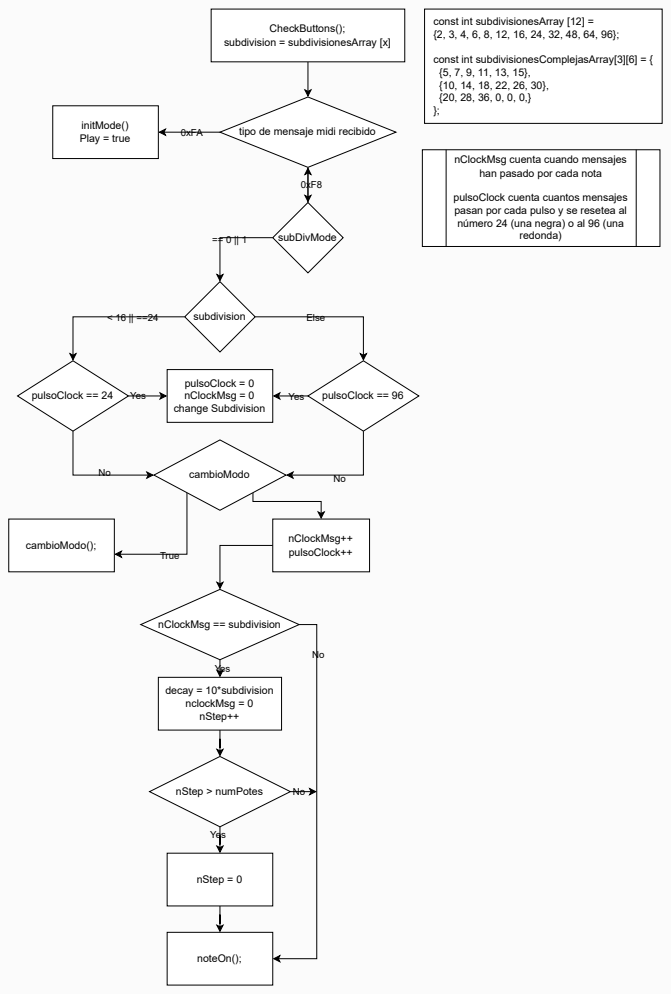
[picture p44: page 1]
CheckButtons(); subdivision = subdivisionesArray [x]; 0xFA; tipo de mensaje midi recibido; initMode() Play = true; subDivMode; subdivision; Else; Yes; pulsoClock == 96; pulsoClock == 24; pulsoClock = 0 nClockMsg = 0 change Subdivision; True; cambioModo; cambioModo();; nClockMsg++; pulsoClock++; nClockMsg == subdivision; decay = 10*subdivision nclockMsg = 0 nStep++; nStep > numPotes; nStep = 0; noteOn();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

const int subdivisionesArray [12] =

nClockMsg cuenta cuando mensajes
han pasado por cada nota

pulsoClock cuenta cuantos mensajes
pasan por cada pulso y se resetea al
número 24 (una negra) o al 96 (una

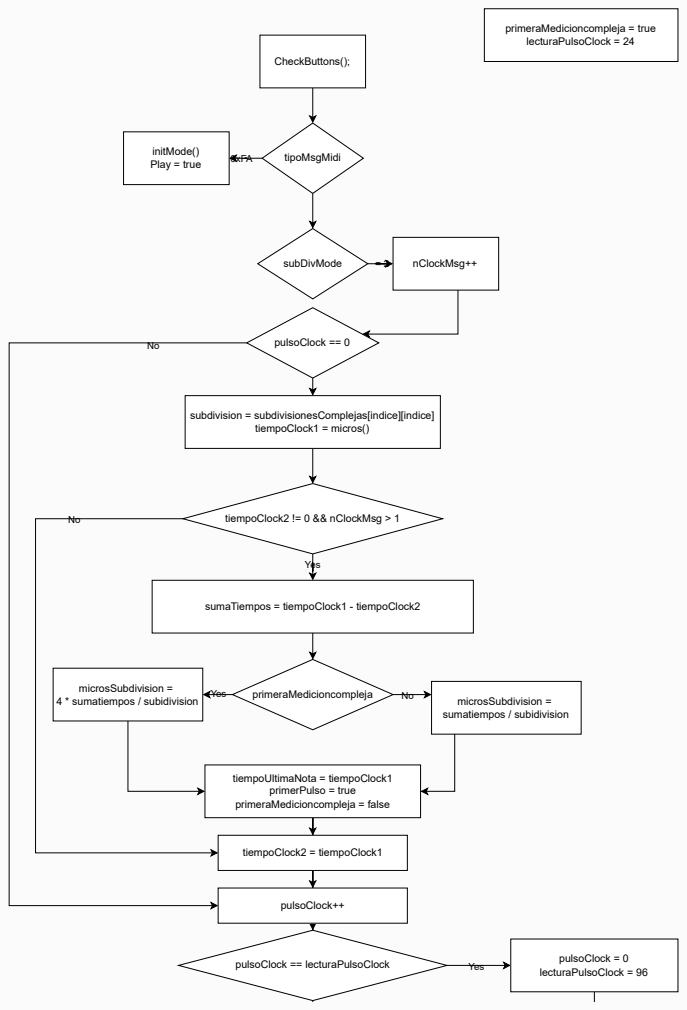
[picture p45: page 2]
CheckButtons();; 0xFA; tipoMsgMidi initMode(); Play = true; subDivMode; nClockMsg++; pulsoClock == 0; tiempoClock1 = micros(); Yes; tiempoClock2 != 0 && nClockMsg > 1; sumaTiempos = tiempoClock1 - tiempoClock2; primeraMedicioncompleja; microsSubdivision =; sumatiempos / subidivision; microsSubdivision = 4 * sumatiempos / subidivision; tiempoUltimaNota = tiempoClock1 primerPulso = true primeraMedicioncompleja = false; tiempoClock2 = tiempoClock1; pulsoClock++; pulsoClock == lecturaPulsoClock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

subdivision = subdivisionesComplejas[indice][indice]

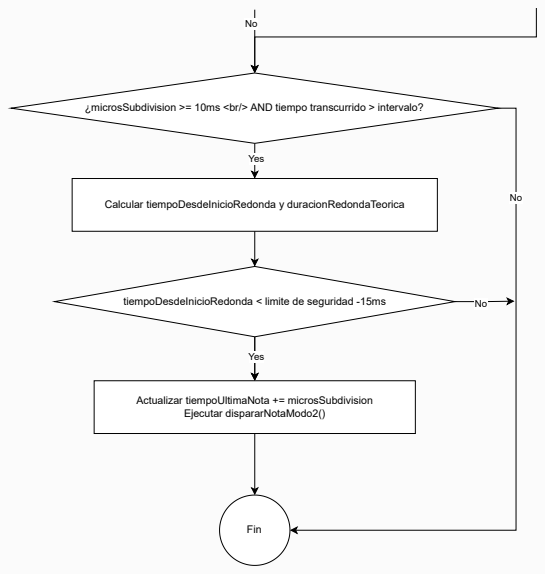
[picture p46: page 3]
Yes; Ejecutar dispararNotaModo2(); Fin

¿microsSubdivision >= 10ms <br/> AND tiempo transcurrido > intervalo?

Calcular tiempoDesdeInicioRedonda y duracionRedondaTeorica

tiempoDesdeInicioRedonda < limite de seguridad -15ms

Actualizar tiempoUltimaNota += microsSubdivision

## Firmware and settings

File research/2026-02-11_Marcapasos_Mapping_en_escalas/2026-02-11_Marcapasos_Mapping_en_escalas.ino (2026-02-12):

#include <LiquidCrystal.h>
#include <MIDI.h>
#include "midiPrograming.h"
#include "menus_buttons.h"
#include "midiInterface.h"

// Instancias librerias
LiquidCrystal lcd(8, 9, 7, 6, 5, 4);
MIDI_CREATE_CUSTOM_INSTANCE(HardwareSerial, Serial, MIDI, HairlessConfig);
// Pines
const byte pinButton1 = 22; // Arriba
const byte pinButton2 = 23; // OK / Entrar
const byte pinButton4 = 24; // Volver
const byte pinButton3 = 25; // Abajo
const byte pinButton5 = 27; // Izquierda
const byte pinButton6 = 29; // Derecha

const byte potesPin[8] = {A0, A1, A2, A3, A4, A5, A6, A7/*, A8, A9, A10, A11, A12, A13, A14, A15*/};

const byte mutesPin[8] = {30, 31, 32, 33, 34, 35, 36, 37};

// Valores potenciometros
const int numPotes = 8;
const int numMutes = 8;
int potesValue[numPotes]; //Valores detectados de los potes
bool mutesValue[numMutes] = {false, false, false, false, false, false, false, false};
int potSaveValue[numPotes]; //Valores guardados al haber una variacion con los detectados
int movedPoteValue;
int indiceMovedMute;
bool mutePulsado[numMutes] = {false, false, false, false, false, false, false, false};
bool mute;
int movedPoteNumber;
int nTotalSteps = 8;
int nStep;
int nStepAnterior;

// Carácteres
byte arrowLeft[8] = {B00001, B00011, B00111, B01111, B01111, B00111, B00011, B00001};
byte arrowRight[8] = {B10000, B11000, B11100, B11110, B11110, B11100, B11000, B10000};

byte redonda[8] = {B00000, B00000, B00000, B01110, B10001, B10001, B01110, B00000};
byte blanca[8] = {B00010, B00010, B00010, B00010, B01110, B10010, B10010, B01100};
byte negra[8] = {B00010, B00010, B00010, B00010, B01110, B11110, B11110, B01100};

byte stepOff[8] = {B00000, B00000, B00000, B01110, B00000, B00000, B00000, B00000};
byte stepOn[8] = {B00000, B01110, B10001, B10001, B10001, B01110, B00000, B00000};
byte stepPass[8] = {B00000, B01110, B11111, B11111, B11111, B01110, B00000, B00000};

// Variables lógica menús
int menuActual = 0;    // 0: Principal, 1: Menu 1, 2: Menu 2, 3: Screen Potes
int menuAnterior;
int seleccion = 1;     // 1 para Opción 1, 3 para Opción 2
bool updateLCD = true; // Variable para saber cuando redibujar
bool selectNum = false; //Si está seleccionando el numerador de las subdivisiones complejas
bool selectDen = false; //Si está seleccionando el denominador de las subdivisiones complejas

// Subdivisiones estandar
const char* subdivisionesCharArray [12] = {"12/1","1/8", "1/6", "1/4", "1/3","1/2", "3/2", "1/1", "3/4", "2/1", "3/8", "4/1"};
const int subdivisionesArray [12] = {2, 3, 4, 6, 8, 12, 16, 24, 32, 48, 64, 96};
bool primeraMedicionSubCompleja;

// Subdivisiones complejas
const int subdivisionesComplejasArray[3][6] = {
  {5, 7, 9, 11, 13, 15},
  {10, 14, 18, 22, 26, 30},
  {20, 28, 36, 0, 0, 0,}
};
const char* subdivisionesComplejasNumChar[6]{" 5"," 7"," 9","11","13","15"};
const byte subdivisionesComplejasDenChar[3]{byte(2),byte(3),byte(4)};

//Escalas y notas
int escalaSeleccionada = 1;
const int escalasNotas[5][13] = {
  {0, 1, 2, 3, 4, 5, 6, 7, 8, 9, 10, 11, 12}, //Escala cromática
  {0, 2, 3, 5, 7, 8, 10, 12, 0, 0, 0, 0, 0}, //Escala menor Natural
  {0, 2, 4, 5, 7, 9, 11, 12, 0, 0, 0, 0, 0}, //Escala Mayor
  {0, 2, 4, 6, 8, 10, 12, 0, 0, 0, 0, 0, 0}, //Escala de tonos
  {0, 1, 3, 4, 6, 7, 9, 10, 12, 0, 0, 0, 0} //Escala Semitono-tono
};
const int nNotasEscalas[5] = {13, 8, 8, 7, 9};
int octava = 4;


// Indices Navegación
int indiceSubdivisiones = 7;
int subDivMode = 0;
int indComplexSubdivX;
int indComplexSubdivY;

// Variables de tiempo real
unsigned long timeShowPotValue;
unsigned long timeShowOctValue;
unsigned long tiempoActualMillis;
unsigned long tiempoActualMicros;
unsigned long ultimoTiempoBotonMute[numMutes];
unsigned long TiempoPulsadoBotonMute[numMutes];
unsigned long ultimoTiempoBotonMenu;

// Gestion de MIDI y tiempo musical
int subdivision;
unsigned long int microsSubdivision = 500000000;
bool play;

void setup() {
  MIDI.begin(MIDI_CHANNEL_OMNI);
  MIDI.turnThruOff();
  //Botones Menus
  pinMode(pinButton1, INPUT);
  pinMode(pinButton2, INPUT);
  pinMode(pinButton3, INPUT);
  pinMode(pinButton4, INPUT); 
  pinMode(pinButton5, INPUT);
  pinMode(pinButton6, INPUT);

  //Botones Mutes
  /*
  for(int i = 0; i < numMutes; i++){
    pinMode(mutesPin[i], INPUT);
  }
  */
  for(int i = 0; i < numMutes; i++){
    pinMode(mutesPin[i], INPUT);
  }

  // Primera lectura potes
  for(int i = 0; i < numPotes; i++){
    int lectura = analogRead(potesPin[i]);
    potesValue[i] = constrain(map(lectura, 1018, 8, 48, 60), 0, 127);
    potSaveValue[i] = potesValue[i];
  }
  // Creación caracteres e inicio de la pantalla
  lcd.createChar(0,arrowLeft);
  lcd.createChar(1,arrowRight);
  lcd.createChar(2,redonda);
  lcd.createChar(3,blanca);
  lcd.createChar(4,negra);
  lcd.createChar(5,stepOff);
  lcd.createChar(6,stepOn);
  lcd.createChar(7,stepPass);
  lcd.begin(16, 2);
}

void loop() {
  tiempoActualMillis = millis();
  tiempoActualMicros = micros();
  checkButtons();
  checkPotes();
  checkMutes();

  if (MIDI.read()){
    midiClock();
  }
  midiNotesOn();
  midiNotesOff();


  // Reset pantalla
  if(menuActual == 0 && seleccion == 5){
    if(nStep != nStepAnterior){
      updateLCD = true;
      nStepAnterior = nStep;
    }
  }
  if (updateLCD) {
    lcd.clear();
    if (menuActual == 0) drawMenuPrincipal();
    //else if (menuActual == 1) drawMenu1();
    //else if (menuActual == 2) drawMenu2();
    else if (menuActual == 3) drawScreenPotes();
    else if (menuActual == 4) drawScreenMutes();
    updateLCD = false; 
  }

  // Clock para salir de la pantalla de potenciómetro
  if (menuActual == 3 && (tiempoActualMillis - timeShowPotValue >= 1500)) {
    menuActual = menuAnterior;
    updateLCD = true;
  }
  else if (menuActual == 4 && (tiempoActualMillis - timeShowOctValue >= 1500)) {
    menuActual = menuAnterior;
    updateLCD = true;
  }
  sumaStep();
}
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

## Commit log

2026-02-12 Errores con gitignore
    errores en la subida y con gitIgnore
    [PlanosFirtzing.fzz, Untitled Sketch.fzz]
2026-02-19 Add v1.3 and refactor LCD/menu & MIDI headers
    Introduce a v1.3 build and research variant while refactoring LCD/menu and MIDI logic into separate headers. Added draw_menus.h, menus_buttons.h, midiInterface.h and midiPrograming.h and new .ino files (src/MarcaPasos_v1.3 and research/MarcaPasos_mutes_to_select) to extract display drawing and button handling from the main sketch. Implement per-step octaves, scale-aware pot mapping, complex subdivision handling, mute interaction (including octave adjustments), and custom LCD characters. Added a changelog (log.txt), removed release.bat, and applied a small whitespace fix in src/MarcaPasos_v1.2/midiInterface.h; syncMemories.py was also updated.
2026-02-25 Update project title to 'THE ARDUINO MIDI SEQUENCER'
2026-02-25 Reorganize research files; add velocity experiment
    Move many research sketches and library files into dated subfolders for better organization; relocate two MIDI reference PDFs into docs. Remove the automatic release workflow and delete a large video asset to reduce repo noise. Add new MarcaPasos velocity experiment (research/2026-02-24_MarcaPasos_Velocity) and supporting files, plus helper scripts (fecharCarpetas.bat and scripts/fecharCarpetas.ps1). Rename/move a scripts file and update src/MarcaPasos_v1.3/midiInterface.h.
    [2026-01-17_Arduino With Sublime.ino, 2026-01-17_Basic_MIDI_receive.ino, 2026-01-18_Timer_and_potes.ino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]
2026-02-26 Refactor pot/note handling; add noise control demos
    Rename and refactor potentiometer handling: potesValue was renamed to notesValue and potSaveValue is now used as the raw analog baseline. Movement detection thresholds were tightened and velocity handling separated from note selection (velocity uses mapped raw pot values; notes use scale-mapped values). Introduced poteMovidoMutes to distinguish mute-driven pote movement, and added lastNTotalSteps to optimize drawSteps rendering.
    UI and behavior updates: draw_menus and menus_buttons updated to account for notesValue and new step-count logic; drawSteps now updates only when nTotalSteps changes. Minor fixes in mute/step drawing and menu navig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
    [2026-02-19_MarcaPasos_mutes_to_select.ino, 2026-02-26_control_de_ruido_de_los_potes.ino]
2026-02-27 Add C++ refactor of MarcaPasos and tooling
    Introduce a C++ restructuring of the MarcaPasos project and supporting scripts. Adds new modular files under research/MarcaPasos_reestructuracion_cpp: main .ino, DrawMenus (draw_menus.cpp/.h), MenusB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
2026-03-01 Add MarcaPasos MIDI clock OOP refactor
    Introduce a refactored MarcaPasos MIDI clock project (version 1.5) migrated to an object-oriented structure. Adds main sketch (MarcaPasos_midiClock_incorporated.ino) plus classes and implementations 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
2026-03-03 Add MarcaPasos v1.7 project files
    Add complete MarcaPasos v1.7 Arduino MIDI sequencer sources and supporting files. Includes main sketch (MarcaPasos_v1.7.ino), LCD/menu drawing (draw_menus.cpp/.h), menu/button handling (menus_buttons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
2026-03-03 fechado de carpetas
    fechado de carpetas
2026-03-11 Add docs, research sketches, and v1.7 sources
    Add multiple documentation and Moodle-ready HTML files (README_PARA_MOODLE.html, README_SIMPLE.html, TODO_PARA_MOODLE.html) and a simple interpolacion.py helper. Add many research sketches, variants 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
2026-03-15 Add v1.8 & research sequencers; remove READMEs
    Add new v1.8 release and multiple research branches: introduces refactored menu and sequence implementations (many .ino, .cpp, .h under research/ and src/MarcaPasos_v1.8), plus release ZIPs and a ful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
2026-03-15 Add MarcaPasos v1.8 FULLCODE and rename v1.7
    Rename existing fullcode file for v1.7 to MarcaPasos_v1.7.0_FULLCODE.txt and add a new MarcaPasos_v1.8_FULLCODE.txt containing the full v1.8 Arduino project (LCD, MIDI, timer, menus, presets, MIDI pr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
2026-03-22 New Archives
    New Archives
    [Encoder.f3d, KY-040 (M495) - Rotační enkodér s ptlačítkem.SLDPRT, KY-040 - Rotační enkodér s tlačítkem, 20pulz_ot..SLDASM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]
2026-03-24 Add CC Visualizer module, v1.8.2 sources & plans
    Introduce a new CC visualizer Arduino project and release files: adds research/MarcaPasos_CCVisualizer (sketch, LCD UI, menu/button handling, MIDI interface, presets, CC interpolation/math, config an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
2026-04-07 Add MarcaPasos variants, SdFat lib, and assets
    Add many project assets and research code: multiple MarcaPasos variants (MoreSequences, presets_save, ultimasConfiguraciones), new src releases v1.9 and v1.9.1, numerous plan PDFs/images and docs ass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
2026-04-09 Add MarcaPasos v1.9.2 and slot extension
    Introduce new MarcaPasos sources: adds a research 'slot' extension (research/MarcaPasos_slot_made_extension) with main .ino, config, LCD menu drawing, settings UI, MIDI interface/presets, MIDI progra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
2026-04-11 Refactor menus, MIDI/pot handling; add v1.10.0
    Replace hardcoded sizes and debounce values with constants (N_MAX_SEQS, N_MAX_STEPS, DEBOUNCE_DELAY_MS) and add config.h. Introduce poteBlocked logic and robust pot-change handling to avoid spurious updates, improve pot-to-value mappings and name-char calculation. Clean up draw_menus logic (switch statements, ternaries, simplified LCD writes, CC visualizer), fix step/LED drawing and screen refresh conditions. Ensure octave updates affect both main and extension sequences; reset subdivision/clock state when toggling extensions. Add the v1.10.0 source tree and a full-code export script.
2026-04-11 Refactor LCD menu drawing and preset slot handling
    Rename preset button handler and refactor menu/drawing code for readability and correctness. Changes include:
    - Rename MidiPresets::readPresetsButtons() to readSlotsButtons() and update declaration and call sites.
    - Major reformat and cleanup of DrawMenus: rework constructor initializer formatting, group and relocate character creation functions, add utility drawing helpers (drawMutes, drawSteps), unify/update static screen rendering, and introduce/restore ephemeral screens (pote/octave views). Many small whitespace/formatting fixes and minor logic adjustments to drawing and cursor handling to improve stability and maintainability.
    - Add sma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
2026-04-12 Refactor UI drawing and MIDI/button logic
    Large refactor and bugfixes to menu/UI drawing and MIDI/button handling. Changes include: renamed and reorganized draw functions (staticScreen1/2/3 -> staticScreenNotes/CC/Settings), consolidated and clarified draw helpers (drawStaticSteps, drawMutes, drawCCMutes, drawCCVisualizer) and improved drawSteps to avoid unnecessary redraws and fix index off-by-one. Renamed input handlers (checkButtons -> checkMenuButtons, checkMutes -> checkMidiButtons), added debounce/flag logic improvements, clarified pot/mute/octave handling (use of ultimoTiempoBotonOct, improved mute/pote state transitions), and fixed menu selection indexing and other small navigation b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
2026-04-13 Refactor DrawMenus & menu/midi UI handling
    Large refactor of the LCD/menu drawing and related UI code: reorganized DrawMenus class (chars, state, helpers), renamed and split menu/midi checks (checkMenuButtons, checkMidiButtons, readSlotsButtons), switched loops to use N_MAX_SEQS, and cleaned up many print/write helpers and custom-char handling. Improved step/mute/CC drawing: separated static vs dynamic drawing (staticScreenNotes/CC/Settings, drawStaticSteps, drawMutes, drawSteps, drawCCMutes), added clearer comments and formatting, and reworked CC visualizer and curve calculation (calcularCurvaParaPantalla signature and logic) for better resolution handling. Misc: API/formatting changes, var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
2026-04-13 Refactor MIDI sequencing and CC handling
    Reorganize and clean up MIDI sequencing code: extract and relocate initMode, add clearer section headers and comments, and restructure modo01Subdivision/modo2Subdivision logic to improve timing, mode switching and jitter handling for complex subdivisions. Add dispararNotaMode2 and clarify midiNotesOn/midiNotesOff behavior (decay calculation, note firing and step advancement). Refactor CCSend: robustly find previous/next non-muted steps, compute offsets/subdivisions safely (avoid divide-by-zero), and compute per-subdivision CC interpolation using a moved/implemented ccCurveFunction that reads curve lookup from flash. Minor comment/header tweaks in draw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
2026-04-15 Support extension sequences; transport & UI tweaks
    Initialize and support per-sequence extension fields (ext_*), add API to get a played sequence, and refactor MidiProgramming to operate on sequences by id and extension flag. Introduce MidiProgramming::initValues and use a deviceFlagPlay transport flag to coordinate start behavior; ensure devicePlay is set on start and cleared on stop. Add a new "Reset Input Note" settings entry and menu handling (including action to clear notaExterna), update CC sending to use the sequence pointer, and apply small LCD/draw-menu formatting fixes. Also add multiple new docs assets and remove an obsolete ZIP file.
2026-06-01 Add v1.10.3, research code and media assets
    Add MarcaPasos v1.10.3 source and a large set of research sketches (Cambios_de_pines, MarcaPasos_Optimizacion_LCD, MarcaPasos_Optimizacion_LCD_2, MarcaPasos_Cambios_de_pines, etc.) including draw_men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
2026-06-01 Add CHANGELOG v1.10.3 for MarcaPasos
    Add src/MarcaPasos_v1.10.3/log.txt containing the detailed changelog for v1.10.3 (vs 1.10.2). Highlights include: increased sequencer capacity to 16 steps and expanded controls (16 pots/mutes); pin reassignments for save and quick slots and encoder pin change; LCD optimizations (avoid redundant custom char loads, faster line clearing, improved octave layout); new "Ver Secuencia" settings menu and enforced preset value syncing; Timer1 interrupt validation and RAM/consolidation/performance cleanups.
2026-08-11 Add PPTX/ZIP; tidy comments and logs
    Add presentation and release ZIP (El_Marcapassos_MIDI_Sequencer.pptx, MarcaPasos_v1.10.3.zip) and apply minor cleanups across the codebase: standardize and clarify section comments in MarcaPasos_v1.1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
2026-08-11 Add MarcaPasos v1.10.4 Arduino project
    Add complete MarcaPasos v1.10.4 project sources and assets. Includes main sketch (MarcaPasos_v1.10.4.ino), configuration, LCD/UI drawing (draw_menus.*), menu/settings screens, MIDI interface and prog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
2026-08-11 Align step count display in menus
    Ensure curTotalSteps is printed at a fixed column with a leading space for single-digit values to maintain alignment. Replaced direct printAt(...) calls with lcd.setCursor(17, 0), conditional padding (printAt(17, 0, " ")) and lcd.print(curTotalSteps) in drawMenuNotes, staticScreenNotes, drawMenuCC and staticScreenCC. Also updated the packaged MarcaPasos_v1.10.4.zip binary.
2026-08-14 1.11.0
    *******************************************************************************
    * CHANGELOG - MarcaPasos v1.11.0 *
    * Basado en cambios desde la versión 1.10.4 *
    *******************************************************************************
    [NUEVO ECOSISTEMA: MarcaApp v1.0.0]
    - Aplicación de Escritorio: Se ha desarrollado una interfaz gráfica en Python
    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
